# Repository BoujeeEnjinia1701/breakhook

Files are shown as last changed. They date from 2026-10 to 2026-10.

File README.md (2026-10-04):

# BreakHook

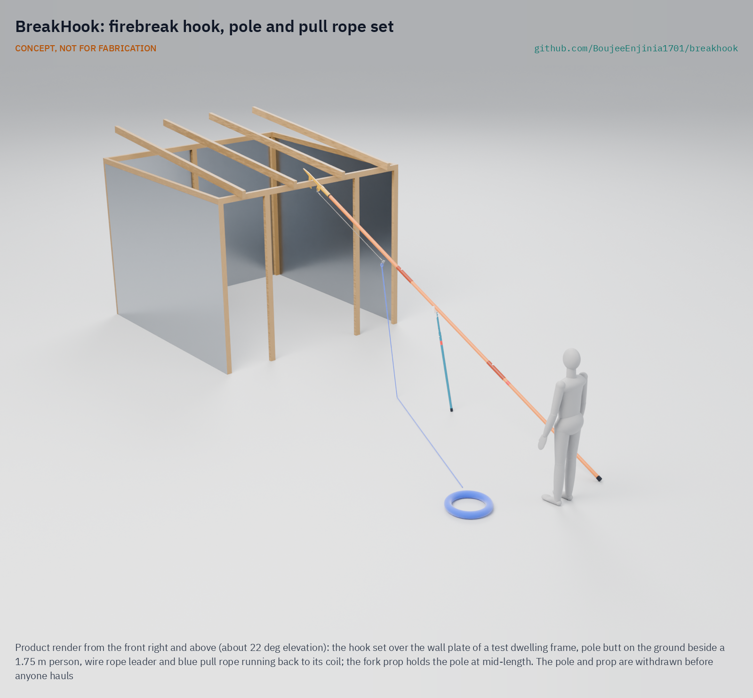
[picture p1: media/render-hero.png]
BreakHook: firebreak hook, pole and pull rope set


     

**Area:** Situational field hardware · **TRL:** 3 of 9 (proof of concept on paper; constructable design) · **Value-engineering target:** USD 2,000; estimated kit cost USD 1,170 · **Difficulty:** 2 of 5

Lets residents pull a shack down from a safe distance to open a firebreak before a fire jumps across.

## Concept rationale

Pulling buildings down to stop a fire is an old method: in 1666 the Mayor of London was ordered to use fire hooks to pull down burning buildings ([London Fire Brigade Museum](https://www.london-fire.gov.uk/museum/london-fire-brigade-history-and-stories/fires-and-incidents-that-changed-history/the-great-fire-of-london/)). Residents of informal settlements do the same today, tearing down structures to make firebreaks ([Ngau and Boit, 2020](https://journals.sagepub.com/doi/10.1177/0956247820924939)). BreakHook gives them the tool for it: a long-reach steel hook on a non-conductive pole with a pull rope. The hook is set on a roof beam or wall frame from a distance, then a group hauls on the rope from well back to bring the structure down.

The value is distance. With a hook and rope, the people pulling stand clear of the fall zone and further from the heat. The kit is simple enough to keep at a community point, needs no power or water, and can be built by a local welder. It is meant as a last-resort tool inside a community fire plan, not a replacement for fire services, detectors or better spacing.

## Burning platform

Stellenbosch University fire engineers report that fires in Cape Town's informal settlements cause up to 115 deaths and destroy up to 4,500 dwellings a year, and that fire can spread between dwellings in under a minute ([Stellenbosch University, 2023](https://www0.sun.ac.za/researchforimpact/2023/10/10/su-fire-engineers-explore-risks-for-humans-and-dwellings/)). The 2017 Imizamo Yethu fire destroyed 2,194 dwellings and displaced more than 9,700 people, despite more than 170 firefighters working for over 13.5 hours ([Imizamo Yethu fire spread analysis](https://www.sciencedirect.com/science/article/abs/pii/S2212420918307623)).

Help often arrives late. A study of Dhaka and Cape Town found average fire service response times of 68 minutes in informal settlements against 28 minutes in formal residential areas, and pathways as narrow as 60 to 90 cm in parts of Dhaka ([Royal Academy of Engineering](https://engineeringx.raeng.org.uk/media/03cd1j4l/engx-a-comparative-study-of-fire-risk-emergence-in-informal-settlements-in-dhaka-and-cape-town-short.pdf)). In Nairobi, over 60 % of surveyed residents said they took part in fire response, including tearing down structures to create firebreaks ([Ngau and Boit, 2020](https://journals.sagepub.com/doi/10.1177/0956247820924939)).

## Where it could be used

### By industry

| Industry | Use |
| --- | --- |
| Community-based disaster risk reduction | A firebreak tool in a community fire kit alongside buckets, extinguishers and alarms |
| Municipal fire services | Equipment for trained community reservists who act before engines arrive |
| Humanitarian shelter and settlement programmes | Pre-positioned kit in dense camps and settlements |
| Red Cross and Red Crescent societies | Part of community fire response training |
| Urban upgrading and re-blocking programmes | Interim measure while spacing and access are improved |

### By country or region

| Country or region | Why it matters there |
| --- | --- |
| South Africa (Western Cape) | Up to 115 deaths and 4,500 dwellings lost to informal settlement fires in Cape Town each year ([Stellenbosch University, 2023](https://www0.sun.ac.za/researchforimpact/2023/10/10/su-fire-engineers-explore-risks-for-humans-and-dwellings/)). |
| South Africa (national) | A Khayelitsha New Year fire destroyed more than 1,000 shacks and displaced over 4,000 people; the city responded with re-blocking to create 3 m gaps ([The New Humanitarian, 2013](https://www.thenewhumanitarian.org/analysis/2013/01/23/south-africa-searches-solutions-shack-fires)). |
| Kenya | In Nairobi's informal settlements, residents tear down structures to create firebreaks while fire engines struggle with narrow access ([Ngau and Boit, 2020](https://journals.sagepub.com/doi/10.1177/0956247820924939)). |
| Bangladesh | The 2017 Korail fire in Dhaka destroyed 4,000 dwellings and displaced about 20,000 people ([Royal Academy of Engineering](https://engineeringx.raeng.org.uk/media/03cd1j4l/engx-a-comparative-study-of-fire-risk-emergence-in-informal-settlements-in-dhaka-and-cape-town-short.pdf)). |

## What sparked the idea

The idea came from two findings read side by side. Stellenbosch fire engineers found that fire can cross from one informal dwelling to the next in under a minute ([Stellenbosch University, 2023](https://www0.sun.ac.za/researchforimpact/2023/10/10/su-fire-engineers-explore-risks-for-humans-and-dwellings/)), while a study in Nairobi found that residents already respond by tearing down structures to make firebreaks, with over 60 % taking part in fire response ([Ngau and Boit, 2020](https://journals.sagepub.com/doi/10.1177/0956247820924939)). People are already doing the one thing that works in those first minutes, with their bare hands, next to the fire.

## Problem

In dense informal settlements, fire can jump from one dwelling to the next in under a minute, long before fire engines arrive. Residents already pull structures down to stop it, but they do it by hand, close to the flames.

Full problem statement: [docs/01-problem.md](docs/01-problem.md)

## Concept

A long-reach steel hook on a non-conductive pole with a pull rope; residents set it on a shack's roof beam or wall frame from a safe distance and haul together to pull the shack down, opening a firebreak ahead of a spreading fire.

Full design precis: [docs/02-concept.md](docs/02-concept.md) · Requirements: [docs/03-requirements.md](docs/03-requirements.md) · Calculations: [docs/04-calcs/01-sizing.md](docs/04-calcs/01-sizing.md) · Prototype build plan: [docs/05-build-plan.md](docs/05-build-plan.md) · Design decisions: [docs/06-design-decisions.md](docs/06-design-decisions.md) · General arrangement: [cad/drawings/BHK-DWG-001.pdf](cad/drawings/BHK-DWG-001.pdf) · 3D model: [media/viewer.html](media/viewer.html)

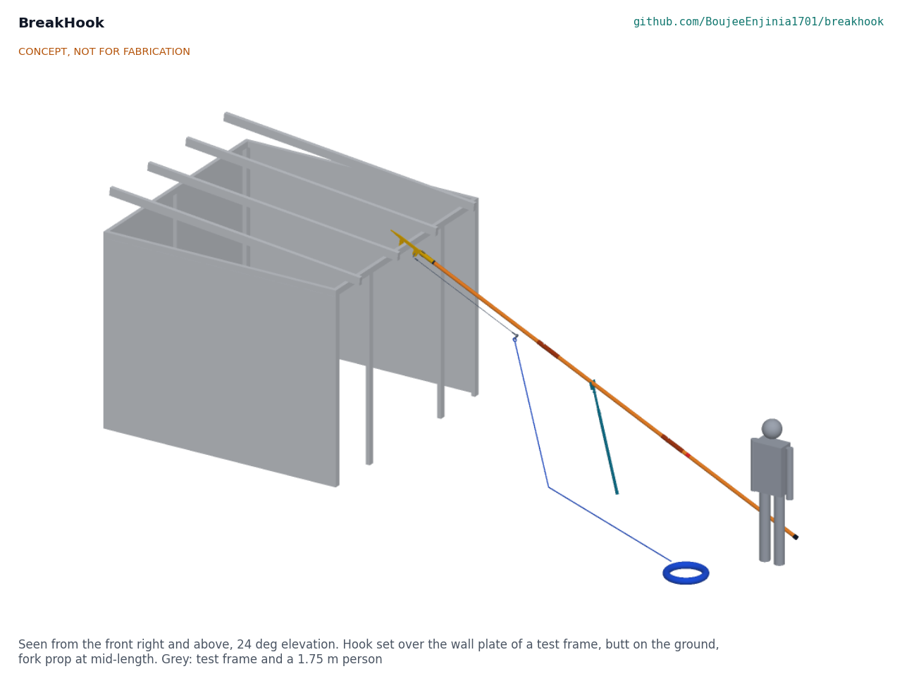
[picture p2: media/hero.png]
Concept: the hook set over the wall plate of a test frame, 1.75 m person for scale


Key figures at TRL 3 (BHK-CAL-001): working pull 3 kN with every hook head proof-loaded to 6 kN; about ten haulers, the nearest 10.8 m from the wall; pole and hook head 7.82 kg; 3.67 m of insulated pole below the hook head; deployment in about 3 minutes from a store within 100 m. The fibreglass pole rests on a light fork prop at mid-length while the hook is set, which cuts the droop at the hook from about 0.66 m to 0.27 m; placement is the main thing a TRL 4 trial must confirm.

## Key components

- Hook head: profile-cut 10 mm steel plate welded into a slotted steel socket
- Non-conductive pole: three 1.8 m sections of foam-filled, certified fibreglass tube with bonded sleeves and nylon pins
- Wire rope leader and rated shackles
- Pull rope: 25 m of 12 mm polyester with ten hauling toggles on prusik cords
- Fall zone tape and stakes
- Locked, sealed wall rack
- Check card and rigger gloves

## Building the prototype

The first prototype is one set and its rack, built by a local welder and a small workshop: the hook plate is cut from 10 mm steel and welded into a slotted socket, the fibreglass pole sections are cut, drilled and joined with glued sleeves and nylon pins, and the rope system is bought from a rigging shop. Every component has a making sketch and every assembly step a picture. Each hook head is proof-loaded to 6 kN before it is issued. The plan is a plan, not yet built; building and testing to it is TRL 4 work.

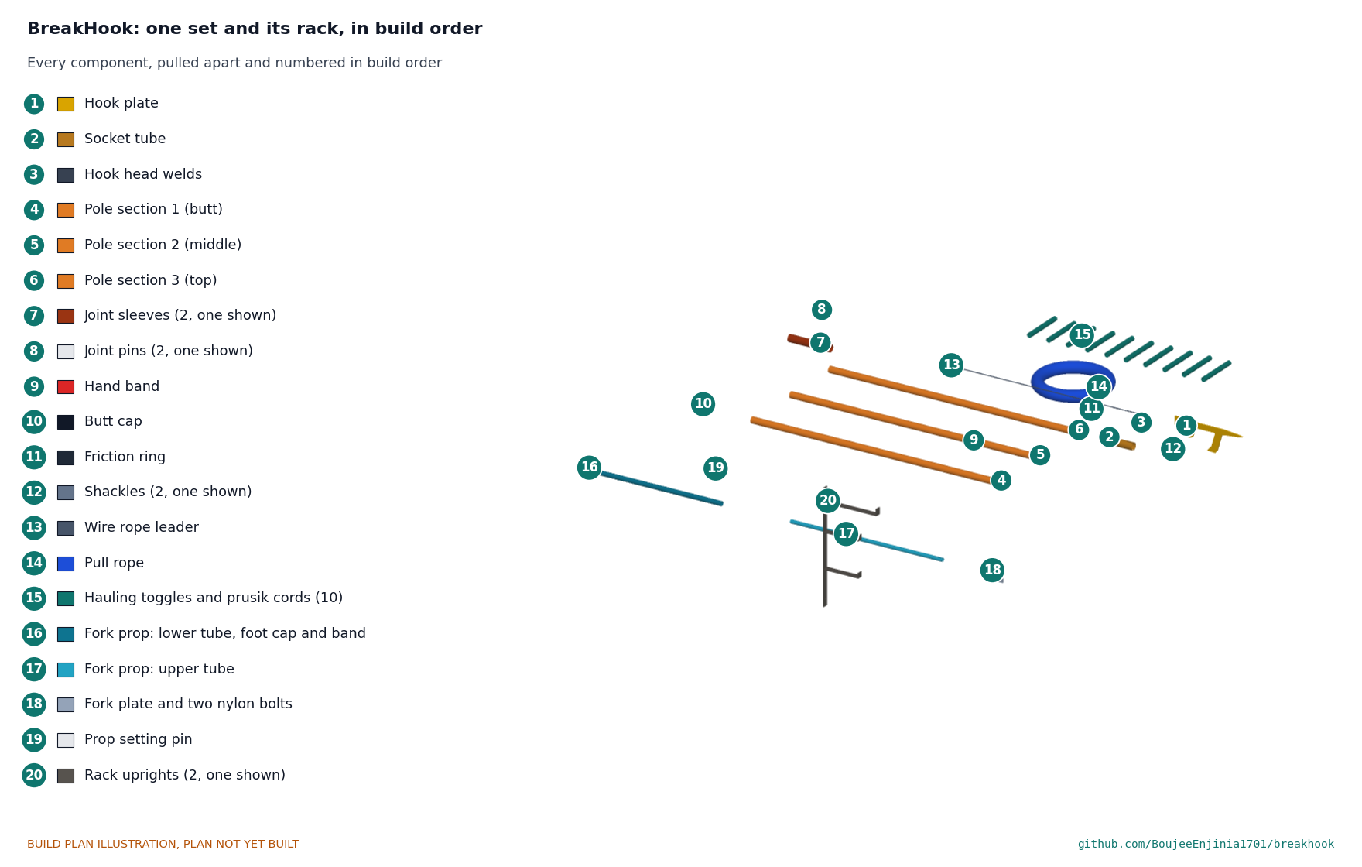
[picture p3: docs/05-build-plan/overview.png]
Every component, pulled apart and numbered in build order


## Safety

> Published as an open engineering reference, not certified equipment. Use only within a community fire plan agreed with the local fire service.
>
> Never pull a structure until two people have confirmed it is empty of people and animals.
>
> Never raise the pole within 3 m of any overhead or informal electrical line. The pole's insulated length is a second line of defence only; the hook, leader and shackles are metal and a wet rope conducts.
>
> Withdraw the pole and leave the fall zone before anyone hauls. Haulers stand at least 10 m from the wall and at least 1.5 times the structure's height away, on the side away from the fire, in gloves.
>
> Proof-load every hook head, leader and shackle set to 6 kN before issue and after any seal break; take a bent, kinked or frayed part out of service.
>
> Use only on free-standing, single-storey dwellings or end units, never on shared-wall rows, multi-storey or masonry buildings.
>
> Pulling a home down destroys it. The decision belongs to the community and its fire plan, not to the tool.
>
> This design is published as an open engineering reference. It is a TRL 3 concept, not for fabrication, and it is not certified equipment.

## Repository layout

| Folder | Contents |
| --- | --- |
| `docs/` | Problem, concept, requirements, calculations and design decisions |
| `cad/src/` | build123d Python source, the source of truth for all geometry |
| `cad/step/`, `cad/stl/` | Exported models for FreeCAD, other CAD tools and printing |
| `cad/drawings/` | 2D sketches and dimensioned drawings |
| `bom/` | Bill of materials |
| `electronics/` | KiCad schematics and PCB layouts |
| `firmware/` | Microcontroller code |
| `media/` | Renders, perspectives and photos |
| `build-log/` | Dated prototyping notes |

## Documentation

Controlled documents follow the portfolio [documentation standard](.kit/STANDARDS.md). Each carries a document ID (BHK-PRC-001 for the precis), a version and a revision history. Branded PDFs are built with `python .kit/render.py` and attached to GitHub Releases when a document is tagged, for example `BHK-PRC-001/v1.0`.

## Credits

Designed by Amish Chadha at Design Molecule Labs. See [CONTRIBUTORS.md](CONTRIBUTORS.md) for roles. To cite this design, use [CITATION.cff](CITATION.cff) (GitHub shows it as "Cite this repository").

AI assistance (Claude) was used to accelerate prototype documentation and first-pass research. Design direction and all decisions are Amish Chadha's, recorded in this repository's decision records (`docs/decisions/`).

## Licenses

- **Hardware** (CAD, drawings, BOM, electronics): [CERN-OHL-S v2](LICENSE)
- **Software** (firmware, scripts, notebooks): [MIT](LICENSE-SOFTWARE)

A project of the [Design Molecule](https://designmolecule.com) lab.

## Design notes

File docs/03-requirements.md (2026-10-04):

---
doc_id: BHK-REQ-001
title: BreakHook requirements
project: BreakHook
doc_type: Requirements
version: "0.5"
status: Draft
date: '2026-10-03'
author: Amish Chadha
license: CERN-OHL-S-2.0
revisions:
- version: "0.1"
  date: '2026-09-30'
  author: Amish Chadha
  change: Initial scaffold
- version: "0.2"
  date: '2026-10-03'
  author: Amish Chadha
  change: TRL 2 and TRL 3; targets confirmed under Amish's 2026-10-03 pre-approval (BHK-DDR-001); R11 to R14 added; status from BHK-CAL-001
- version: "0.3"
  date: '2026-10-03'
  author: Amish Chadha
  change: 'Fork prop at mid-length added under Amish''s decision 6A (BHK-DDR-003); status of R1, R5, R8, R10 and R14 updated from BHK-CAL-001 v0.2; targets unchanged'
- version: "0.5"
  date: '2026-10-03'
  author: Amish Chadha
  change: "R1 stand-off wording restated after Amish's round-2 decision 5A (BHK-DDR-004): prop holder at 2.9 m during placement only; confirmed in the TRL 4 reach trial"
---

# BreakHook requirements

Fourteen requirements, each with a measurable target. At TRL 3 they are checked by calculation (BHK-CAL-001); verification by test is TRL 4 work. Ten are met on paper; R1's hook placement is met with the fork prop, and the prop holder's 2.9 m placement-only stand-off is accepted by Amish (the TRL 4 reach trial confirms it); R6 and R13 are met with no margin, and R7 and R9 can only be shown by trial.

On 2026-10-03 Amish chose option A on every requirement decision put to him ("1A 2A 3A 4A 5A 6A 7A 8A 9A 10A 11A"). For BreakHook, decision 6A adds a light fork prop that supports the pole at mid-length, carried separately so the pole and hook head stay under 8 kg (BHK-DDR-003). No target changes.

> **Safety:** BreakHook pulls a structure down with a rope. Every requirement assumes the safety rules of BHK-PRC-001: the dwelling is checked empty, the fall zone is clear and taped, nobody is within 3 m of an overhead line, and the pole is withdrawn before the haul. A requirement is never met by relaxing those rules.

Table 1. Requirements

| ID | Requirement | Target | Verification (TRL 4 or later) | Status at TRL 3 |
| --- | --- | --- | --- | --- |
| R1 | Reach of the hook | Places the hook at a height of 3 m (10 ft) with the pole hands (front hand) 4 m (13 ft) from the wall; the prop holder may stand 2.9 m from the wall during placement only (about 25 s) and withdraws with the pole before the haul | Reach trial on the test frame, with the prop holder's distance from the wall and the time at 2.9 m measured | Hook placement met on paper with the fork prop at mid-length: droop about 0.27 m (0.66 m by hand), rear hand 5.06 m from the wall (CAL [F13] to [F20]); the prop holder stands about 2.9 m from the wall for the placement only (about 25 s), accepted by Amish (5A, round 2), and withdraws with the pole; the TRL 4 reach trial confirms it |
| R2 | Hook and rope working pull | 3 kN (675 lbf) working, every hook head proof-loaded to 6 kN (1,350 lbf) before issue | Proof load with CalRig or at a rigging shop | Met: least factor 2.3 on yield at proof (CAL [C3]) |
| R3 | Hauling distance | Nearest hauler at least 1.5 times the structure height from the wall, and never closer than 10 m | Field layout check | Met: 10.8 m (CAL [B1]) |
| R4 | Pole electrical insulation | The handled length is foam-filled fibreglass carrying the maker's dielectric test certificate to ASTM F711 for live-line tool tube | Certificate check on receipt; no field electrical test | Met by specification; confirm the certificate when bought |
| R5 | Pole and hook mass | 8 kg (18 lb) or less | Weigh | Met: 7.82 kg (CAL [F10]); the 1.08 kg fork prop is carried separately (CAL [F22]) |
| R6 | Deployment time | From store to hook set in 3 min or less with four people, store within 100 m | Timed drill | Met on estimate with no margin: 3.0 min (CAL [I1]) |
| R7 | Time to bring down a test dwelling frame | Under 2 min from hook set, single-storey timber and sheet frame | Timed trial on a purpose-built test frame, never an occupied area | Estimate only: about 1.2 min (CAL [I2]) |
| R8 | Section length for narrow paths | No piece longer than 2 m (6.5 ft) | Measure | Met: 1.95 m (CAL [F12]); fork prop 1.24 m closed |
| R9 | Storage life | No loss of function after 12 months in the rack | Inspection and repeat proof load after exposure | Not verifiable at TRL 3; material choices only |
| R10 | Cost | Community kit (two sets, rack, cards, tape, gloves) against the USD 2,000 value-engineering target | Costed bill of materials | USD 1,170 with two fork props, USD 830 under the target |
| R11 | Beam size the hook takes | Timber up to 100 mm deep and 120 mm wide | Fit check on timber offcuts | Met: 117 mm deep, 128 to 150 mm wide (CAL [C8] to [C10]) |
| R12 | Pole release | The pole comes free of the hook head with a pull of about 50 N, so it is withdrawn before the haul | Push-off check with a spring balance | Met by design; set by trial (CAL [G1]) |
| R13 | Effort per hauler | 300 N or less per person at the working pull | Count of toggles and crew | Met at the limit: ten haulers at 300 N (CAL [A5]) |
| R14 | Insulated length | At least 3.0 m with no metal between the hook head and the hand band | Measure | Met: 3.67 m (CAL [H1]); 3.27 m from the socket mouth to the prop holder's hand band (CAL [H3]) |

## Requirements at risk

- **R1:** the fibreglass tube is flexible. The fork prop at mid-length cuts the droop from about 0.66 m to 0.27 m and takes the lift off the pole team, but its holder stands about 2.9 m from the wall while the hook is set, for about 25 s. Amish accepted that for placement only (round 2, 5A: "i agree with all the 46 recommendations you provided. please proceed.") and R1 is restated accordingly: the 4 m applies to the pole hands, and the holder withdraws with the pole before the haul. The reach trial at TRL 4 confirms the distance and the time; the measured droop is an item to confirm.
- **R6 and R13:** both sit exactly on their targets, so a slower carry or a weaker crew misses them. The community fire plan sets the store within 100 m and calls for ten haulers.
- **R5:** 0.18 kg of margin; heavier paint or a thicker tube wall would use it up.

## Assumptions

- Typical dwellings are single storey with timber or light steel frames that a crew can pull down with a hook (BHK-CAL-001, assumption 1).
- Communities already accept firebreaks as a response and can agree rules on use; the kit's governance (sealed rack, named keyholders, use log) supports those rules but does not replace them.
- The fire service supports community action in the first minutes.
- Test frames are built to represent real dwellings; occupied homes are never used for tests.

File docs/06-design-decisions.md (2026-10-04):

---
doc_id: BHK-DEC-001
title: BreakHook design decisions register
project: BreakHook
doc_type: Design decisions register
version: "0.3"
status: Draft
date: '2026-10-03'
author: Amish Chadha
license: CERN-OHL-S-2.0
revisions:
- version: "0.1"
  date: '2026-10-03'
  author: Amish Chadha
  change: Register opened at TRL 3; all decisions made under Amish's 2026-10-03 pre-approval
- version: "0.2"
  date: '2026-10-03'
  author: Amish Chadha
  change: Fork prop at mid-length decided by Amish (6A, BHK-DDR-003); new open decision on the prop holder's distance from the wall; value engineering re-costed
- version: "0.3"
  date: '2026-10-03'
  author: Amish Chadha
  change: "Open decision 1 (prop holder distance) decided, round 2, 5A (BHK-DDR-004); no open decisions"
---

# BreakHook design decisions register

Every design decision still to be made, and every decision made, in one place. Each decision is argued in full in its decision record under `docs/decisions/`; this register is the index Amish works from.

> **Safety:** Decisions that touch safety (the pole withdrawn before the haul, the 3 m overhead line rule, hauling distance, proof loading, scope limited to free-standing single-storey dwellings) took the conservative option. Each record states what evidence would relax it.

## Open decisions

None. Open decision 1 (where the prop holder stands while the hook is set) was decided by Amish on 2026-10-03: 2.9 m for placement only; see Decisions made and BHK-DDR-004.

## To confirm when parts are bought

| # | What to confirm | Why it matters | Source |
| --- | --- | --- | --- |
| 1 | The pole tube carries the maker's dielectric test certificate to ASTM F711 for live-line tool tube, and its stated test voltage | R4 is met only by this certificate | BHK-DDR-001, decision 1 |
| 2 | Actual outside diameter of the 44.5 mm tube and bore of the 50.8 x 3.2 sleeve tube; how much sanding gives a 0.2 mm slip fit | Nominal sizes give no clearance | BHK-DDR-002 |
| 3 | Stiffness of the tube from the maker's data (E along the tube); measured hook droop at 25° on the fork prop | The 0.27 m droop estimate with the prop (0.66 m by hand) uses E = 20 GPa | BHK-CAL-001 [F8], [F16] |
| 9 | Outside diameter of the 25.4 x 3.2 prop tube and bore of the 32 x 3 tube; the upper tube slides freely | 0.3 mm radial clearance on nominal sizes | BHK-DDR-003 |
| 4 | Bore of the 50.8 x 2.0 steel socket tube (46.8 mm nominal) | Sets the 1.15 mm clearance and the friction ring wrap | BHK-DDR-002 |
| 5 | Turns of rubber tape that give a 50 N release | R12 | BHK-CAL-001 [G1] |
| 6 | Shackle jaw width at least 12 mm and pin no larger than 12 mm | Fits the 10 mm plate and the 13 mm hole | bom/bom.csv line 11 |
| 7 | Breaking strengths on the rope, leader and cord labels | Factors in BHK-CAL-001 section E | bom/bom.csv lines 12, 13, 15 |
| 8 | Weighed mass of the pole and hook head | R5 has 0.18 kg of margin | BHK-CAL-001 [F10] |

## Value engineering

Value-engineering target: USD 2,000 (a hypothetical control target, not a limit). Estimated cost of the constructable design: USD 1,170 (USD 830 under the target), including two fork props at USD 36 each. Main cost drivers and savings worth trying:

- Certified, foam-filled pole tube: USD 270 for six sections (25 % of the kit). A bulk order across several communities, or a local pultruder, is the main saving; uncertified tube is not an option (R4).
- Pull ropes: USD 140. Polyester double braid could give way to a cheaper three-strand polyester of the same breaking strength, with a check on hand grip and prusik hold.
- Hook head fabrication: USD 80 of welder time. Plasma-cut plates in a batch of ten would roughly halve it.
- Gloves, proof loading and the rack are each about USD 50 to 60 and are kept for safety and governance.

## Decisions made

| Date | Decision | Decided by | Record |
| --- | --- | --- | --- |
| 2026-10-03 | Pole: foam-filled, electrical-grade fibreglass tube 44.5 x 3.2 with an ASTM F711 certificate, three 1.8 m sections | Amish Chadha, pre-approval: "I pre-approve the batch runs along with any recommendations you come up with." | [BHK-DDR-001](decisions/0001-trl2-review-decisions.md), decision 1 |
| 2026-10-03 | The pole is withdrawn before the haul; the rope alone pulls | As above | BHK-DDR-001, decision 2 |
| 2026-10-03 | Hook head cut from 10 mm plate, welded in a slotted socket; WLL 3 kN, proof 6 kN before issue | As above | BHK-DDR-001, decision 3 |
| 2026-10-03 | Wire rope leader, rated shackles, 25 m polyester pull rope | As above | BHK-DDR-001, decision 4 |
| 2026-10-03 | Crew of four to deploy and about ten haulers on toggles; no pulley in the base kit | As above | BHK-DDR-001, decision 5 |
| 2026-10-03 | Nearest hauler at 1.5 x the dwelling height and never closer than 10 m | As above | BHK-DDR-001, decision 6 |
| 2026-10-03 | Never raise the pole within 3 m of an overhead or informal line | As above | BHK-DDR-001, decision 7 |
| 2026-10-03 | Hand band and 3.0 m minimum insulated length | As above | BHK-DDR-001, decision 8 |
| 2026-10-03 | Kit governance: locked, sealed rack, two keyholders, use log, pulls only during a fire under the fire plan | As above | BHK-DDR-001, decision 9 |
| 2026-10-03 | Firebreak at least two dwellings ahead of the fire | As above | BHK-DDR-001, decision 10 |
| 2026-10-03 | Free-standing dwellings and end units only | As above | BHK-DDR-001, decision 11 |
| 2026-10-03 | Monthly check card; fresh proof load after a seal break | As above | BHK-DDR-001, decision 12 |
| 2026-10-03 | First co-design candidate to approach: City of Cape Town Fire and Rescue Service reservists (Western Cape), then Kenya Red Cross Society (not agreed) | As above | BHK-DDR-001, decision 13 |
| 2026-10-03 | Requirements updated, R11 to R14 added | As above | BHK-DDR-001, decision 14 |
| 2026-10-03 | `budget_usd` stays at USD 2,000 as the value-engineering target | Amish Chadha: "I also accept any cost overruns or variations from the assumed scope cost." | BHK-DDR-001, decision 15 |
| 2026-10-03 | Design for construction: plate hook in slotted socket, slip-fit pole with friction ring, bonded sleeves and nylon pins, rope tab with shackle and leader, S355 plate with 36 mm shank and 48 mm arm, prusik toggles, welded wall rack | Amish Chadha, pre-approval as above | [BHK-DDR-002](decisions/0002-design-for-construction.md) |
| 2026-10-03 | R1: add a light fork prop that supports the pole at mid-length, carried separately so the pole and hook head stay under 8 kg (decision 6A) | Amish Chadha: "1A 2A 3A 4A 5A 6A 7A 8A 9A 10A 11A" | [BHK-DDR-003](decisions/0003-fork-prop.md) |
| 2026-10-03 | 5A (round 2): prop holder accepted at 2.9 m from the wall during placement only (about 25 s); the holder withdraws with the pole; R1's stand-off wording restated (4 m for the pole hands); confirmed in the TRL 4 reach trial. No design change | Amish: "i agree with all the 46 recommendations you provided. please proceed." | BHK-DDR-004 |

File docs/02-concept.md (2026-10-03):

---
doc_id: BHK-PRC-001
title: BreakHook design precis
project: BreakHook
doc_type: Precis
version: "0.3"
status: Draft
date: '2026-10-03'
author: Amish Chadha
license: CERN-OHL-S-2.0
revisions:
- version: "0.1"
  date: '2026-09-30'
  author: Amish Chadha
  change: Initial scaffold
- version: "0.2"
  date: '2026-10-03'
  author: Amish Chadha
  change: TRL 2 and TRL 3 on the constructable design; decisions under Amish's 2026-10-03 pre-approval (BHK-DDR-001, BHK-DDR-002); numbers from BHK-CAL-001
- version: "0.3"
  date: '2026-10-03'
  author: Amish Chadha
  change: Fork prop at mid-length added under Amish's decision 6A (BHK-DDR-003); droop and cost updated from BHK-CAL-001 v0.2
---

# BreakHook design precis

Lets residents pull a shack down from a safe distance to open a firebreak before a fire jumps across.

## Summary

BreakHook is a steel hook on a 5.9 m fibreglass pole, with a wire rope leader and a 25 m pull rope. A team of two sets the hook over a wall plate or rafter, the pole resting on a light fork prop at mid-length, then withdraws the pole and prop and steps clear; a crew of about ten on hauling toggles, at least 10 m back, pulls the dwelling down away from the fire's path. A community kit holds two sets in a locked, sealed wall rack with check cards, fall zone tape and gloves. The kit's estimated cost is USD 1,170 against a USD 2,000 value-engineering target, and the pole and hook head weigh 7.82 kg.

Figure 1. BreakHook set over the wall plate of a test frame, with a 1.75 m person for scale

*Figure 1. Concept render: the hook over the wall plate of a test dwelling frame, pole butt on the ground. Grey parts are context.*

## How it works

1. **Check.** The caller works through the check card: the dwelling is empty of people and animals (two people confirm), there is no overhead or informal wiring within 3 m of where the pole will go, the dwelling is free-standing or the end of a row, and it is at least two dwellings ahead of the fire.
2. **Mark.** Two people tape off a fall zone in front of the dwelling, at least as deep as the dwelling is tall, plus the hauling lane.
3. **Set.** The pole team joins the three sections (two nylon pins), pushes the hook head onto the tip, and lifts the hook over the wall plate or a rafter end. The front person lifts, the rear person holds the butt down, both hands below the red band.
4. **Withdraw.** A firm 50 N pull frees the pole from the hook head. The pole team carries the pole back out of the fall zone.
5. **Haul.** The pull rope runs from the hook head, through a short steel wire leader, back to the crew. Ten haulers on toggles, the nearest 10.8 m from the wall, take up the slack and pull on the caller's word. The frame racks or tips toward them and falls inside the taped zone.
6. **Recover.** The hook is pulled out of the debris by the rope when it is safe to approach.

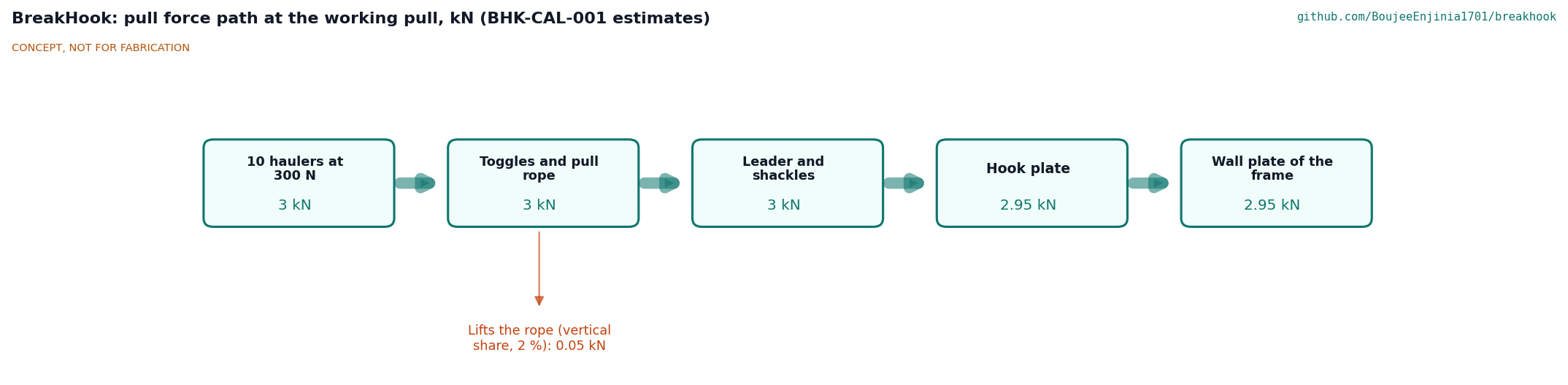
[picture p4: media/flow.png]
Figure 2. Pull force path at the working pull


*Figure 2. Force path at the 3 kN working pull (estimates from BHK-CAL-001).*

## Main components

Table 1. Components of one set (numbers match bom/bom.csv)

| BOM | Component | What it is |
| --- | --- | --- |
| 1 | Hook plate | 10 mm S355 plate, profile cut: spike, 36 mm shank, arm raked back 17° that hangs 117 mm below the shank, rope tab with a 13 mm shackle hole |
| 2 | Socket tube | 50.8 x 2.0 steel tube, 180 long, slotted across one end for the plate |
| 3 | Welding and finishing | Four 6 mm fillet welds; zinc-rich primer and yellow paint; WLL 3 kN and serial stamped |
| 4 | Pole sections (3) | Foam-filled, electrical-grade fibreglass tube 44.5 x 3.2, 1.8 m each, with the maker's ASTM F711 certificate |
| 5, 6, 7 | Joints (2) | Fibreglass sleeve 50.8 x 3.2 x 300 bonded to the lower section; nylon 10 mm pin through the upper section |
| 8, 9, 10 | Friction ring, hand band, butt cap | Rubber tape ring for a 50 N release; red band 1.55 m from the butt; rubber cap |
| 11, 12 | Shackles and leader | Two rated 3/8 in bow shackles; 1.5 m of 6 mm galvanised wire rope with thimble eyes |
| 13 | Pull rope | 25 m of 12 mm polyester double braid, 25 kN or more, spliced eye |
| 14, 15 | Hauling toggles | Ten 300 mm fibreglass toggles on 6 mm prusik cords, 1 m apart from 11 m |

The community kit adds a wall rack (BOM 16, 17), paint (18), lock cable and numbered seals (19, 20), fall zone tape and stakes (21, 22), check cards (23), rigger gloves (24) and a proof load for each hook head (25).

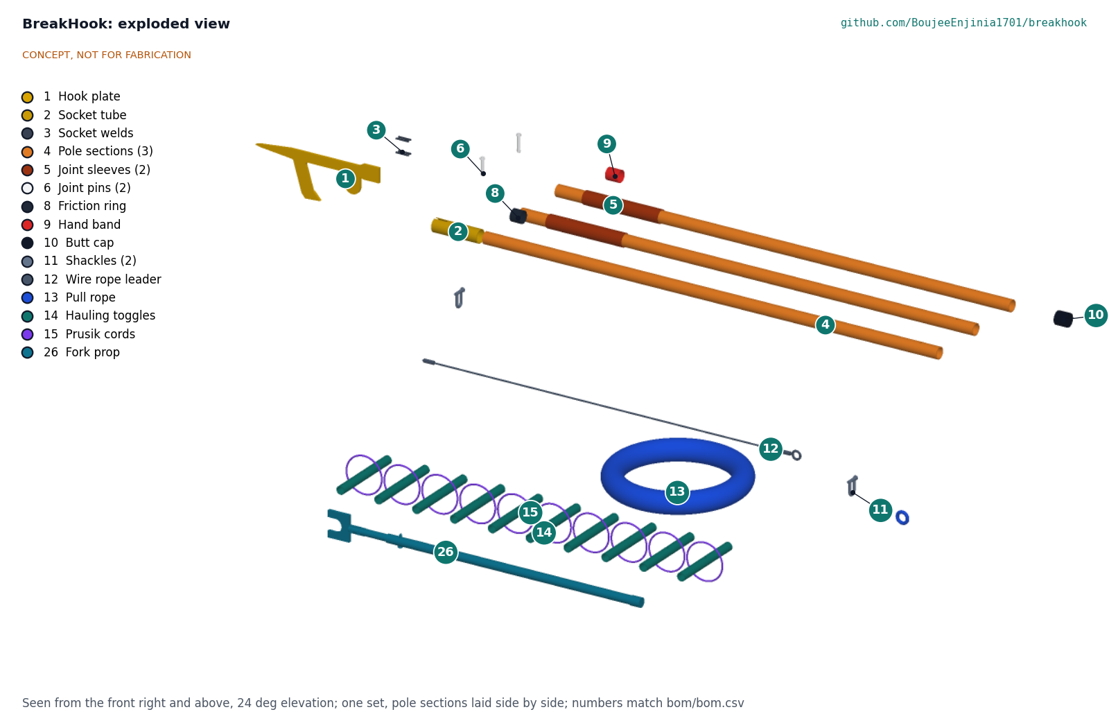
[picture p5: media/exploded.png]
Figure 3. Exploded view of one set


*Figure 3. One set pulled apart; numbers match bom/bom.csv.*

## Key design choices

All made on 2026-10-03 under Amish's pre-approval; argued in BHK-DDR-001 (TRL 2 review) and BHK-DDR-002 (design for construction).

- **The pole places, the rope pulls.** The pole slides off the hook head and is withdrawn before the haul, so nobody holds anything inside the fall zone and the pole is never loaded by the pull.
- **Hook profile cut from one plate.** No forging; any welder with a plasma cutter, or a drill and grinder, can make it. The rope tab puts the pull in line with the arm, so the shank carries almost pure tension.
- **Foam-filled, certified fibreglass tube.** Electrical-grade tube is only insulating if its bore stays dry, hence foam fill, sealed ends, external sleeves and nylon pins. The pole is still never used within 3 m of overhead lines.
- **Wire rope leader.** The first 1.5 m from the hook is steel so heat and sheet edges at the dwelling do not cut the polyester rope.
- **No pulley in the base kit.** Ten toggles on prusik cords instead; a pulley needs an anchor that settlements rarely have.
- **Governance built into storage.** Locked rack, numbered seal, two keyholders and a use log answer the misuse concern in BHK-PRB-001.

## Numbers from the TRL 3 calculations

Table 2. Key figures (BHK-CAL-001)

| Quantity | Value |
| --- | --- |
| Pull to tip or rack the target dwelling | 2.15 to 3.0 kN (estimate) |
| Working pull, proof load | 3 kN, 6 kN |
| Haulers at 300 N | 10 |
| Nearest hauler from the wall | 10.8 m |
| Least factor on yield in the hook plate at proof | 2.3 (100 mm deep beam) |
| Rope, leader and shackle factors at the working pull | 7.5, 6.0, 3.3 |
| Pole and hook head mass | 7.82 kg |
| Lift and hold-down forces for the pole team | 252 N and 168 N |
| Hook droop at 25° | about 0.27 m on the fork prop (0.66 m held by hand) |
| Insulated length | 3.67 m |
| Deployment within 100 m of the store | 3.0 min (estimate) |
| Value-engineering target | USD 2,000. Estimated cost of the constructable design: USD 1,170 (USD 830 under the target) |

## Patent design-arounds

From the preliminary patent, trademark and prior-art screen (not legal advice), all kept in the constructable design:

- Cite the historical fire-hook lineage; no live patent found close to the concept.
- Non-conductive tail on the pole: 3.67 m of foam-filled fibreglass with no metal below the hook head.
- Empty-shack check protocol before any pull: the first item on the check card.
- Name changed from GapHook to BreakHook to avoid GapHook Oy, a Finnish software company.
- Watch items from the preliminary screen, both answered in the design: overhead lines (3 m rule, insulated length) and the structure falling toward users (pole withdrawn, haulers beyond the fall zone).

## Shared blocks

- CalRig proof-load for the hook head, leader and shackles (6 kN for 1 minute before issue).

## Relationship to other lab projects

BreakHook is a Design Molecule Labs situational field hardware design. Its proof load uses the lab's CalRig rig where one is available; otherwise a rigging shop does it.

## Safety

> **Safety:** The hazards are a falling structure, a dwelling that is not empty, electrical wiring, a rope system failing under load, heat and smoke, and crowds. The safety stops are fixed by design and by the check card:
>
> - Never pull until two people have confirmed the dwelling is empty of people and animals.
> - Never raise the pole within 3 m of any overhead or informal line. The pole's insulated length is a second line of defence only; the hook, leader and shackles are metal and a wet rope conducts.
> - The pole is withdrawn and the pole team is out of the fall zone before anyone hauls.
> - Haulers stand at least 10 m from the wall and at least 1.5 times the dwelling's height away, on the side away from the fire, in gloves; nobody stands beside the rope line within the fall zone.
> - Every hook head, leader and shackle set is proof-loaded to 6 kN before issue and after any seal break; a bent hook, kinked leader or frayed rope is taken out of service.
> - Only free-standing dwellings or end units; never multi-storey or masonry buildings.
> - Pulling a home down destroys it. The decision belongs to the community and its fire plan, not to the tool.
>
> This design is published as an open engineering reference. It is not certified equipment.

## Open questions

None open. Every TRL 1 question was decided under Amish's 2026-10-03 pre-approval; facts that can only be settled with real parts are listed in the design decisions register (BHK-DEC-001).

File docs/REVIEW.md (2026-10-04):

# Review note: BreakHook

## Session 2026-09-30: scaffolded

### What was done

- Repository created from kit 1.6.0 at TRL 1, target TRL 2.
- `docs/01-problem.md` (BHK-PRB-001 v0.1): problem with cited evidence, users, environment, constraints, prior work, open questions.
- `docs/02-concept.md` (BHK-PRC-001 v0.1): how it works, components, patent design-arounds, shared blocks, safety.
- `docs/03-requirements.md` (BHK-REQ-001 v0.1): 10 proposed requirements.
- `README.md` with concept rationale, burning platform, where it could be used, and what sparked the idea.

### Next

- Run `/populate` to bring the repo to a strong TRL 2 with concept media.

## Session 2026-10-03: TRL 2 (/populate), run as part of /to-trl3 on kit 1.7.0

Amish Chadha, 2026-10-03: "start with the first 14 repos from the list of 29 projects. I pre-approve the batch runs along with any recommendations you come up with. I also accept any cost overruns or variations from the assumed scope cost." On that basis every recommendation in this note is recorded as decided, not proposed.

### What was done

- Kit 1.7.0 installed (`.kit/`, `.claude/commands/`, root `CLAUDE.md` replaced by `.kit/CLAUDE.md`; `.kit/PHASE.yaml` as installed).
- Problem statement BHK-PRB-001 v0.2: co-design candidate named, the five TRL 1 questions answered, safety section.
- Requirements BHK-REQ-001 v0.2: R1 to R10 made measurable, R11 to R14 added (beam size, pole release, effort per hauler, insulated length).
- Precis BHK-PRC-001 v0.2: how it works in six steps, components, choices, numbers, safety.
- Massing model and concept media. The TRL 2 massing model was replaced in the same session by the constructable model, so every file in `media/` comes from `cad/src/model.py` (see the TRL 3 section).
- BOM with 25 priced lines (`bom/bom.csv`).

### Results at TRL 2

- The pull needed to bring down the target dwelling is 2.15 to 3.0 kN, so the working pull of 3 kN in R2 stands, but it needs about ten haulers, not four. R6's four people deploy the kit; the hauling crew comes from residents present.

### Decisions made under the pre-approval (BHK-DDR-001)

Fifteen decisions, all in `docs/decisions/0001-trl2-review-decisions.md` and the register `docs/06-design-decisions.md`: foam-filled, certified fibreglass pole; pole withdrawn before the haul; plate hook in a welded socket, WLL 3 kN, proof 6 kN; wire rope leader, rated shackles and polyester pull rope; ten haulers on toggles and no pulley; haulers at 1.5 x height and never closer than 10 m; never within 3 m of overhead lines; hand band and 3.0 m insulated length; locked, sealed rack with two keyholders and a use log; firebreak two dwellings ahead; free-standing and end units only; monthly checks; first co-design candidate (City of Cape Town Fire and Rescue Service reservists, then Kenya Red Cross Society, neither agreed); requirement updates; `budget_usd` unchanged.

### Safety concerns

- Structure collapse, occupied dwellings, electrical wiring, rope system failure, heat and crowds. Each safety-related decision took the conservative option and states what evidence would relax it.

## Session 2026-10-03: TRL 3 (/advance-trl3 and /build-plan)

### What was done

- Calculation note BHK-CAL-001 v0.1 (`docs/04-calcs/01-sizing.md`), script `docs/04-calcs/sizing.py`, results `docs/04-calcs/results.csv`.
- Parametric build123d model `cad/src/model.py` with `--check` (overlaps, fits, masses); STEP in `cad/step/` (assembly, hook head, hook plate, socket, pole section, sleeve, toggle, rack upright) and STL in `cad/stl/` (hook head, toggle).
- General arrangement BHK-DWG-001 Rev P1 (`cad/src/sheets.py`): set at 1:50 with section lengths, detail A (hook head) and detail B (pole joint) at 1:5.
- Concept media regenerated from the model (`cad/src/concept_media.py`): hero (hook over a test frame, 1.75 m figure), exploded, flow (force path), concept blueprint BHK-DWG-010, model.glb and viewer.html (meshed at 1 mm and 0.35 rad, colours kept).
- Design made constructable (decision record BHK-DDR-002); `design_state: constructable`.
- Build plan BHK-BLD-001 (`docs/05-build-plan.md`) with pictures from `cad/src/build_plan_media.py`: overview, six making sketches (BHK-DWG-101 to 106), eight joint close-ups and fourteen step pictures.
- Design decisions register BHK-DEC-001 (`docs/06-design-decisions.md`).
- Appearance model `cad/src/product_model.py` (hero, exploded and detail views; mannequin for scale) and render scenes exported to `/home/claude/renders/breakhook` for photoreal rendering on Amish's Mac.
- `project.yaml` at trl 3, trl_target 3, with trl_evidence; README leads with `media/render-hero.png` (made on the Mac), adds the links line, key figures and "Building the prototype".

### Key results (BHK-CAL-001)

- Working pull 3 kN; proof 6 kN. Least factor on yield in the hook plate at proof 2.3 (100 mm beam); rope 7.5, leader 6.0, shackle 3.3 at the working pull.
- Ten haulers at 300 N; nearest 10.8 m from the wall (R3 needs 4.5 m).
- Pole and hook head 7.82 kg (R5: 8 kg). Pole team of two: 252 N lift, 168 N hold-down.
- Insulated length 3.67 m (R14: 3.0 m).
- Deployment 3.0 min within 100 m of the store (R6: 3 min); pull 1.2 min (R7, estimate).
- Value-engineering target: USD 2,000. Estimated cost of the constructable design: USD 1,098 (USD 902 under the target).

### Requirements not met or at risk

- **R1 at risk:** the hook droops about 0.66 m when the pole is held out at 25° (E = 20 GPa assumed). Placement is possible by aiming high, but this is the first thing to measure at TRL 4. A stiffer 50.8 mm tube would break R5.
- **R6 and R13 met with no margin:** 3.0 min and 300 N per hauler exactly.
- **R4 met by specification only:** depends on the bought tube's ASTM F711 certificate.
- **R7 and R9:** cannot be shown on paper; estimate and material choices only.
- **R5:** 0.18 kg margin.

### Decisions made under the pre-approval

- BHK-DDR-001 (fifteen TRL 2 review decisions, above) and BHK-DDR-002 (design for construction). Both recorded as decided by Amish on 2026-10-03 with his quote. Open decisions: none.

### Design changes made for construction (BHK-DDR-002), 2026-10-03

- Hook head cut from one 10 mm S355 plate (no forging), welded into two 10.5 x 50 slots in a 50.8 x 2.0 steel socket.
- Pole in socket: 1.15 mm radial clearance, 130 mm deep, rubber tape friction ring for a 50 N release.
- Pole joints: external fibreglass sleeve bonded 150 mm to the lower section, nylon 10 mm pin 75 mm above the joint.
- Rope attachment: 13 mm hole in a rope tab in line with the arm, rated bow shackle, 1.5 m wire rope leader, second shackle to the rope's spliced eye.
- Plate re-proportioned: 36 mm shank and 48 mm arm, S355 instead of S275 (the arm was at 1.24 on yield at proof).
- Toggles on prusik cord loops; rubber butt cap; sealed ends; red hand band.
- Rack: two welded 40 x 6 flat-bar uprights with lipped arms (poles 56 apart, sleeves at alternate ends) and a 380 mm rope peg so the coil clears the arms.

### Build plan findings

- No overlaps over 1 mm³ between any parts of a set, or of the kit on its rack, after the changes.
- Nominal tube sizes give zero clearance for the sleeve; the bore must be sanded. Listed under "To confirm when parts are bought" with seven other items.
- The pole cannot carry the pull and should not: the slip fit makes that physically impossible, which also keeps the pole team out of the load path.

### Appearance model and render scenes

- `cad/src/product_model.py`: TITLE "BreakHook: firebreak hook, pole and pull rope set"; views hero (set over the test frame with the mannequin), exploded (one set, sections side by side, coil and toggles) and detail (hook head on the wall plate, cut to a window). Every dimension comes from `model.py`. Differences from `model.py`: none in dimensions; the scene is turned 180° about Z for the camera, the detail view clips the parts to a window, and the pull rope's run on the ground is drawn as two straight lengths.
- Photoreal renders and the cards are made on Amish's Mac; `media/render-hero.png`, `media/card.png` and `media/social-preview.png` do not exist yet, so `render.py --check` warns about them and the image check.

### Safety concerns

- Falling structure, occupied dwelling, overhead and informal wiring, rope system failure under load, heat and smoke, crowds, and misuse in disputes. Each is answered by a conservative decision (BHK-DDR-001) and by the safety stops S1 to S5 in the build plan. The insulated pole is a second line of defence only.
- The proof load (6 kN) is the first time the rope system is loaded; safety stop S2 keeps everyone out of line with it.

### Recommended next step

- Photoreal renders and cards on Amish's Mac from `/home/claude/renders/breakhook`.
- TRL 4 (recommendation only, not started): build one set and the rack, proof-load it, then a reach trial (R1 droop) and a timed drill on a purpose-built test frame with the first co-design candidate.

## 2026-10-03: photoreal renders

Rendered with Blender Cycles on Amish's Mac from `cad/src/product_model.py`; captioned with `.kit/photo_caption.py`; `media/card.png` and `media/social-preview.png` made with `.kit/cards.py`. Views: hero, exploded, detail. image_qc passes and `render.py --check` has no FAIL.

## 2026-10-03: Amish's requirement decisions carried out

Amish chose option A on every requirement decision put to him: "1A 2A 3A 4A 5A 6A 7A 8A 9A 10A 11A". For BreakHook this is decision 6A (R1): add a light fork prop that supports the pole at mid-length, carried separately so the pole and hook head stay under 8 kg; recompute droop and reach. Not committed or pushed (batch run).

### Changes

- Fork prop added to `cad/src/model.py` (BHK-DDR-003): fibreglass lower tube 32 x 3 x 1,000 with foot cap and red hand band; fibreglass upper tube 25.4 x 3.2 x 1,100 sliding inside it, sixteen setting holes 50 apart; 12 mm HDPE fork plate with a 50 mm notch, held in a slot by two nylon M8 bolts; nylon setting pin. Fork notch 1.19 to 1.94 m above the ground; 1.24 m closed; 1.08 kg; no metal. New model checks: the prop's own parts at its longest and shortest settings, the fits (0.30 mm tube clearance, 0.25 mm each side of the fork tongue), the prop in use under the pole (fork 0.33 mm below the pole, foot on the ground, no overlaps with the set) and both props stowed on the rack's upper arms (no overlaps). STEP (`fork-prop.step`, `fork-prop-plate.step`) and STL (`fork-prop-plate.stl`) added; all STEP and STL regenerated.
- `docs/04-calcs/sizing.py` and `01-sizing.md` v0.2: the pole as a beam on the rear hand and the prop [F13 to F22], an alternative prop position [F23, F24] and the insulated path to the prop holder [H3]; `results.csv` re-run.
- `bom/bom.csv` lines 26 to 31 (two props, USD 72, each line with its price basis).
- `docs/03-requirements.md` v0.3 (targets unchanged, Amish quoted, status of R1, R5, R8, R10, R14 updated); `docs/02-concept.md` v0.3; README key figures.
- `docs/05-build-plan.md` v0.2: new row in Table 1, section 3.8 (fork prop) with Figures 14 to 16, Step 13 (assemble the prop), rack and stowing steps now 14 and 15, reach and prop first checks, S5 includes the prop.
- Pictures: general arrangement BHK-DWG-001 Rev P2 (detail C, fork prop, and a note line); new making sketch BHK-DWG-107; overview, joints 9 and 10, steps 13 to 15 regenerated; concept media (hero with the prop in place, exploded with the prop, blueprint key figures, `model.glb`).
- Register `docs/06-design-decisions.md` v0.2 and decision record `docs/decisions/0003-fork-prop.md` (BHK-DDR-003).
- Appearance model `cad/src/product_model.py`: the prop under the pole in the hero view and closed beside the toggles in the exploded view; scenes re-exported to `/home/claude/renders/breakhook`.

### New results

- R1: hook set at 3.0 m with the pole on the prop: droop 274 mm (was 658 mm by hand); the prop carries 100 N and the rear hand pushes down 24 N (was 252 N lifted, 168 N pushed). Rear hand 5.06 m from the wall; the prop holder stands about 2.9 m from it, 1.1 m nearer than the 4 m front-hand distance. Placement met on paper; the prop holder's distance is a new open decision.
- R5: 7.82 kg, unchanged (0.18 kg margin); the 1.08 kg prop is carried separately.
- R8: met; the prop closes to 1.24 m.
- R14: met; 3.67 m on the pole and 3.27 m of non-metal from the socket mouth to the prop holder's hand band.
- R10: Value-engineering target: USD 2,000. Estimated cost of the constructable design: USD 1,170 (USD 830 under the target). `budget_usd` unchanged.
- R6 estimate unchanged at 3.0 min (the prop is stored at the hole marked for the usual wall height and replaces the front-hand lift); still no margin.
- Prop buckling: 822 N on the upper tube alone, 8 times the prop load.

### For Amish

- New open decision 1 in the register: the prop holder stands about 2.9 m from the wall for the 25 s of placement. Options: (a) accept it for placement only, with R1's 4 m applying to the pole hands and the prop holder withdrawing with the pole; (b) move the prop back to keep 4 m (droop 0.72 m, worse than by hand); (c) let the prop stand alone in the fork while its holder steps back (untested). Recommendation: (a), checked in the TRL 4 reach trial and drill.
- The photoreal renders (`media/render-*.png`), card and social preview do not show the prop yet; re-render on the Mac from the re-exported scenes.

### Safety

- The prop is all fibreglass, HDPE and nylon. The 3 m overhead line rule, withdrawing the pole (and now the prop) before the haul, and leaving the fall zone are unchanged.

## 2026-10-03: photoreal renders redone after Amish's requirement decisions

Rendered with Blender Cycles on Amish's Mac from `cad/src/product_model.py`; captioned with `.kit/photo_caption.py`; `media/card.png` and `media/social-preview.png` made with `.kit/cards.py`. Views: hero, exploded, detail. image_qc passes and `render.py --check` has no FAIL.

## 2026-10-03: Amish's round-2 requirement decisions carried out

Amish, 2026-10-03: "i agree with all the 46 recommendations you provided. please proceed." For BreakHook this is decision 5A on the prop holder's distance, recorded in `docs/decisions/0004-prop-holder-distance.md` (BHK-DDR-004) and in the register `docs/06-design-decisions.md` (BHK-DEC-001 v0.3). A records and wording change only: no geometry, bill of materials, drawing or picture changed.

| Change | Files | New result |
| --- | --- | --- |
| Prop holder accepted at 2.9 m for placement only (about 25 s); holder withdraws with the pole | BHK-DDR-004, register v0.3 | Droop about 0.27 m, rear hand 5.06 m, holder 2.9 m, as before |
| R1 stand-off wording restated: 4 m applies to the pole hands | `docs/03-requirements.md` v0.4 | **R1 met on paper as restated**; the reach trial at TRL 4 confirms the distance, the time at 2.9 m and the withdrawal |
| Reach and drill checks worded for the stand-off | `docs/05-build-plan.md` (checks table) | Distances measured for each person |
| Open decision 1 closed | register v0.3 | Open decisions: none |
| Cost | unchanged | Value-engineering target: USD 2,000. Estimated cost of the constructable design: USD 1,170 (USD 830 under the target). `budget_usd` unchanged |

Mass unchanged (pole and hook 7.82 kg; prop 1.08 kg carried separately). Pictures changed: none; the appearance model is unchanged and no views were re-exported.

### Decisions proposed, awaiting Amish

None.

### Cross-repo actions

None.

### Safety

The prop holder is the person nearest the wall, at 2.9 m, and only while the hook is set on a dwelling that is not yet burning. The holder withdraws with the pole before the haul. The haulers' 10 m and 1.5 times height rule and the 3 m overhead line rule are unchanged.

### Recommended next step

TRL 4 (the reach trial on the test frame with the distances and the 25 s timed, then the drill) needs a new instruction from Amish.

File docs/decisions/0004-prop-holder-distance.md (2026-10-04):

---
doc_id: BHK-DDR-004
title: BreakHook prop holder stand-off accepted
project: BreakHook
doc_type: Design decision record
version: "0.1"
status: Draft
date: '2026-10-03'
author: Amish Chadha
license: CERN-OHL-S-2.0
revisions:
- version: "0.1"
  date: '2026-10-03'
  author: Amish Chadha
  change: Amish's round-2 decision 5A on the prop holder's distance recorded
---

# 0004: Prop holder at 2.9 m for placement only

- **Date:** 2026-10-03
- **Status:** decided by Amish, 2026-10-03 (round 2): "i agree with all the 46 recommendations you provided. please proceed." For BreakHook this is decision 5A, the open decision in BHK-DEC-001 v0.2.

## Context

The fork prop (BHK-DDR-003) works only near the pole's mid-length. There its holder stands about 2.9 m from the wall for the 25 s of placement, 1.1 m nearer than R1's 4 m front-hand distance. The rear handler is 5.06 m away. The firebreak is opened two dwellings ahead of the fire (BHK-DDR-001, decision 10), so the dwelling being hooked is not yet burning.

## Options considered

| Option | What it means |
| --- | --- |
| A (chosen) | Accept 2.9 m for the prop holder during placement only; restate R1's distance as applying to the pole hands; the holder withdraws with the pole before the haul |
| B | Keep 4 m for everyone and move the prop back (droop 0.72 m, no better than by hand) |
| C | Keep 4 m and set the prop, then let it stand alone in the fork while its holder steps back (untested) |

## Decision

Option A. No change to parts. R1 is restated: "Places the hook at a height of 3 m (10 ft) with the pole hands (front hand) 4 m (13 ft) from the wall; the prop holder may stand 2.9 m from the wall during placement only (about 25 s) and withdraws with the pole before the haul". The reach trial at TRL 4 confirms the distance, the time at 2.9 m and the withdrawal.

*Table 1. Effects.*

| Item | Result |
| --- | --- |
| R1 | Met on paper as restated: droop about 0.27 m, rear hand 5.06 m, prop holder 2.9 m for about 25 s (BHK-CAL-001 [F19], [F24]); confirmed at TRL 4 |
| Other requirements | None changed; pole and hook 7.82 kg |
| Wording changed | Requirements v0.4 (R1), build plan (reach and drill checks), register v0.3 |
| Cost | Unchanged. Value-engineering target: USD 2,000. Estimated cost of the constructable design: USD 1,170 (USD 830 under the target). `budget_usd` unchanged |

## Safety

> **Safety:** BreakHook pulls down a structure with a rope: haulers stand at least 10 m from the wall and at least 1.5 times the structure's height away. The prop holder is the nearest person to the wall, at 2.9 m, only while the hook is set and the structure is not burning; the holder withdraws with the pole before anyone hauls, and nobody is inside the fall zone at the haul. Overhead lines stay at least 3 m clear. It is an open engineering reference, not certified equipment.

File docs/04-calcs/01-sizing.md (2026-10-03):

---
doc_id: BHK-CAL-001
title: BreakHook sizing calculations
project: BreakHook
doc_type: Calculation
version: "0.2"
status: Draft
date: '2026-10-03'
author: Amish Chadha
license: CERN-OHL-S-2.0
revisions:
- version: "0.1"
  date: '2026-10-03'
  author: Amish Chadha
  change: First issue for TRL 3 on the constructable design (pull needed, hauling geometry, hook plate, welds, rope system, pole placement, joints, insulation, deployment time, mass and cost)
- version: "0.2"
  date: '2026-10-03'
  author: Amish Chadha
  change: Fork prop at mid-length added under Amish's decision 6A (BHK-DDR-003); droop, reach, prop load, buckling, prop mass, insulated path to the prop holder [F13 to F24, H3]; kit cost re-run
---

# BreakHook sizing calculations

The constructable design meets its strength, mass, insulation and reach targets on paper: the hook plate keeps a factor of 2.3 or more on yield at the 6 kN proof load, the pole and hook head weigh 7.82 kg against 8 kg, and haulers stand 10.8 m from the wall. With the fork prop at mid-length (BHK-DDR-003) the hook droops about 0.27 m instead of 0.66 m, and nobody lifts the pole: the prop carries 100 N into the ground. Two results still need care: the prop holder stands about 2.9 m from the wall while the hook is set, nearer than the 4 m of R1, and deployment comes out at exactly the 3 minute target. Times and pulls are estimates that a TRL 4 trial on a purpose-built test frame must confirm.

> **Safety:** This note sizes a tool that pulls down a structure with a rope. The numbers assume the dwelling has been checked empty, nobody is inside the fall zone, the pole has been withdrawn before the haul and there are no overhead lines within 3 m. Nothing in this note has been built or tested. Proof loads are applied to each hook head before issue, never to a person or an occupied structure.

## Scope and method

First-order hand calculations, run by `docs/04-calcs/sizing.py`, which takes every dimension and mass from the model (`cad/src/model.py`) and writes `docs/04-calcs/results.csv`. Each result has a reference in brackets, for example [A1]. Loads are static; no dynamic or impact factor is applied beyond the 2 x proof load, which is stated where it matters.

## Assumptions

Table 1. Assumptions

| # | Assumption | Value | Basis |
| --- | --- | --- | --- |
| 1 | Target dwelling | Single storey, 3.0 x 3.0 m, walls 2.4 m, light timber frame clad in corrugated steel sheet, 350 kg | Typical informal dwelling (BHK-PRB-001); to be confirmed with the co-design partner |
| 2 | Racking resistance of a nailed, clad, unbraced frame | 0.5 kN per metre of side wall | Engineering judgement for light cladding; to be measured on the TRL 4 test frame |
| 3 | Sustained pull per hauler on a rope with toggles | 300 N | Conservative for adults on dry ground; peak pulls are higher |
| 4 | Pull rope breaking strength | 25 kN or more, spliced eye 90 % | Bought to this specification (BOM 13) |
| 5 | Leader breaking strength | 20 kN or more, pressed ferrules 90 % | 6 mm 6x19 galvanised wire rope (BOM 12) |
| 6 | Hook plate | S355, yield 355 MPa, 10 mm | BOM 1 |
| 7 | Fibreglass pole tube | E = 20 GPa along the tube; flexural strength 200 MPa; density 1,900 kg/m³; foam 60 kg/m³ | Low end of published values for pultruded round tube; to be confirmed from the maker's data sheet |
| 8 | Placement geometry | Hook at 3.0 m, front hand 1.1 m high and 4.0 m from the wall | R1 |
| 9 | Store distance | Kit stored within 100 m of the dwellings it covers; walking 1 m/s with the kit | Community fire plan rule |
| 10 | Nylon 66 shear strength | 40 MPa | Conservative for a moulded pin |
| 11 | Epoxy allowable lap shear | 5 MPa | One third of a typical 15 MPa structural epoxy |
| 12 | Fork prop | Holds the pole at mid-length, leaning about 13° with its top toward the wall and its foot on the ground; the rear hand holds the butt 100 mm from its end; both are simple supports | BHK-DDR-003 |

## A. How hard to pull (R2, R7, R13)

Pulled at the top of the near wall, a rigid 350 kg dwelling tips over its near edge at 2.15 kN [A1]. A clad frame more often racks: at 0.5 kN per metre of the two 3 m side walls it needs about 3.0 kN [A2]. The working pull is set at 3 kN [A3] and every pulling part is sized for a 6 kN proof load [A4]. At 300 N each, ten haulers give the working pull [A5]; eight are enough for the overturning case [A6].

## B. Hauling geometry (R3)

The first toggle is 11 m along the line from the hook head. With the hook at 3.0 m and hands at 1.0 m, the nearest hauler stands 10.8 m from the wall [B1], against 4.5 m required by R3 [B2]. The rope rises at 10.5° [B3], so 98.3 % of the pull acts along the ground [B4]. The ten toggles run to 20 m along the 26.5 m line [B5], leaving a 6.5 m tail [B6].

## C. Hook plate at the 6 kN proof load (R2, R11)

Table 2. Hook plate stresses at the proof load

| Ref | Check | Result | Factor on yield (355 MPa) |
| --- | --- | --- | --- |
| C2 | Arm root bending, 75 mm deep beam (lever 58 mm) | 97.9 MPa | 3.6 at proof, 7.3 at working |
| C3 | Arm root bending, 100 mm deep beam (lever 90 mm) | 153 MPa | 2.3 at proof, 4.6 at working |
| C4 | Shank tension and bending (rope line 0.5 mm off the arm load line) | 18.1 MPa | 19.7 |
| C5 | Shackle hole tear-out, two 23.5 mm planes | 12.8 MPa | large |
| C6 | Shackle pin bearing on the plate | 54.5 MPa | 6.5 |
| C7 | Rope tab root bending | 37 MPa | 9.6 |

The arm is raked back 16.7° [C1] so a pull draws the beam deeper into the hook. The shackle hole is placed so the rope line passes through the middle of a 75 mm beam; the shank then carries almost pure tension [C4]. The throat takes beams up to 150 mm wide at the shank and 128 mm wide 100 mm down [C8, C9], and up to 117 mm deep [C10].

## D. Socket welds

The rope pulls the plate, never the socket [D2]. The welds carry only placement loads: a 200 N side push at the spike tip gives 4.6 MPa in the four 6 mm fillet welds [D1].

## E. Rope, leader and shackles (R2)

Factors at the 3 kN working pull: pull rope 7.5 [E1], wire rope leader 6.0 [E2], shackle working load limit 3.3 times the pull [E3]. Each prusik cord carries about 300 N [E4] against a breaking strength near 7 kN. The proof load of 6 kN is within the shackle's working load limit.

## F. Pole placement (R1, R5, R8)

Setting the hook at 3.0 m from 4.0 m away puts the pole at 25.4° [F1]. The front hand is 1.27 m from the butt [F2], below the hand band at 1.55 m [F3]. The pole, hook head, leader and the rope hanging from it weigh 84 N [F4]. Held with the hands 1.17 m apart, the rear hand pushes down with 168 N [F5] and the front hand lifts 252 N [F6], so the pole is handled by a team of two: one lifts, one holds the butt down. The tube stress at the front hand is 50.6 MPa, a factor of 4.0 on its flexural strength [F7].

The tube is flexible: with E = 20 GPa the hook droops about 658 mm below the straight line [F8] (second moment of area 8.91 cm⁴ [F9]). Held out by hand, the team would have to aim about 0.7 m high; a stiffer tube would add mass against R5. The fork prop below takes most of this droop out.

### With the fork prop (BHK-DDR-003)

Amish's decision 6A adds a light fork prop that holds the pole at its mid-length, 2,944 mm from the butt [F13]. In the R1 placement the pole's underside is 1.79 m above the ground there [F14]; the prop is set at its third hole (fork notch 1.84 m above the foot) and leans 12.8° with its top toward the wall [F15]. The pole then rests on two supports, the prop and the rear hand at the butt, with the hook end overhanging the prop.

- **Droop:** the hook droops 274 mm below the line through the two supports [F16], against 658 mm when the pole is held out by hand [F8]. The team aims about 0.3 m high and lowers the hook onto the beam.
- **Effort:** the prop carries 100 N into the ground through its foot [F17]; the rear hand pushes down with only 24 N [F18], against 252 N lifted and 168 N pushed down by hand [F5, F6]. The prop holder only steadies the prop.
- **Reach:** the hook is set at 3.0 m. The rear hand is 5.06 m from the wall [F20]. The prop foot is 2.89 m from the wall [F19], and the prop holder stands at or just behind it, so the nearest person is about 2.9 m from the wall while the hook is set, against 4.0 m for the front hand in R1.
- **Strength:** the prop's upper tube alone buckles at 822 N over the whole prop length, 8 times the prop load [F21].
- **Mass:** the prop weighs 1.08 kg [F22] and is carried separately, so the pole and hook head stay at 7.82 kg (R5). Closed, the prop is 1.24 m long (R8).

Moving the prop toward the butt until its foot is 4.0 m from the wall puts it 1,577 mm from the butt [F23]; the hook then droops 720 mm [F24], more than by hand, because nearly all the pole overhangs the prop. The prop only helps near mid-length.

Mass: the pole and hook head weigh 7.82 kg [F10], 0.18 kg under the 8 kg limit [F11]. The longest piece to carry is a section with its sleeve, 1.95 m [F12].

## G. Pole joints and release (R12)

The friction ring is wrapped until a 50 N pull frees the pole from the hook head [G1]. That is about four times the hook head's own weight along the pole at 25° [G2] and needs only 0.018 MPa of contact pressure [G3]. A nylon pin in double shear holds 6.3 kN [G4], about 126 times the release force [G5]; the pins never carry the rope pull. The bonded sleeve holds about 105 kN [G6].

## H. Insulation (R4, R14)

There is no metal between the mouth of the socket and the top of the hand band: 3.67 m of foam-filled fibreglass with nylon pins [H1], against 3.0 m required [H2]. The prop holder's hand is 3.27 m of fibreglass, HDPE and nylon from the socket mouth: along the pole to the fork, then down the prop to the top of its red hand band [H3]. Whether that length insulates depends on the bought tube's certificate (R4). The hook, leader and shackles are metal and a wet rope conducts.

> **Safety:** The insulated length is a second line of defence only. The rule on the check card stands: never raise the pole within 3 m of any overhead line, whatever the pole is made of.

## I. Deployment and pull time (R6, R7)

Table 3. Deployment estimate (pole team of two)

| Step | Seconds |
| --- | --- |
| Cut seal, unlock, lift out one set | 20 |
| Carry to the fire edge, 100 m at 1 m/s | 100 |
| Join three sections, two pins | 20 |
| Hook head onto the pole | 5 |
| Set the hook on the beam | 25 |
| Withdraw the pole, step out of the fall zone | 10 |
| **Total** | **180 (3.0 min) [I1]** |

The other two of the four lay out the rope and run the check card at the same time. The pole team is the rear handler and the prop holder: the prop is stored at the hole marked for the community's usual wall height and goes under the pole in place of the front-hand lift, so the estimate is unchanged; a timed drill at TRL 4 must confirm it. From hook set to frame down: crew on the toggles and the caller's zone check 30 s, slack taken up 10 s, pull 30 s, about 1.2 minutes [I2].

## L. Results against every requirement

Table 4. Requirements against the calculations (requirement text in BHK-REQ-001)

| ID | Target | Result | Status |
| --- | --- | --- | --- |
| R1 | Hook at 3 m from 4 m away | 25.4° pole on the fork prop: droop 0.27 m (0.66 m by hand), rear hand 24 N; rear hand 5.06 m and prop holder 2.9 m from the wall [F13 to F20] | Hook placement met on paper with much less droop; the prop holder stands 1.1 m nearer than the 4 m front-hand distance |
| R2 | 3 kN working, 6 kN proof | Plate factor 2.3 on yield at proof; rope 7.5, leader 6.0, shackle 3.3 [C, E] | Met |
| R3 | Haulers at 1.5 x height or more | 10.8 m against 4.5 m [B1] | Met |
| R4 | Non-conductive handled length, test voltage set | Foam-filled tube with a maker's ASTM F711 certificate [H1] | Met by specification; confirm the certificate when bought |
| R5 | 8 kg or less | 7.82 kg [F10]; the 1.08 kg prop is carried separately [F22] | Met, 0.18 kg margin |
| R6 | 3 min or less with four people | 3.0 min [I1] | Met on estimate, no margin; timed drill at TRL 4 |
| R7 | Under 2 min to bring down a test frame | About 1.2 min [I2] | Estimate only; timed trial at TRL 4 |
| R8 | No piece over 2 m | 1.95 m [F12]; prop 1.24 m closed | Met |
| R9 | 12 months outdoor storage | Material choices only | Not verifiable at TRL 3 |
| R10 | Kit cost against the USD 2,000 target | USD 1,170 with two fork props (bom/bom.csv) | USD 830 under the value-engineering target |
| R11 | Beams up to 100 x 120 mm | 117 mm deep, 128 to 150 mm wide [C8 to C10] | Met |
| R12 | Pole frees from the head before the haul | 50 N release [G1] | Met by design; set by trial |
| R13 | 300 N or less per hauler | 300 N with ten haulers [A5] | Met at the limit |
| R14 | 3.0 m or more insulated length | 3.67 m [H1]; 3.27 m to the prop holder's hand [H3] | Met |

## Checks against the TRL 1 figures

The TRL 1 precis gave a 4 to 6 m pole; the design is 5.9 m overall. The 8 kg mass target holds with 0.18 kg to spare only because the hook plate was trimmed to a 36 mm shank (BHK-DDR-002). The 3 kN working pull stands; the calculation shows it needs about ten people, not four, so the four-person team of R6 deploys the kit and the hauling crew comes from residents on the scene.

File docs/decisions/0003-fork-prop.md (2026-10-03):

---
doc_id: BHK-DDR-003
title: BreakHook fork prop at mid-length (R1)
project: BreakHook
doc_type: Design decision record
version: "0.1"
status: Draft
date: '2026-10-03'
author: Amish Chadha
license: CERN-OHL-S-2.0
revisions:
- version: "0.1"
  date: '2026-10-03'
  author: Amish Chadha
  change: Amish's requirement decision 6A carried out
---

# 0003: Fork prop at mid-length (R1)

- **Date:** 2026-10-03
- **Status:** accepted
- **Decided by:** Amish Chadha, 2026-10-03, choosing option A on every requirement decision put to him: "1A 2A 3A 4A 5A 6A 7A 8A 9A 10A 11A". For BreakHook, 6A: add a light fork prop that supports the pole at mid-length, carried separately so the pole and hook head stay under 8 kg; recompute droop and reach.

> **Safety:** The prop is fibreglass, HDPE and nylon, with no metal, and carries a red hand band like the pole. Its holder's hand is 3.27 m of non-metal from the hook head (BHK-CAL-001 [H3]). The rule on the check card stands: never raise the pole within 3 m of any overhead line. The prop is withdrawn with the pole before anyone hauls, and its holder leaves the fall zone with the pole team.

## Context

At TRL 3 the hand-held pole drooped about 0.66 m at the hook when held out at 25° (BHK-CAL-001 [F8]), and the front hand had to lift 252 N. R1 was recorded as at risk. A stiffer 50.8 mm tube would have broken R5 (8 kg).

## Options considered

- **A (chosen):** a light fork prop under the pole at mid-length, carried separately.
- B: a stiffer, heavier pole tube (breaks R5).
- C: a shorter reach (weakens R1).

## Decision

A fork prop, one per set (BOM lines 26 to 31, making sketch BHK-DWG-107):

- Lower tube: fibreglass 32 x 3, 1,000 mm (the toggle stock), rubber foot cap, red hand band 850 to 900 mm up from the foot, one 10.5 mm hole 50 mm below its top.
- Upper tube: fibreglass 25.4 x 3.2, 1,100 mm, sliding inside the lower tube with 0.3 mm radial clearance; sixteen 10.5 mm setting holes 50 mm apart; a 12.5 x 60 mm slot across its top.
- Fork plate: 12 mm HDPE, 100 mm wide, with a 50 mm round-bottomed notch for the 44.5 mm pole and a 25.4 mm tongue in the slot, held by two nylon M8 bolts.
- A nylon 10 mm setting pin sets the fork notch from 1.19 m to 1.94 m above the ground in 50 mm steps. Closed, the prop is 1.24 m long; it weighs 1.08 kg.
- In use the prop holds the pole 2,944 mm from the butt, at mid-length, leaning about 13° with its top toward the wall. The pole lies loose in the notch; the fork never clamps it. On the rack the two props lie closed on the upper arms between the top sections.

## Consequences

- R1: the hook droops 274 mm instead of 658 mm (BHK-CAL-001 [F16]). The prop carries 100 N into the ground; the rear hand pushes down with 24 N instead of 252 N lifted and 168 N pushed by hand.
- Reach: the hook is set at 3.0 m; the rear hand is 5.06 m from the wall, and the prop holder stands about 2.9 m from it [F19, F20], 1.1 m nearer than R1's 4 m front-hand distance. Moving the prop back to keep its holder at 4 m gives 720 mm of droop [F24], so the benefit only exists near mid-length. Whether 2.9 m is acceptable is posed to Amish in the design decisions register.
- R5 unchanged at 7.82 kg; the prop is carried separately. R8 met (prop 1.24 m closed). R14 met; 3.27 m to the prop holder's hand.
- Cost: USD 72 for two props. Value-engineering target: USD 2,000. Estimated cost of the constructable design: USD 1,170 (USD 830 under the target).
- R6 estimate unchanged at 3.0 min: the prop is stored at the hole marked for the community's usual wall height and takes the place of the front-hand lift. The timed drill at TRL 4 must confirm it.
- Constructability: no overlaps over 1 mm³ between the prop's own parts at its longest and shortest settings, between the prop and the set in use, or between the props and the kit on the rack (`python cad/src/model.py --check`).

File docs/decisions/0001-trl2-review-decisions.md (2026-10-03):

---
doc_id: BHK-DDR-001
title: BreakHook TRL 2 review decisions
project: BreakHook
doc_type: Design decision record
version: "0.1"
status: Draft
date: '2026-10-03'
author: Amish Chadha
license: CERN-OHL-S-2.0
revisions:
- version: "0.1"
  date: '2026-10-03'
  author: Amish Chadha
  change: TRL 2 review decisions, made under Amish's 2026-10-03 pre-approval
---

# 0001: TRL 2 review decisions

- **Date:** 2026-10-03
- **Status:** accepted
- **Decided by:** Amish Chadha, by pre-approval: "start with the first 14 repos from the list of 29 projects. I pre-approve the batch runs along with any recommendations you come up with. I also accept any cost overruns or variations from the assumed scope cost." Each recommendation below was made in the TRL 2 review of this repo and is recorded as decided under that pre-approval.

> **Safety:** BreakHook pulls a structure down with a rope near a fire. Every decision that touches safety below takes the conservative option and states what evidence would relax it.

## Context

The TRL 1 scaffold (BHK-PRC-001 v0.1) left the pole material, the hook construction, the rope system, the hauling crew and five open questions in BHK-PRB-001 undecided. TRL 3 needs each settled so the design can be calculated, modelled and planned.

## Decisions

| # | Decision | Options considered | Why | Safety note and what would relax it |
| --- | --- | --- | --- | --- |
| 1 | Pole: foam-filled, electrical-grade pultruded fibreglass round tube 44.5 x 3.2, three 1.8 m sections, with the maker's ASTM F711 dielectric certificate | Hollow fibreglass tube; bamboo; aluminium | Light, stiff enough, and the only option whose insulation can be certified | Conservative: foam fill and certificate even though the pole is never meant to touch a line. Relax only with a field study showing no wiring hazard, which is unlikely |
| 2 | Pole is withdrawn before the haul; the rope alone pulls | Pole stays on and is pulled with the rope; pole used as a lever | Keeps the pole team out of the fall zone and keeps the pole out of the load path | Conservative. No evidence would relax it |
| 3 | Hook head: plate cut from 10 mm steel, welded into a slotted steel socket; WLL 3 kN; proof 6 kN before issue | Forged hook; bought pike-pole head | Makeable by any local welder; the pike-pole heads on sale are not rated for a rope pull | Proof load before issue and after any seal break; relax to sample proof loading only after a batch of 20 heads all pass |
| 4 | Rope system: 1.5 m galvanised wire rope leader, rated bow shackles, 25 m of 12 mm polyester double braid | Rope tied straight to the hook; chain leader | Leader keeps heat and sheet edges off the rope; chain is too heavy at the pole tip | Factors 6 or more on the rope and leader; relax to a lighter rope only with test data |
| 5 | Crew: four to deploy (pole team of two, caller, fall zone marker) and about ten haulers on toggles; requirement R13 added (300 N each) | Four haulers; a pulley or capstan | The pull needs about 3 kN (BHK-CAL-001); a pulley needs a strong anchor that settlements rarely have | Pulley left out; it could be added as an option where a tested anchor (a stake system) exists |
| 6 | Hauling distance: nearest hauler at 1.5 x the dwelling height and never closer than 10 m (R3 tightened) | 1.5 x height only | Keeps haulers well outside the fall zone and further from heat | Conservative; relax only with fall-zone measurements from TRL 4 trials |
| 7 | Overhead lines: never raise the pole within 3 m of any overhead or informal line, whatever the pole's insulation | Rely on the insulated pole | Informal wiring is unpredictable; the hook and wet rope conduct | Conservative; no evidence would relax it |
| 8 | Hand band 1.55 m from the butt; hands stay below it; insulated length 3.0 m or more (R14 added) | No marking | Gives the insulated length a meaning in use | None |
| 9 | Misuse safeguard: settlement committee holds the kit in a locked, sealed rack with two named keyholders and a use log; pulls only during a fire under the community fire plan | Open storage; fire service storage only | Answers the dispute and eviction concern while keeping the kit near the homes | Conservative |
| 10 | Firebreak rule for training: at least two dwellings ahead of the burning one, and only if the pull can finish first; otherwise evacuate | One dwelling ahead | Spread can take under a minute | Relax only with evidence from fire-spread studies in the partner's settlements |
| 11 | Scope: free-standing dwellings and end units only; no shared-wall rows, multi-storey or masonry | Allow shared walls | A shared wall can bring down the neighbour or fall unpredictably | Conservative; relax only after trials on a shared-wall test frame |
| 12 | Kit storage and checks: monthly check card; a broken seal means a full check and a fresh proof load | Annual check | Outdoor storage and community use | None |
| 13 | Co-design partner, first candidate to approach (not agreed): City of Cape Town Fire and Rescue Service volunteer reservists with a Western Cape settlement committee; second: Kenya Red Cross Society, Nairobi | Others in BHK-PRB-001 | Strongest evidence base (Stellenbosch and Imizamo Yethu studies) and an existing reservist system | Not a safety decision |
| 14 | Requirements: targets of R1 to R10 kept, R6 measured to hook set with the pole withdrawn and the store within 100 m; R11 to R14 added | Leave as TRL 1 | Makes each target measurable | None |
| 15 | Budget: `budget_usd` stays at USD 2,000 as a value-engineering target | Change it | Amish's pre-approval accepts variations; the estimate is under the target anyway | Not a safety decision |

## Consequences

- BHK-REQ-001 v0.2, BHK-PRC-001 v0.2 and BHK-PRB-001 v0.2 carry these decisions.
- The design for construction (BHK-DDR-002) builds on decisions 1 to 4.
- The check card, training material and fall zone kit are part of the community kit (BOM 19 to 24).

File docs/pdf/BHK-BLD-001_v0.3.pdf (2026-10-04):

B R E A K H O O K · B U I L D P L A N

# BreakHook prototype build plan

Design Molecule Lab · designmolecule.com

D O C U M E N T CO N T RO L

Document ID | BHK-BLD-001 | Version | 0.3
Status | Draft | Date | 2026-10-03
Author | Amish Chadha | License | CERN-OHL-S-2.0
Project TRL | TRL 3 | Proof of concept
Repository | github.com/BoujeeEnjinia1701/breakhook
Source | docs/05-build-plan.md @ uncommitted

R EV I S I O N H I STO RY

Version | Date | Author | Change
0.3 | 2026-10-03 | Amish Chadha

Reach and drill checks worded for the prop holder's placement-only stand-off at 2.9 m (BHK-DDR-004, Amish's round-2 decision 5A)

0.2 | 2026-10-03 | Amish Chadha | Fork prop added (BHK-DDR-003); new section 3.8, Figures 14 to 16, Step 13; rack and stowing steps renumbered 14 and 15
0.1 | 2026-10-03 | Amish Chadha | First build plan; design made constructable (BHK-DDR-002)

D R A F T · N O T F O R F A B R I C A T I O N

## BreakHook prototype build plan

Plan, not yet built. How to build the first proof-of-concept prototype, component by component. Building and testing to it is TRL 4 work. Decisions still to be made are kept in the design decisions register (docs/06-design-decisions.md), not here.

### 1. What you are building


Figure 1. One set, its fork prop and one rack upright, pulled apart and numbered in build order.
The prototype is one BreakHook set and its wall rack: a yellow steel hook head on a 5.9 m orange fibreglass pole in three sections, a short steel wire rope leader, a 25 m blue pull rope with ten hauling toggles, a light fork prop that holds the pole at mid-length while the hook is set, and two steel rack uprights. A community kit is two sets on one rack. Seven components are made: the hook plate and the socket tube (welded together into the hook head), the pole sections, the joint sleeves, the toggles, the fork prop and the rack uprights. Everything else is bought: shackles, wire rope leader, pull rope, nylon pins, cord, tape, caps, the lock and the seals. The work is cutting and welding steel plate and tube, cutting, drilling and gluing fibreglass tube, and tying knots. The parts for a community kit cost about USD 1,170 from the bill of materials.

Safety: This is a pulling tool used near fire, around people and possibly near electrical wiring. In the workshop the hazards are hot work (cutting and welding steel), fibreglass dust, and, at first load, a rope system under 6 kN. Weld only with fire precautions and eye protection; cut and drill fibreglass outdoors or with extraction, in a dust mask and gloves. Never stand in line with a loaded rope or leader. No part of this plan involves pulling down a real dwelling; first trials use a purpose-built test frame, outside this plan.

### 2. What changed to make it buildable

The concept showed what BreakHook does; several parts could not be made or joined as first drawn. Each change below keeps what the tool does and is recorded in decision record BHK-DDR-002.
Table 1. Changes from the concept.
Component | The concept had | The buildable design has | Why
Hook head | A forged or fabricated hook with a spike | One profile cut from 10 mm steel plate (Figure 2) | No forging; any welder can cut it
Hook to pole | Hook on the end of the pole | A slotted steel socket with the plate welded into both slots (Figure 3)

A face-to-face welded joint a welder can check by eye

Pole in socket Not defined | A slip fit with a rubber tape ring that releases
| | at a firm 50 N pull (Figure 5)

The pole must come off before anyone hauls

Pole joints | Not defined | A fibreglass sleeve glued to the lower section and a nylon pin through the upper one (Figure 8)

Foam-filled tube cannot take an inside spigot; no metal in the insulated length

Rope attachment | Rope tied to the hook head | A shackle in a hole in line with the hook's arm, a 1.5 m wire rope leader, a second shackle to the rope (Figures 12 and 13)

No knot to weaken or cut; the pull runs straight through the hook

Hook plate size | 40 mm shank and arm in ordinary steel
36 mm shank and 48 mm arm in S355 steel | The arm needed more strength on deep
beams; the slimmer shank keeps the weight under 8 kg
Hauling handles | Handles or toggles | Fibreglass toggles on prusik cord loops (Figure 10)

They slide along the rope when slack and grip when pulled

Rack | A rack and a seal | Two welded flat-bar uprights with lipped arms and a rope peg (Figure 11)

Every piece rests on an arm without touching its neighbour

Holding the pole up | Two people holding the pole out by hand | A fork prop under the pole at mid-length, carried separately (Figures 14 to 16; decision record BHK-DDR-003)

The hand-held pole sagged about 0.66 m at the hook; on the prop it sags about 0.27 m and nobody has to lift it

### 3. Making the components

Make and check each component before the assembly step that needs it. Sizes are in millimetres. "Front" is the end with the hook; the hook's arm points down. Workshop tolerance is 1 mm unless a step says otherwise; drawings carry no tolerances before TRL 4.

### 3.1 Hook plate

Figure 2. Hook plate making sketch (BHK-DWG-101).
What it is and what it is made from. The working part of the tool: a forward spike, a straight shank, an arm that hangs down behind a beam, a small barb at the arm's foot, and a rope tab with the shackle hole. One piece of 10 mm S355 steel plate, from a blank 500 x 200.
How to make it.
Print the profile from the making sketch at full size, glue it to the plate and centre-punch the corners and the hole centre.
Drill the 13 mm shackle hole, centred 55 from the socket end of the plate and 55 below the centre line of the shank.
Drill a 16 mm hole at each inside corner where the arm and the tab meet the shank, so the corners end up round (about 8 mm radius), never a sharp notch.
Cut the outline by plasma, or by chain drilling and an angle grinder with a cutting disc. The end that goes into the socket is 56 wide and 62 long; the shank is 36 wide; the arm is 48 wide and hangs 117 below the shank, sloping back toward the user by about 17°; the spike tip is on the centre line, 440 from the socket end.
Grind every edge clean, break the corners by about 1 mm, and dress the spike to a point with no burr.
Stamp "WLL 3 kN" and the serial number on the shank, near the socket end.

How it fits the parts next to it. The wide end slides 50 deep into the socket's two slots and stands 2.6 proud of the tube top and bottom for the welds (Figure 3). In use the shank rests on the top of a wall plate or rafter and the arm hangs behind it (Figure 4); the rope pulls through the shackle hole, which lines up with the middle of a 75 mm beam.

1.

2.

3.

4.

5.
6.

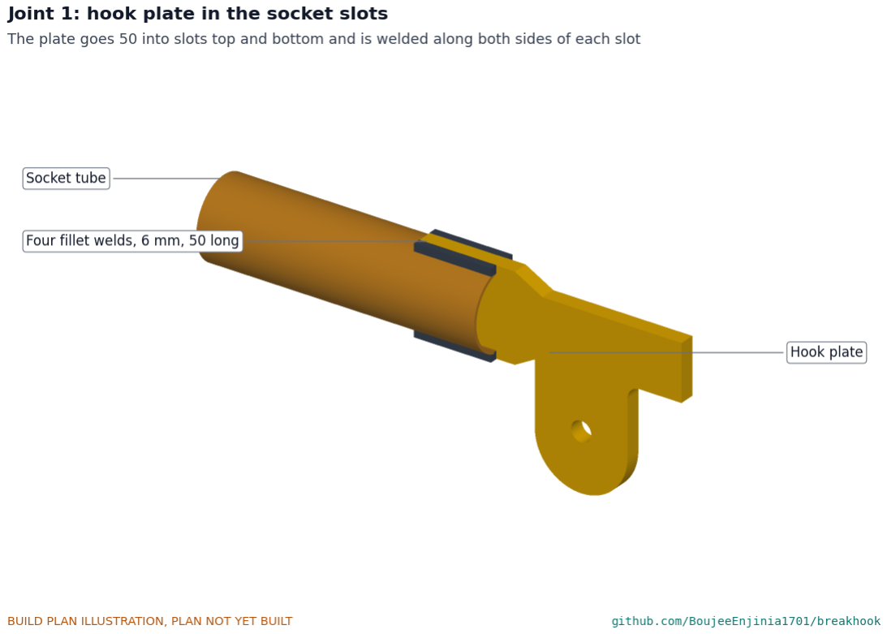
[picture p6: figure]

Figure 3. The plate sits in slots top and bottom and is welded along both sides of each slot.

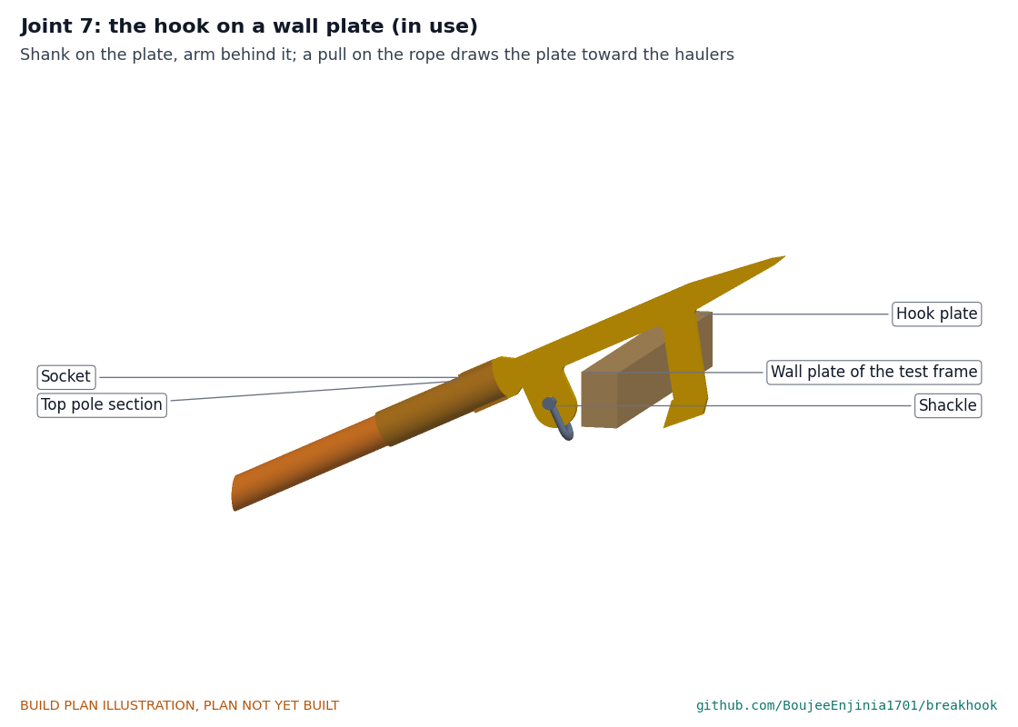
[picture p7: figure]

Figure 4. In use: shank on the plate, arm behind it.
Check before moving on. Lay the plate on the full-size print: every edge within 1 mm. A 75 x 50 timber offcut fits under the shank against the arm, and a 100 mm deep one fits too.

### 3.2 Socket tube

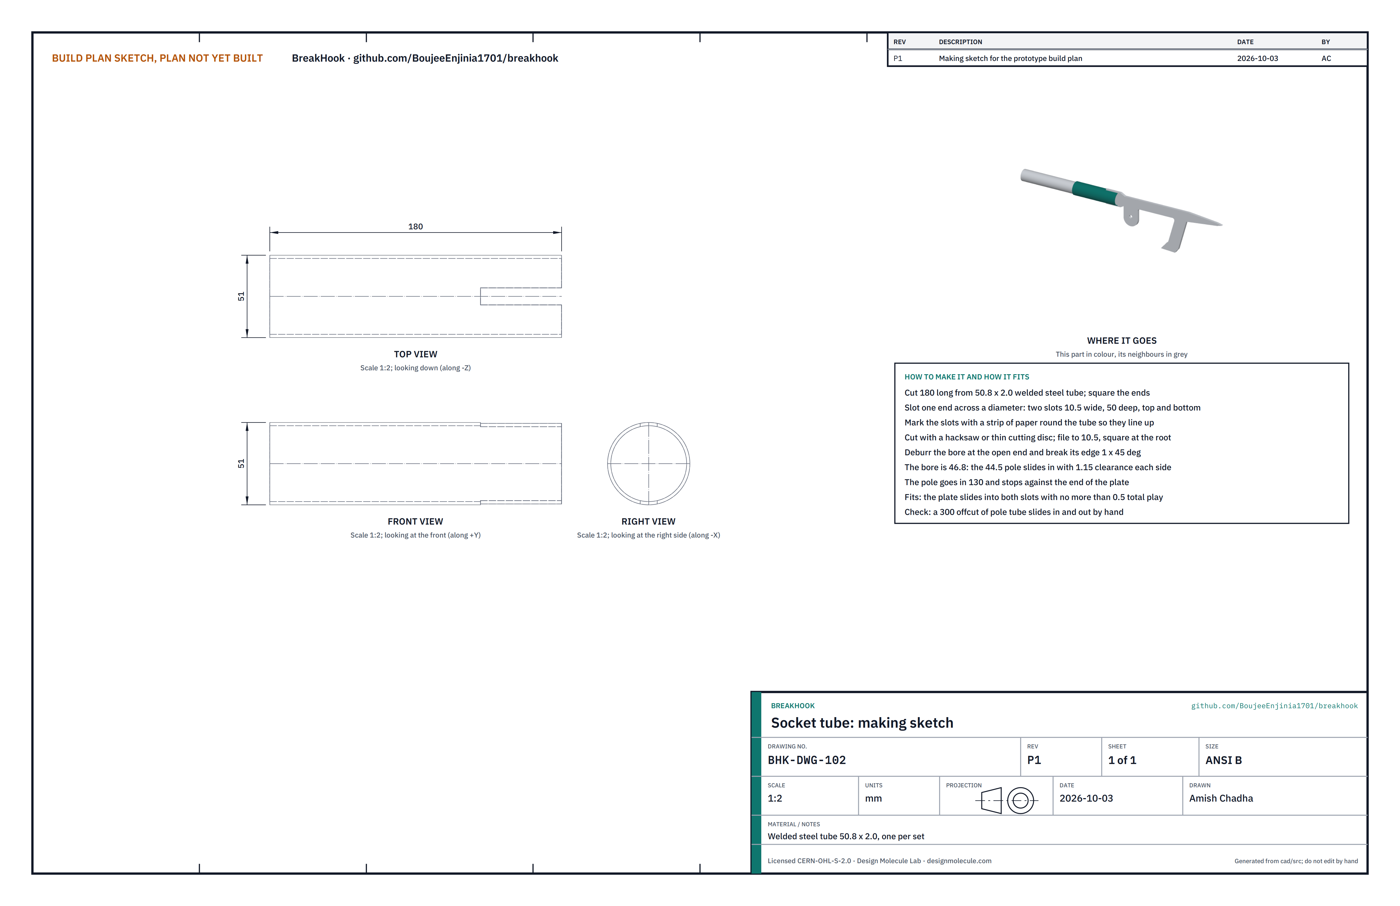
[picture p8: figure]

Figure 5a. Socket tube making sketch (BHK-DWG-102).
What it is and what it is made from. The short steel tube the pole slides into. Welded steel tube 50.8 x 2.0, cut to 180.
How to make it.
Cut 180 from the tube and square both ends.
Wrap a strip of paper round one end to mark two slots exactly opposite each other, 10.5 wide and 50 deep. Cut the slots with a hacksaw or a thin cutting disc and file them to width, square at the bottom.
Deburr the bore at the open end and break its edge.

How it fits the parts next to it. The bore is 46.8; the 44.5 pole slides in with about 1.15 clearance all round and goes in 130 until it stops on the end of the plate. A ring of rubber tape on the pole tip makes it a firm push fit (Figure 5).

1.
2.
3.
4.

Figure 5. Cut open: the pole stops on the plate; the tape ring holds it.
Check before moving on. A 300 offcut of pole tube slides in and out by hand; the plate goes into both slots with no more than 0.5 total play.
Welding the hook head (Step 2). Tack the plate in the slots, check it is square to the tube and centred, then run a 6 mm fillet weld along both sides of each slot, outside the tube. Clean, prime with zinc-rich primer and paint high-visibility yellow.

### 3.3 Pole sections (make 3)

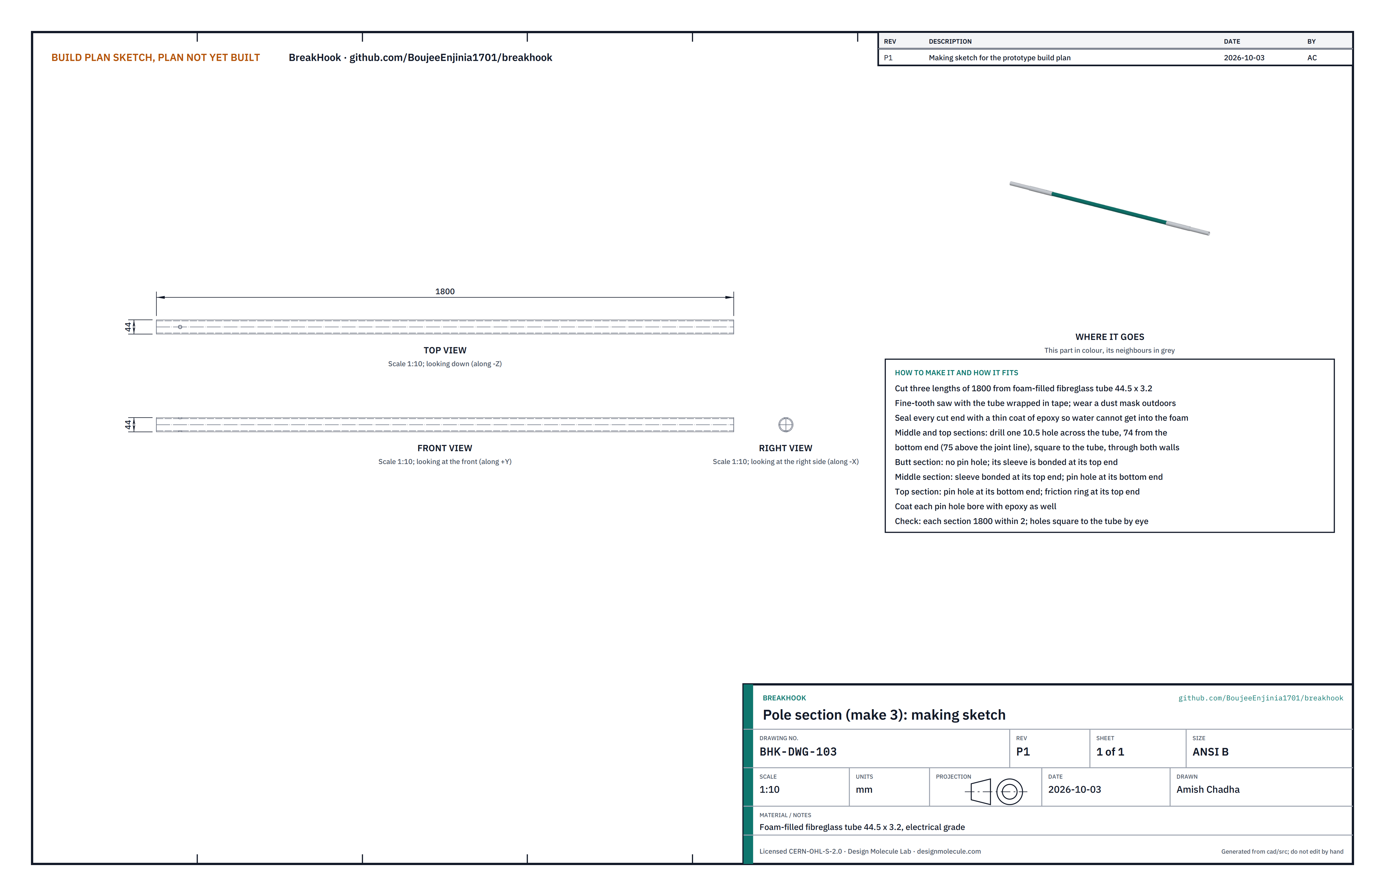
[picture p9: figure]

Figure 6. Pole section making sketch (BHK-DWG-103).
What it is and what it is made from. Three 1.8 m lengths of foam-filled, electrical-grade fibreglass tube 44.5 x 3.2 that carries the maker's dielectric test certificate. The butt section is the bottom one, the top section carries the hook head.
How to make it.
Cut three lengths of 1800 with a fine-tooth saw, the tube wrapped in tape where you cut. Work outdoors in a dust mask and gloves.
Middle and top sections: drill one 10.5 hole straight across the tube, through both walls, 74 from the bottom end.
Seal every cut end and the bore of every pin hole with a thin coat of epoxy, so water cannot get into the foam.

How it fits the parts next to it. The butt and middle sections each get a sleeve glued on their top ends (section 3.4); the section above slides into that sleeve and is pinned. The butt section also gets a rubber cap and a red hand band 1550 to 1600 from its bottom end. The top section gets the friction ring 110 to 150 below its tip.
Check before moving on. Each section is 1800 within 2; the pin holes are square to the tube by eye.

1.

2.

3.

### 3.4 Joint sleeves (make 2)

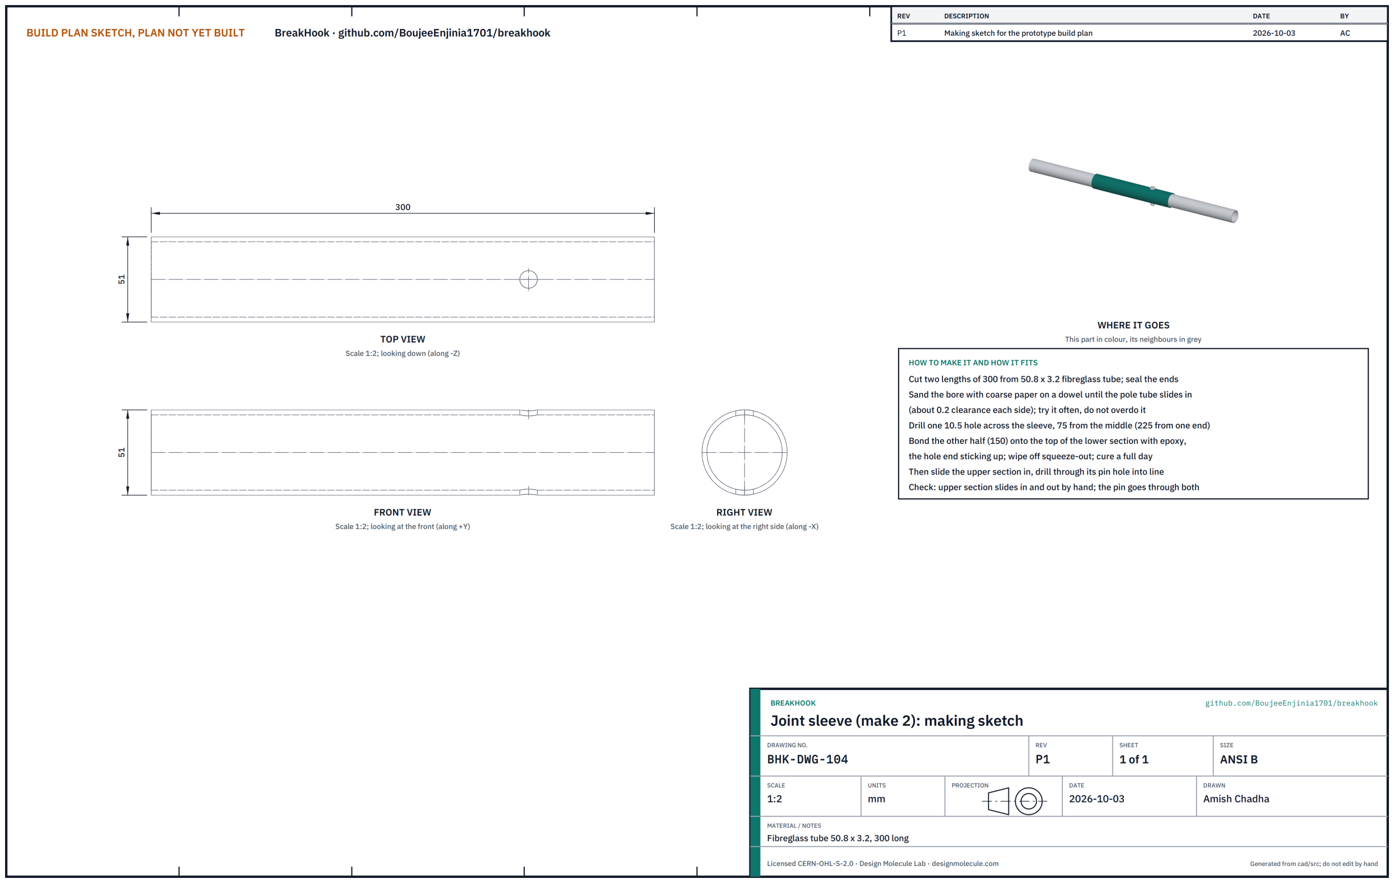
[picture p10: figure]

Figure 7. Joint sleeve making sketch (BHK-DWG-104).
What it is and what it is made from. A 300 length of fibreglass tube 50.8 x 3.2 that joins two pole sections. How to make it.
Cut two lengths of 300 and seal the ends with epoxy.
Sand the bore with coarse paper on a dowel, trying a pole offcut often, until the pole slides in with about 0.2 clearance all round.
Drill one 10.5 hole straight across, 75 from the middle of the sleeve.
Glue the half without the hole (150) onto the top of the butt section, and the other sleeve onto the top of the middle section, with structural epoxy. Wipe off the squeeze-out and let it cure a full day.

How it fits the parts next to it. The two sections meet in the middle of the sleeve with a 2 gap. The upper section slides into the free half and a nylon pin goes through the sleeve and the section (Figure 8).

1.
2.

3.
4.

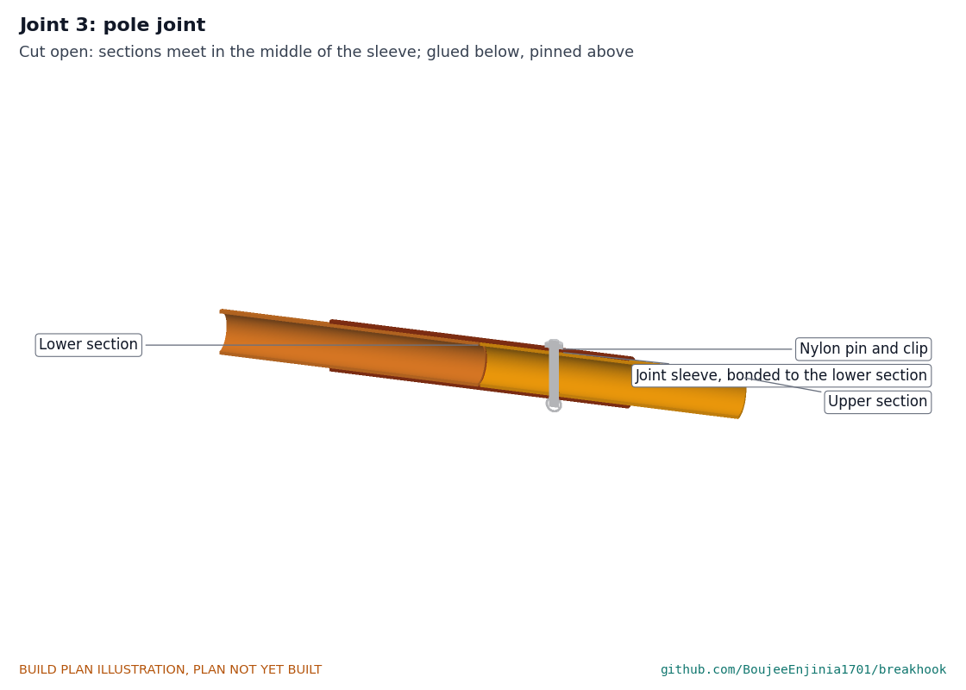
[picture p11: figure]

Figure 8. Cut open: glued below the joint line, pinned above it.
Check before moving on. The upper section slides in and out by hand and the pin goes through both holes without forcing.

### 3.5 Hauling toggles (make 10 per set)

Figure 9. Hauling toggle making sketch (BHK-DWG-105).
What it is and what it is made from. A 300 length of fibreglass tube 32 x 3 that a hauler holds, hung from the pull rope on a loop of 6 mm cord.
How to make it.
Cut ten lengths of 300; round and seal the ends.
Drill a 10 hole straight across at mid length.
Pass 1.2 m of 6 mm cord through the hole and tie it into a loop with a double fisherman's knot that sits under the toggle.

How it fits the parts next to it. The loop goes onto the pull rope with a three-turn prusik hitch, which slides when slack and grips under load (Figure 10). Toggles go 1 m apart from 11 m along the line.

1.
2.
3.

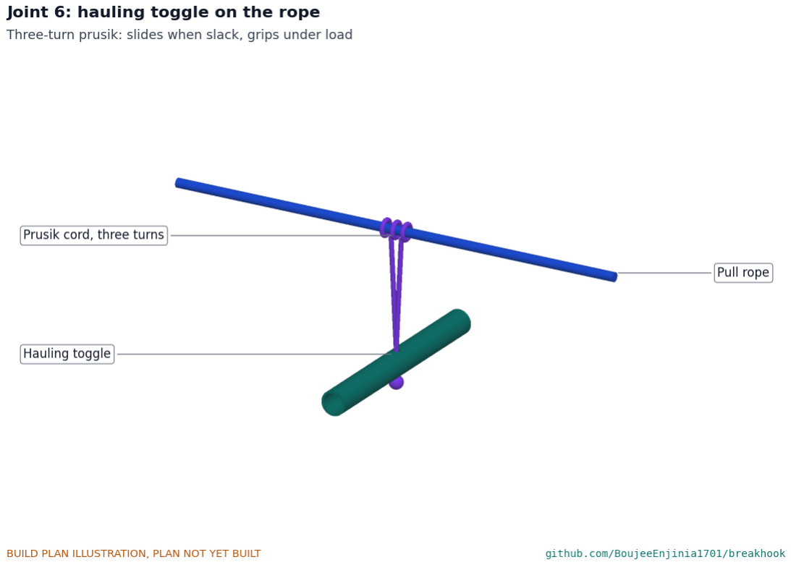
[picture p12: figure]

Figure 10. Three-turn prusik on the 12 mm rope.
Check before moving on. Hang 30 kg from one toggle on a length of the rope: the prusik does not slip.

### 3.6 Rack uprights (make 2)

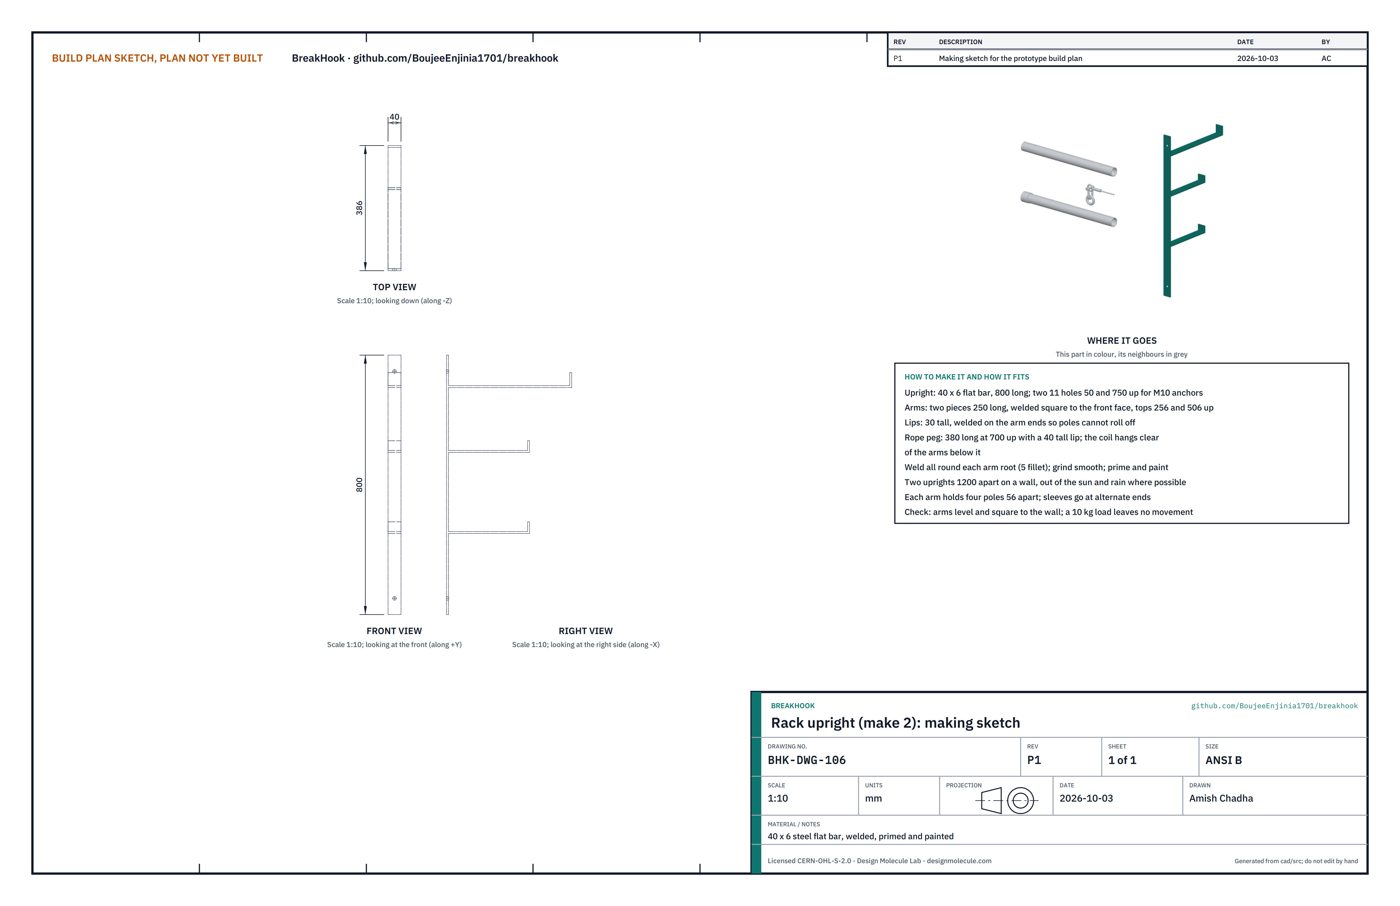
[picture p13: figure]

Figure 11a. Rack upright making sketch (BHK-DWG-106).
What it is and what it is made from. A wall bracket of 40 x 6 steel flat bar: an 800 upright, two 250 arms with 30 lips, and a 380 rope peg with a 40 lip.
How to make it.
Cut the upright, two arms, a peg and three lips from 40 x 6 flat bar.
Drill two 11 holes in the upright, 50 and 750 up, for M10 anchors.
Weld the lips on the ends of the arms and the peg, standing up.
Weld the arms square to the front face of the upright with their tops 256 and 506 up, and the peg at 700 up. Weld all round each root.
Grind smooth, prime and paint.

How it fits the parts next to it. The two uprights go 1200 apart on a wall. Each arm holds four poles 56 apart, with the sleeves at alternate ends so they do not touch. The rope coil hangs on the peg clear of the arms below (Figure 11).

1.
2.
3.
4.

5.

Figure 11. Lower arms hold the butt and middle sections, upper arms the top sections with their hook heads. Check before moving on. Arms level and square to the wall; a 10 kg load leaves no movement.

### 3.7 Bought components

Shackles (four per kit): 3/8 in (10 mm) screw-pin bow shackles, galvanised, rated 1 t and marked. Check the jaw takes the 10 mm plate and the pin passes the 13 mm hole. Mouse each pin with soft wire after fitting.
Wire rope leaders (two): 6 mm 6x19 galvanised wire rope, 1.5 m between thimble eyes with pressed ferrules, proof tested and tagged by the rigging shop (Figures 12 and 13).
Pull ropes (two): 12 mm polyester double braid, breaking strength 25 kN or more, 25 m with a spliced eye; whip the tail.
Nylon pins (four): 10 mm nylon 66 clevis pins with nylon hitch clips; tie each to its section with a cord lanyard. Friction ring tape, red tape and clear sleeve, butt caps, structural epoxy, cord, paint: as the bill of materials. Nylon M8 bolts, prop setting pins and prop foot caps: for the fork prop (section 3.8).
Lock cable and padlock, numbered seals, fall zone tape and stakes, check cards, rigger gloves: used in Step 15 and in training.

•

•

•

•
•
•
•

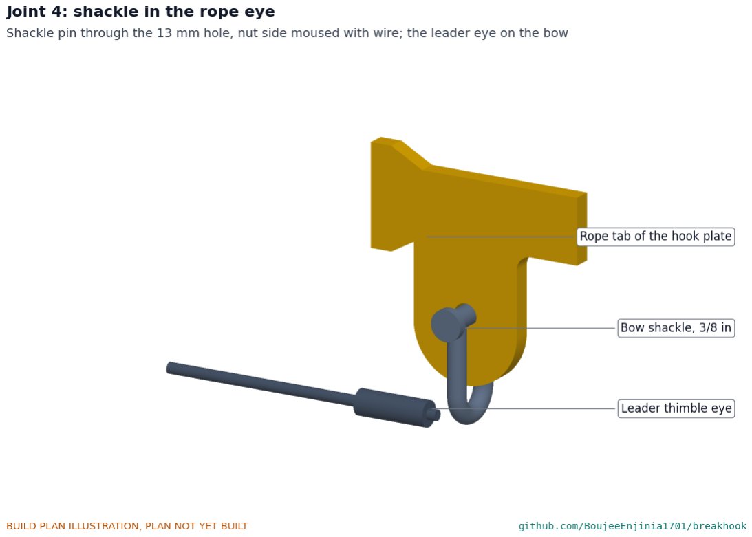
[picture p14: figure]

Figure 12. Shackle pin through the 13 mm hole; leader eye on the bow.

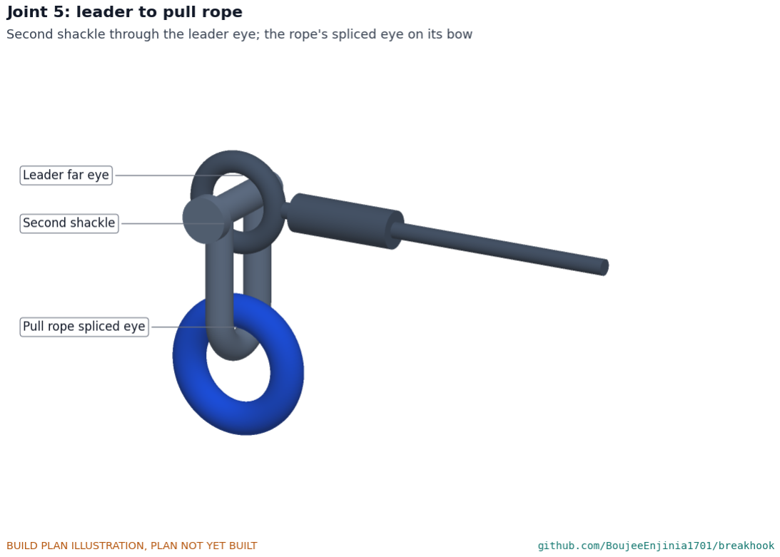
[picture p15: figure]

Figure 13. Second shackle through the far leader eye; the rope's spliced eye on its bow.

### 3.8 Fork prop (make 1 per set)

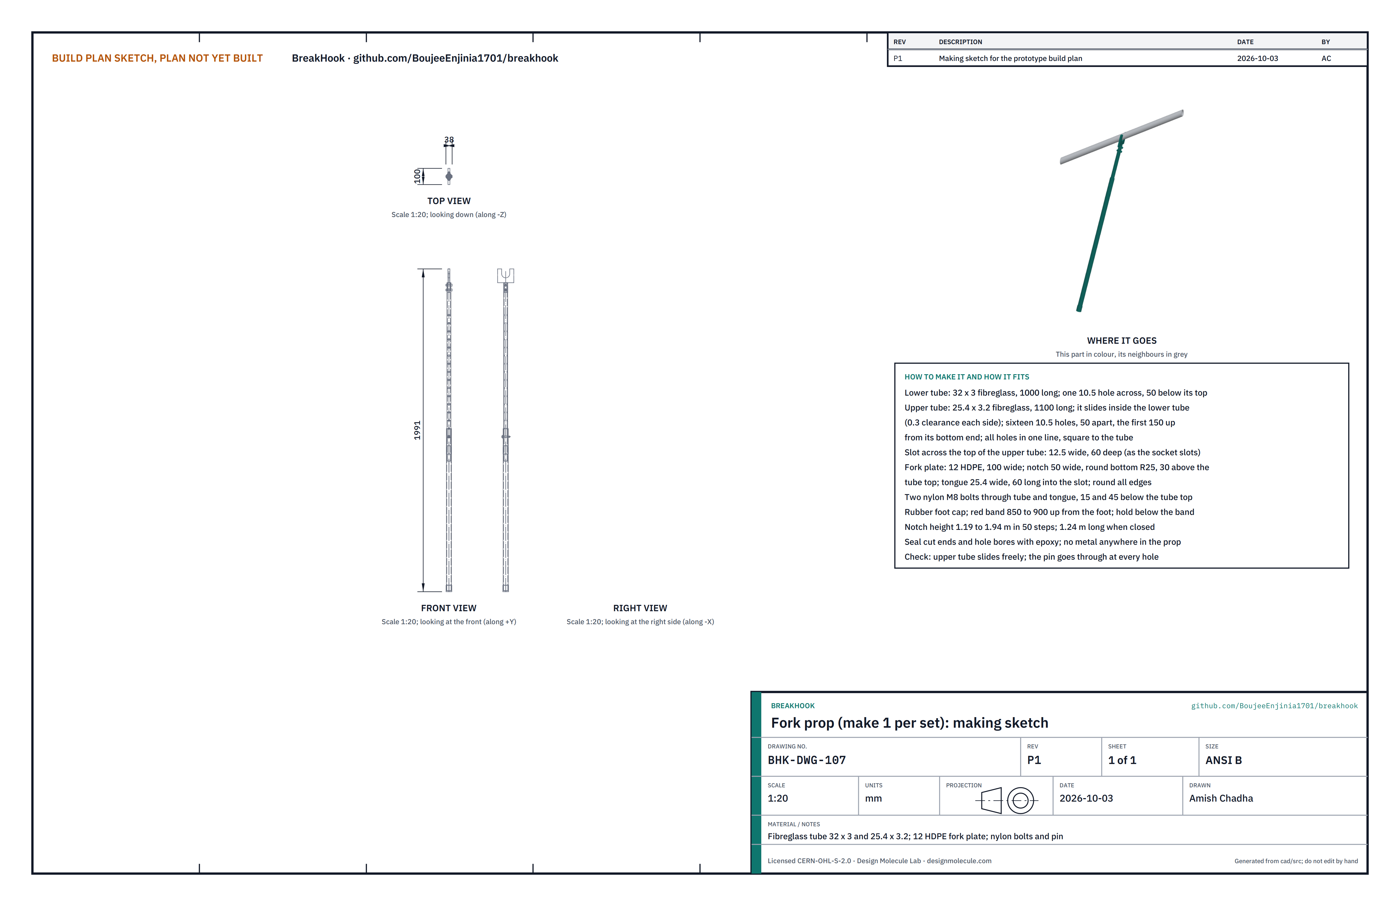
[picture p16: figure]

Figure 14. Fork prop making sketch (BHK-DWG-107).
What it is and what it is made from. A light, adjustable prop with a fork at its top. While the hook is set, the pole lies in the fork at its mid-length, so nobody has to hold the pole out at arm's length. It is carried separately from the pole. It has a lower tube of fibreglass 32 x 3 (the same stock as the toggles), an upper tube of fibreglass 25.4 x 3.2 that slides inside it, a fork plate cut from 12 mm HDPE plastic, two nylon M8 bolts, a nylon setting pin and a rubber foot cap. There is no metal in it.
How to make it.
Cut the lower tube 1000 long and the upper tube 1100 long. Seal the cut ends with epoxy.
Lower tube: drill one 10.5 hole straight across, 50 below its top.
Upper tube: mark a straight line along it and drill sixteen 10.5 holes on that line, 50 apart, the first 150 from its bottom end, all square to the tube. Seal the hole bores with epoxy.
Upper tube: cut a slot straight across its top, 12.5 wide and 60 deep, as for the socket slots (section 3.2), at right angles to the line of holes.
Fork plate: print the profile from the making sketch at full size and cut it from 12 mm HDPE with a jigsaw or coping saw. It is 100 wide; the notch at the top is 50 wide with a round bottom of 25 radius, 30 above the top of the tube; the tongue at the bottom is 25.4 wide and 60 long. Round every edge with a file or scraper.
Push the tongue into the slot until the plate sits on the tube, drill two 8.5 holes through tube and tongue, 15 and 45 below the top of the tube, and fit the nylon bolts and nuts hand tight.

1.
2.
3.

4.

5.

6.

Push the rubber cap on the bottom of the lower tube. Wrap red tape from 850 to 900 up from the foot and shrink a clear sleeve over it, as on the pole.
Slide the upper tube into the lower tube and fit the setting pin through the lower tube's hole and one of the upper tube's holes. Tie the pin to the lower tube with its lanyard.

How it fits the parts next to it. The upper tube slides in the lower tube with about 0.3 clearance all round; the pin sets the height of the fork in 50 steps, from 1.19 m to 1.94 m above the ground (Figure 15). The pole lies loose in the notch with about 2.75 clearance at each side; the fork lifts the pole and never clamps it (Figure 16). In use the prop stands under the middle pole section, about 2.95 m from the butt, leaning about 13° with its top toward the wall. Its holder holds it below the red band.

Figure 15. Cut open: the fork's tongue in the slot with two nylon bolts; the setting pin through both tubes.

7.

8.

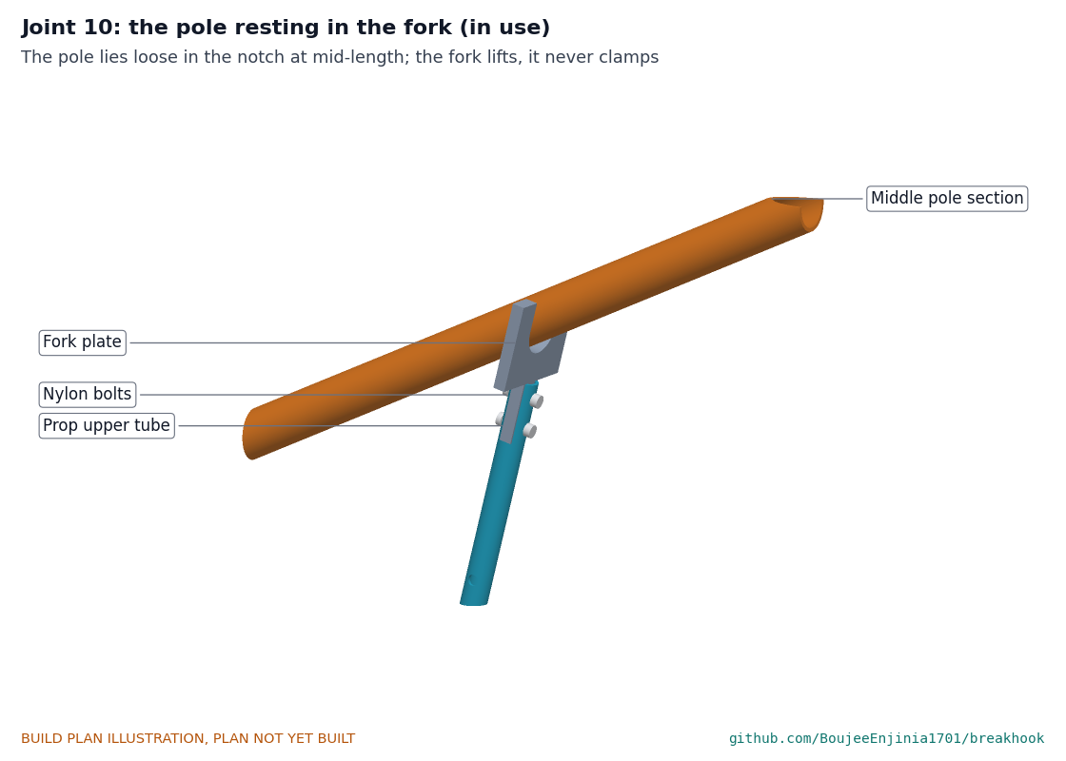
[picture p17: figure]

Figure 16. In use: the middle pole section lies in the notch.
Check before moving on. The upper tube slides in and out by hand at every hole and the pin goes through each of them. The fork plate does not rock in the slot. Closed to its shortest, the prop is about 1.24 m long. Mark the hole for the community's usual wall height with tape.

### 4. Putting it together

In each picture the parts already fitted are grey and the part being fitted is in colour, with an arrow showing the way it goes in. Long parts are drawn cut short around the joint.

Step 1: hook plate into the socket slots

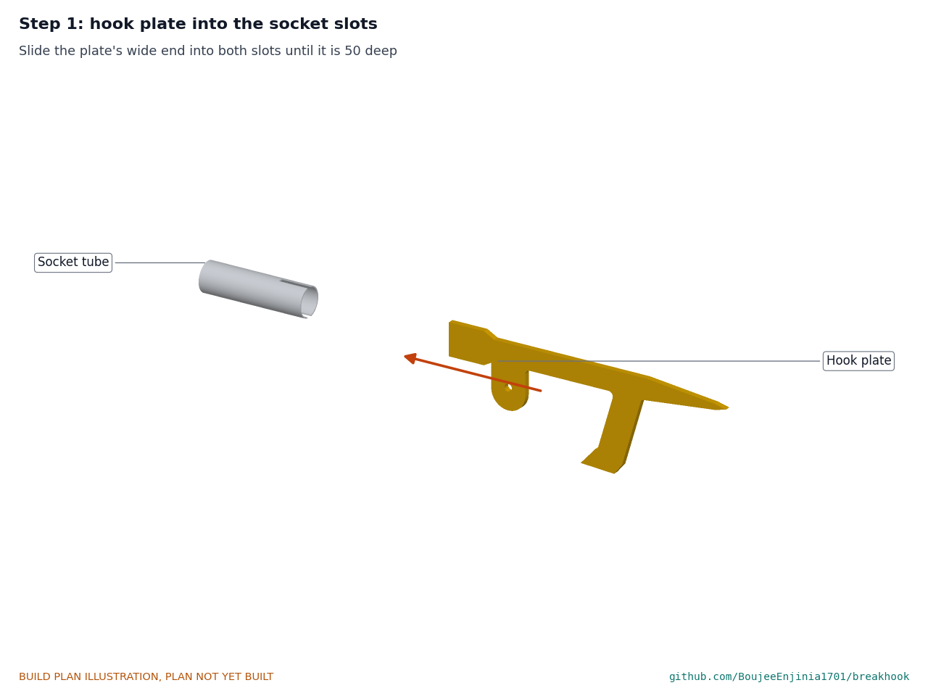
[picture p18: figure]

Slide the plate's wide end into both slots until it bottoms, 50 deep, with the arm pointing down.

Step 2: weld, clean and paint the hook head

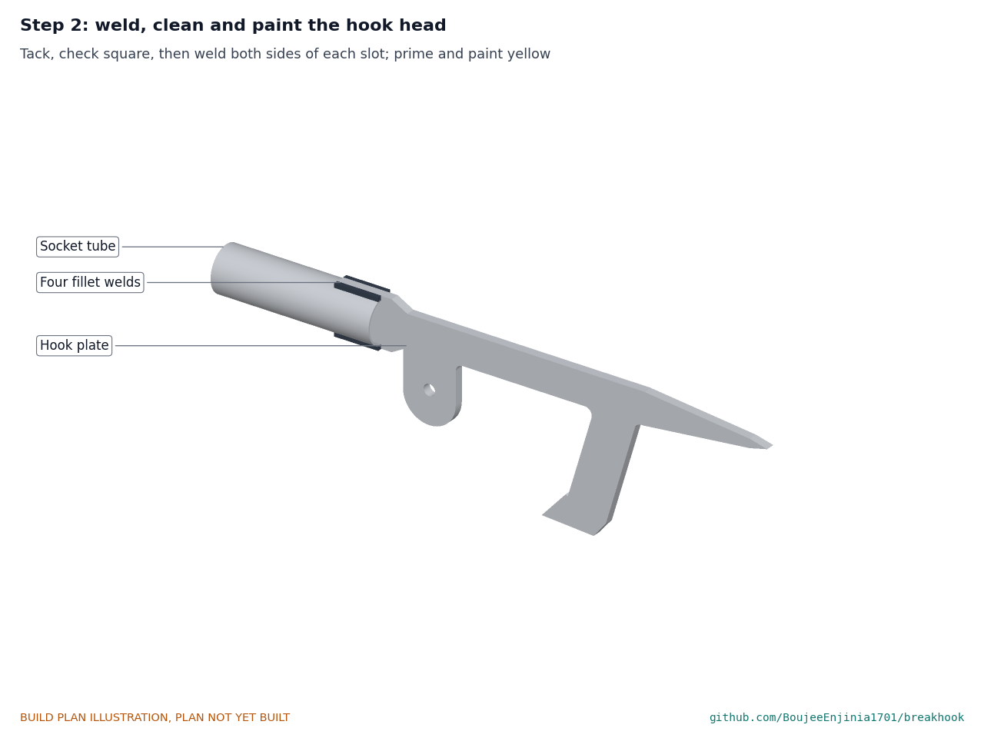
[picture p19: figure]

Tack, check square, then weld both sides of each slot (section 3.2). Hold point: safety stop S1.

Step 3: bond a sleeve onto the butt section

150 onto the top end with epoxy, the drilled half sticking up. Cure a full day.

Step 4: bond a sleeve onto the middle section

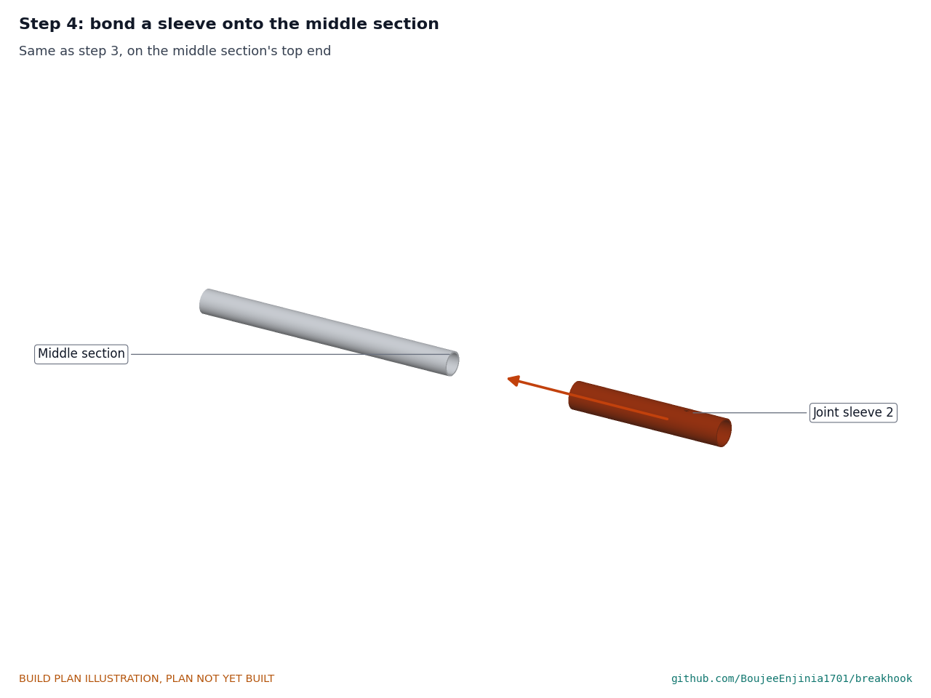
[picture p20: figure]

As Step 3, on the middle section's top end.

Step 5: butt cap and hand band

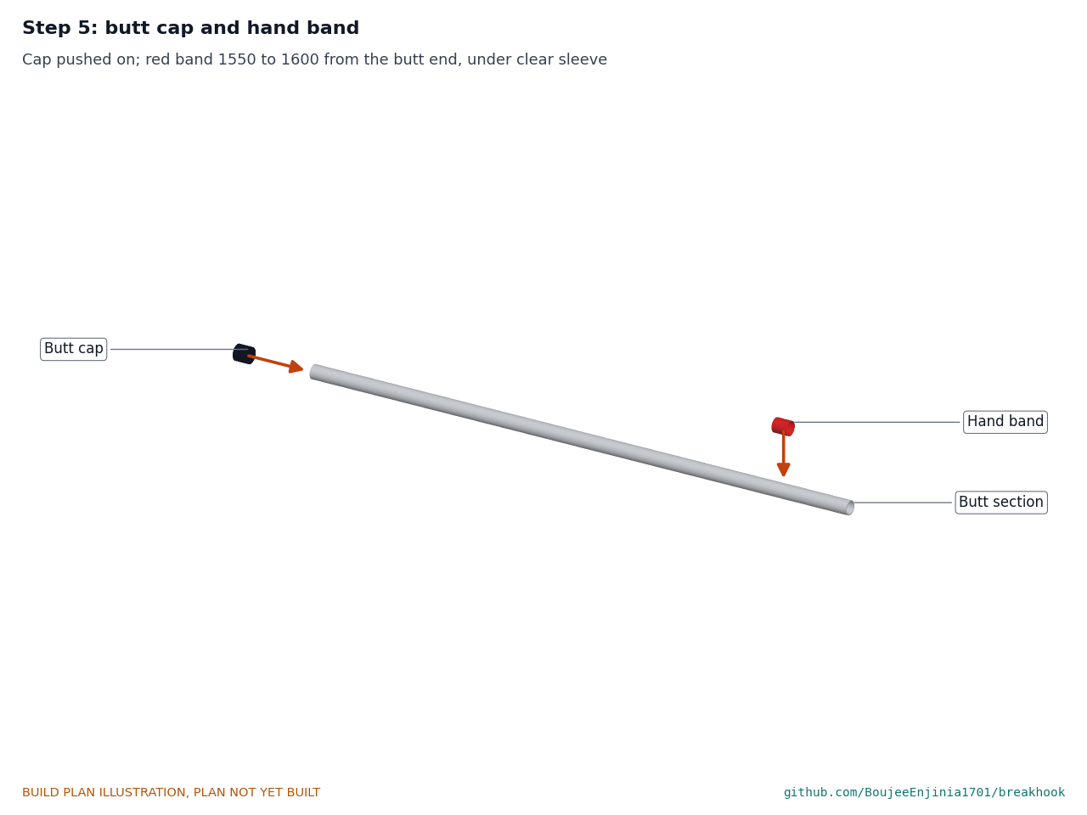
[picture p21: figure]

Push the cap onto the butt end. Wrap red tape from 1550 to 1600 up from the butt end and shrink a clear sleeve over it.

Step 6: friction ring on the top section

Two or three turns of rubber tape, 110 to 150 below the tip, stretched as you wrap.

Step 7: join the butt and middle sections

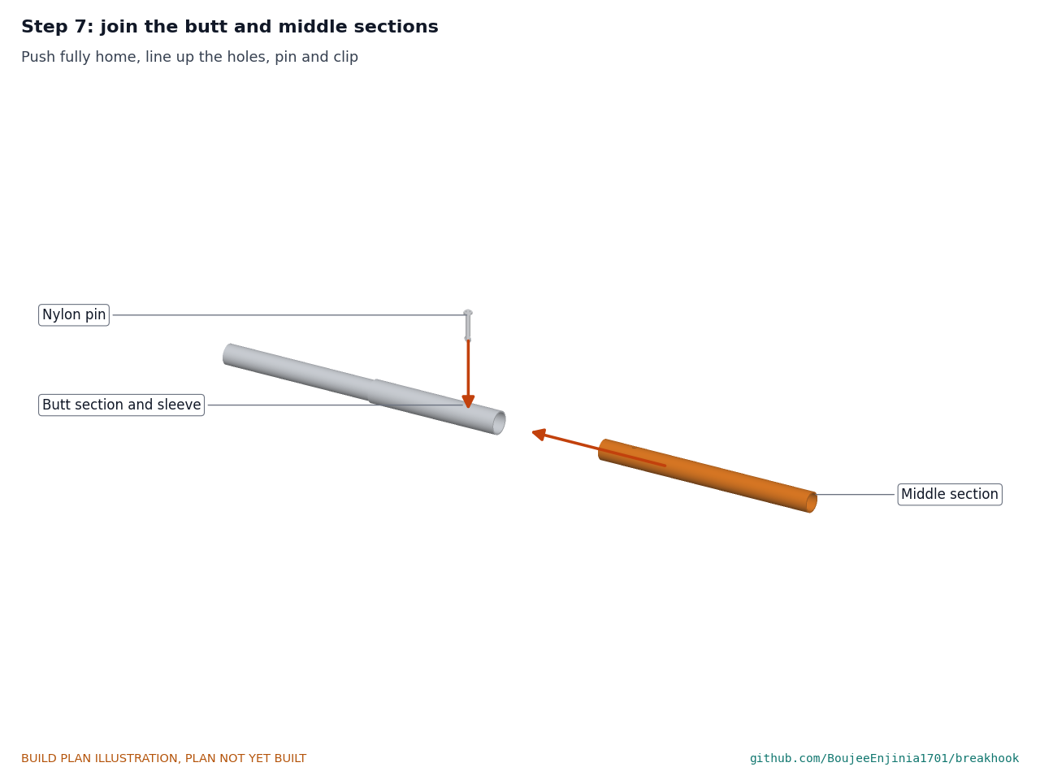
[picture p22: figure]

Push the middle section fully into the sleeve, line up the holes, fit the nylon pin from the top and clip it.

Step 8: join the middle and top sections

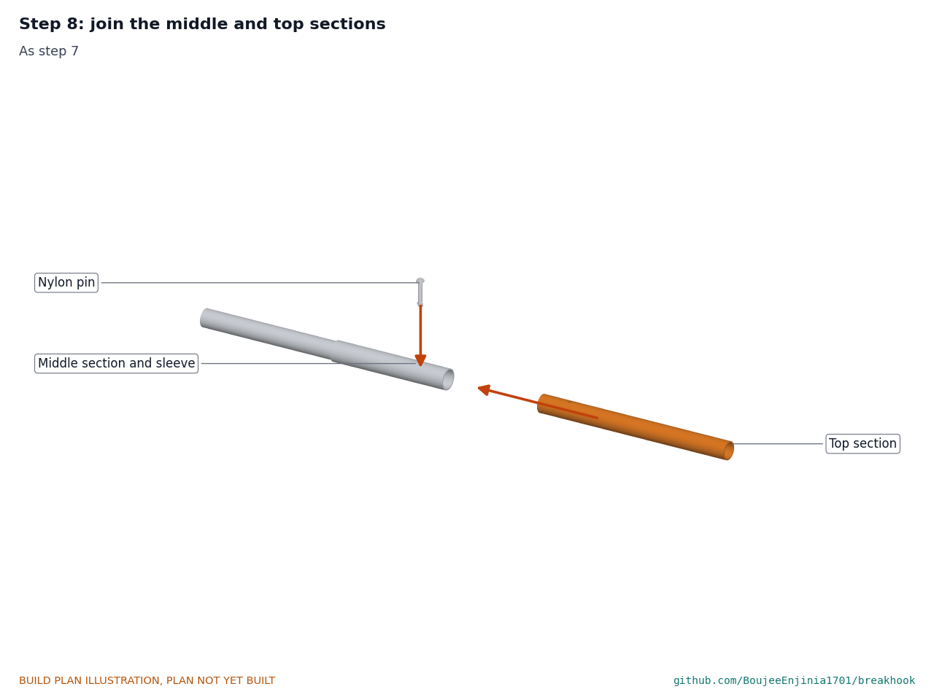
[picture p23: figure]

As Step 7.

Step 9: hook head onto the pole

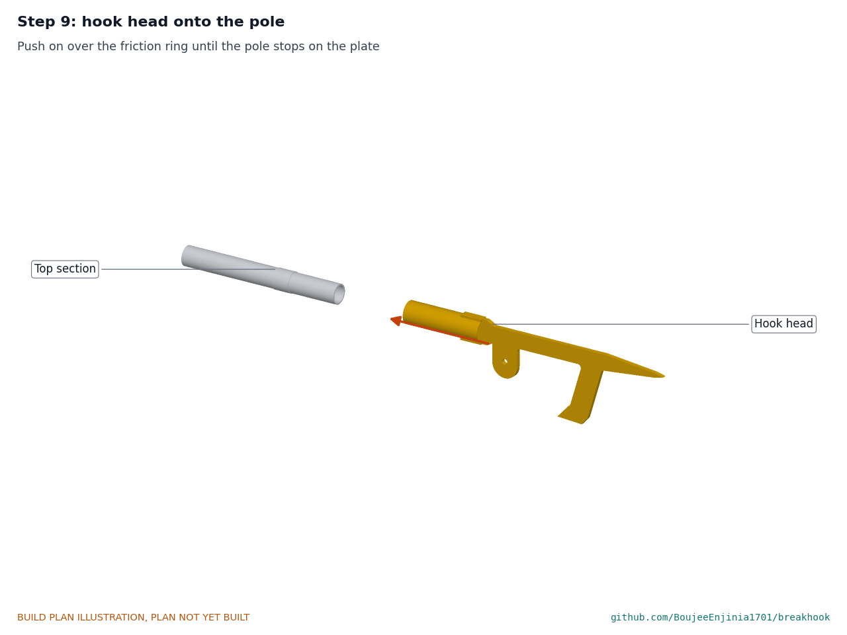
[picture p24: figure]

Push the hook head over the friction ring until the pole stops on the plate. Pull it off and on again: it should need a firm pull of about 50 N (a 5 kg spring balance). Add or remove a turn of tape until it does.

Step 10: shackle and leader onto the hook

Put the leader's eye on the shackle bow, the pin through the 13 mm hole, tighten by hand and mouse it with wire.

Step 11: pull rope onto the leader

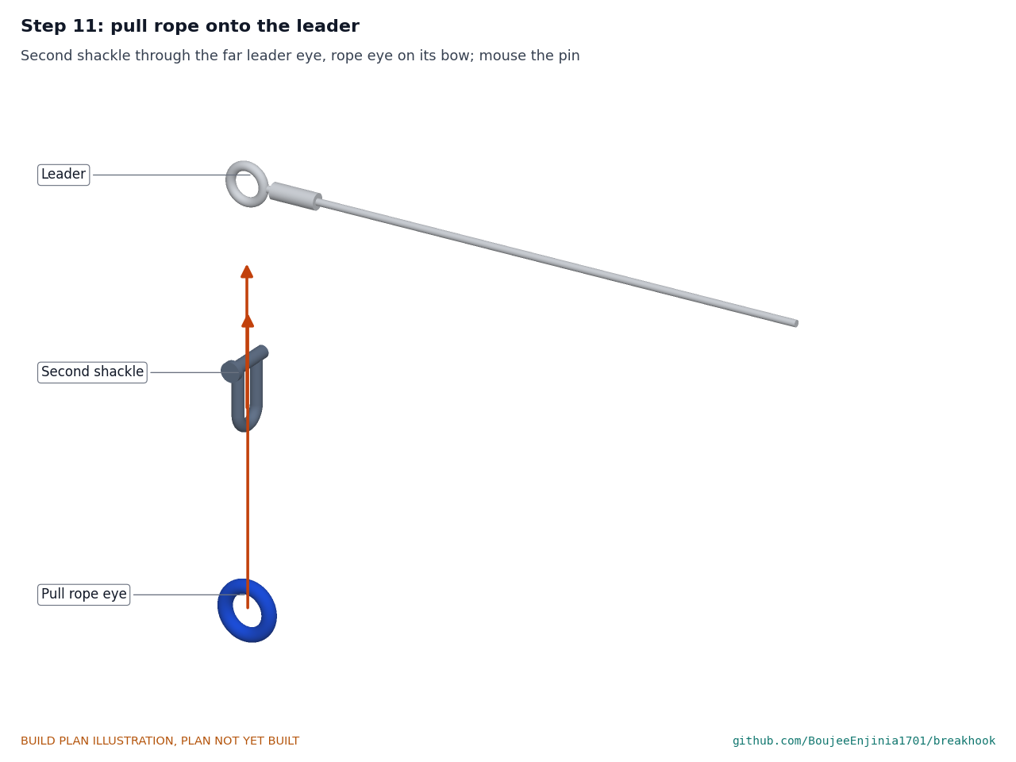
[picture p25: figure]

Second shackle through the far eye of the leader, the rope's spliced eye on its bow; mouse the pin. Hold point: safety stop S2.

Step 12: toggles onto the rope

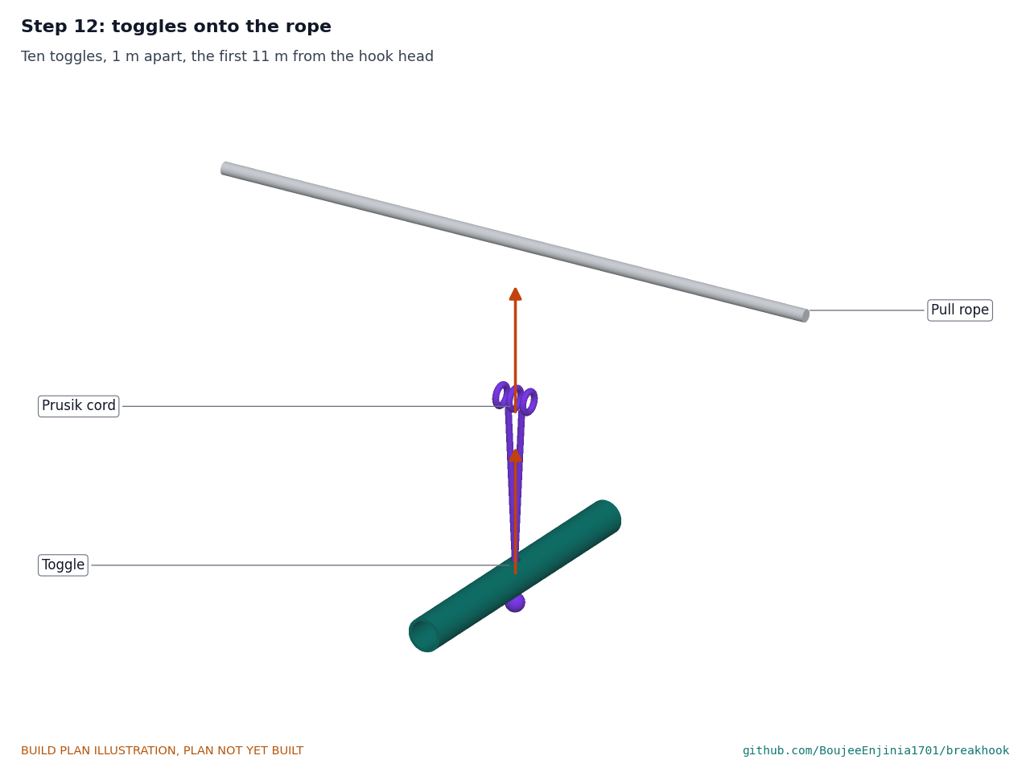
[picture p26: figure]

Ten toggles, 1 m apart, the first 11 m from the hook head.

Step 13: assemble the fork prop

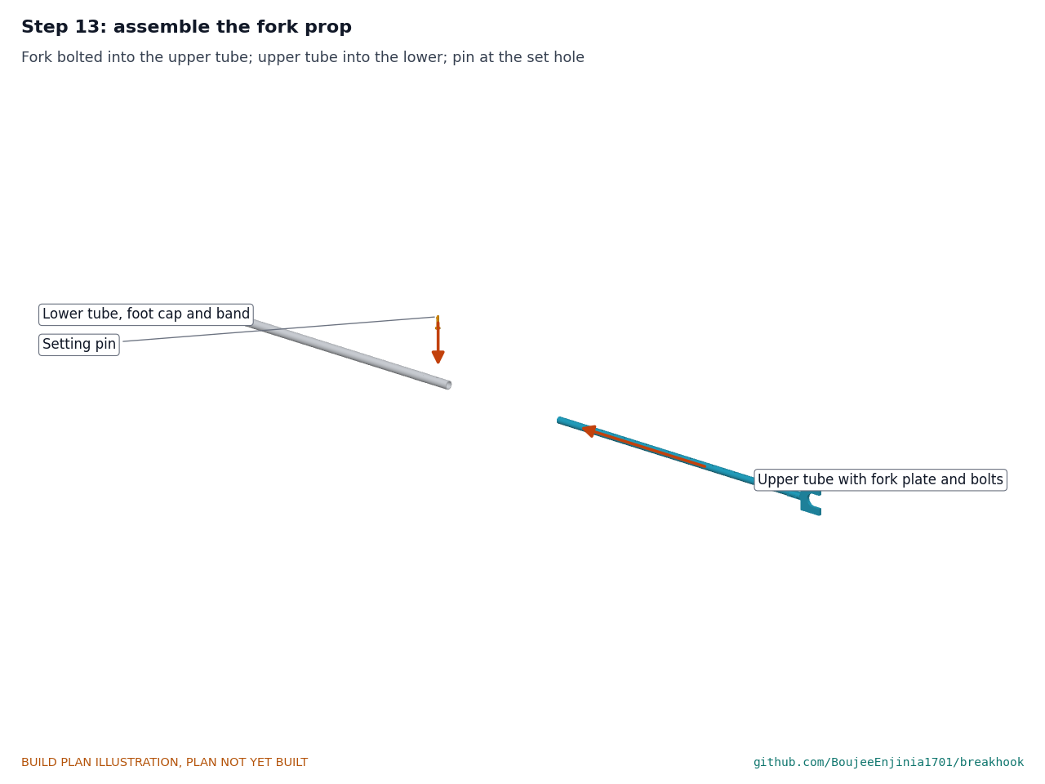
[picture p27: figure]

Fork plate bolted into the top of the upper tube; upper tube into the lower tube; setting pin through the marked hole, clip on (section 3.8).

Step 14: rack uprights onto the wall

1200 apart, plumb, with two M10 anchors each into masonry or coach screws into a timber post.

Step 15: stow the kit, lock and seal


Butt and middle sections on the lower arms, sleeves at alternate ends; top sections with their hook heads, shackles and leaders on the upper arms; the two fork props closed short on the upper arms between the top sections, forks beyond the arm; ropes coiled on the pegs with the toggles. Run the lock cable through every section, both props and both hook eyes, padlock it and fit a numbered seal. Hold point: safety stop S4.

### 5. First checks

These are the checks a TRL 4 test report would record; this plan only lists them. Requirement numbers are those of BHK-REQ-001.
Table 3. First checks.

Check | Requirement How | Pass when
Proof load | R2 | Hook head, shackles and leader
loaded to 6 kN for 1 minute through a 75 x 100 timber in the hook, on CalRig or at a rigging shop

No crack, no visible bend, no weld mark; hook throat opening changes by less than 1 mm

Mass | R5 | Weigh the pole with the hook head 8 kg or less (7.82 kg estimated)
Longest piece | R8 | Measure each section with its sleeve 2.0 m or less
Release | R12 | Spring balance on the pole while the hook head is held Releases at about 50 N
Insulated length and certificate | R4, R14 | Measure from the socket mouth to the top of the band; read the tube certificate 3.0 m or more; certificate to ASTM F711 present
Beam fit | R11 | Hang the hook on 75 x 50 and 100 x 120 timber offcuts Shank rests on top, arm behind, no forcing
Reach | R1 | Pole team sets the hook on a 3 m high timber rail, the pole on the fork prop at mid-length and the rear hand at the butt Hook set in three tries or fewer; droop measured (about 0.27 m expected); distance of each person from the rail measured: pole hands 4 m, prop holder about 2.9 m for about 25 s; confirms the stand-off accepted in BHK- DDR-004
Prop | R1, R8 | Set the prop at each marked hole under the pole; close it Pin goes through at every hole; the prop stands steady at its lean; closed length 1.3 m or less
Toggle grip | R13 | 30 kg hung on a toggle on the rope No slip
Deployment drill | R6 | Four people, kit 100 m from the rail, stopwatch Hook set and pole withdrawn in 3 min or less; the prop holder withdraws with the pole, so nobody stands nearer than the 4 m pole-hand distance at the haul

### 6. Safety stops

Stop at each point. Carry on only when everything listed is true.
S1. Before any weld is loaded. The welds have been looked at by the welder and a second person: full length, no cracks, no undercut at the slot ends. The plate is square to the tube.
S2. Before the first proof load. The rig and the load path are rated above 6 kN; the shackle pins are moused; nobody stands in line with the rope, leader or hook, or within 3 m of the load path; a heavy blanket or mat is laid over the leader to catch it if it parts.
S3. After the proof load. Any bend, crack or shifted ferrule takes that part out of service for good; nothing is straightened and reused.
S4. Before the kit is issued to a community. Proof load passed and tagged for both sets; tube certificate on file; check cards, gloves and fall zone tape in the kit; the community's fire plan, agreed with the fire service, names the keyholders and the caller; training has been given.

•

•

•

•

S5. Before any trial pull (outside this plan). Only on a purpose-built test frame, never an occupied or lived-in structure; the frame checked empty; no overhead lines within 3 m; fall zone taped; pole and fork prop withdrawn and the pole team out of the zone; haulers at least 10 m back, in gloves, on the caller's word.

### 7. Tools, skills and workspace

Tools. Angle grinder with cutting and flap discs, or access to a plasma cutter; bench drill with drills to 16 mm; centre punch and letter stamps; MIG or stick welder; hacksaw; fine-tooth saw for fibreglass; jigsaw or coping saw for the HDPE fork plate; files; coarse abrasive paper and a dowel; tape measure, steel rule, square and calipers; 5 kg spring balance; bathroom or hanging scale; paint brushes; heat gun for the clear sleeve.
Skills. A competent welder for the hook head and rack; basic workshop skills for the rest; knot tying (double fisherman's knot, prusik hitch), which a rigging shop or climbing club can teach. The proof load is done by a rigging shop or on CalRig with someone trained to use it.
Workspace. A metalworking bench with a fire-safe area for welding; an outdoor or ventilated space for cutting and drilling fibreglass; 6 m of clear floor to lay out and join the pole.
Personal protective equipment. Welding helmet, gloves and jacket for hot work; safety glasses for cutting, grinding and drilling; dust mask (FFP2 or N95) and gloves for fibreglass; hearing protection for grinding; rigger gloves for handling rope under load.

### 8. Where the numbers come from

Model and constructability checks: | cad/src/model.py | ( python cad/src/model.py --check ); STEP and STL
exports in | cad/step/ | and | cad/stl/ .
Pictures: | cad/src/build_plan_media.py , using | .kit/build_views.py ; written to | docs/05-build-plan/ | and
cad/drawings/BHK-DWG-101 | to | BHK-DWG-107 .
General arrangement: | cad/drawings/BHK-DWG-001.pdf , Rev P2.
Calculations: | docs/04-calcs/01-sizing.md | (BHK-CAL-001 v0.2) and | docs/04-calcs/sizing.py .
Bill of materials: | bom/bom.csv .
Decisions: | docs/decisions/0001-trl2-review-decisions.md | (BHK-DDR-001)
docs/decisions/0002-design-for-construction.md | (BHK-DDR-002) and | docs/decisions/0003-fork-
prop.md | (BHK-DDR-003).
Requirements: | docs/03-requirements.md | (BHK-REQ-001 v0.3).

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
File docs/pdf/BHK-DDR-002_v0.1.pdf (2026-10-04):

B R E A K H O O K · D E S I G N D E C I S I O N R E C O R D

# BreakHook design for construction

### Design Molecule Lab · designmolecule.com

D O C U M E N T CO N T RO L

Document ID | BHK-DDR-002 | Version | 0.1
Status | Draft | Date | 2026-10-03
Author | Amish Chadha | License | CERN-OHL-S-2.0
Project TRL | TRL 3 | Proof of concept
Repository | github.com/BoujeeEnjinia1701/breakhook
Source | docs/decisions/0002-design-for-construction.md @ uncommitted

R EV I S I O N H I STO RY

Version | Date | Author | Change
0.1 | 2026-10-03 | Amish Chadha | Concept made constructable (STANDARDS section 18), under Amish's 2026-10-03 pre-approval

D R A F T · N O T F O R F A B R I C A T I O N

# 0002: Design for construction

Date: 2026-10-03
Status: accepted
Decided by: Amish Chadha, by pre-approval: "start with the first 14 repos from the list of 29 projects. I preapprove the batch runs along with any recommendations you come up with. I also accept any cost overruns or variations from the assumed scope cost." Standing instruction (2026-09-30): "fix the design assumptions to match and be physically feasible".

Safety: These changes keep every safety feature of the concept: the pole is withdrawn before the haul, there is no metal in the insulated length, and every part in the rope load path is rated and proof-loaded. None of them changes what the product does or its pitch.

## Context

The TRL 2 massing model showed a hook, a pole and a rope in the right proportions but left open how each part is made and how it joins its neighbours. A constructability review of cad/src/model.py checked every pair of parts for overlap (none over 1 mm³ after the changes), every fit (clearances printed by python cad/src/model.py --check ) and the order of assembly.

•
•
•

## Changes

Component | The concept had The constructable design has | Why
Hook head | A forged or fabricated hook with a spike One profile cut from 10 mm S355 plate (spike, 36 mm shank, raked arm, rope tab) | No forging; a local welder can cut it by plasma or by drilling and grinding
Hook to pole | Hook on the end of the pole A 50.8 x 2.0 steel socket, slotted 10.5 x 50 across one end; the plate's 56 mm wide root sits in both slots and stands 2.6 mm proud for four 6 mm fillet welds | Face-to-face, welded joint that a welder can check by eye
Pole in socket | Not defined | Slip fit, 1.15 mm radial clearance, 130 mm deep, stopping on the plate; a rubber tape ring gives a 50 N release

The pole must come off before the haul (BHK-DDR-001, decision 2)

Pole joints | Not defined | External fibreglass sleeve 50.8 x 3.2 x 300, bored to a slip fit, bonded 150 mm to the lower section; nylon 10 mm pin 75 mm above the joint

Foam-filled tube cannot take an internal spigot; nylon keeps metal out of the insulated length

Rope attachment | Pull rope tied to the hook head | 13 mm hole in a rope tab in line with the arm; rated bow shackle; 1.5 m wire rope leader; second shackle to the rope's spliced eye

A knot is weaker and can be cut by sheet edges; the line through the arm keeps the shank in tension

Hook plate | 40 mm shank, 40 mm arm, S275
36 mm shank, 48 mm arm, S355 | The arm on a 100 mm beam was at
1.24 on yield at proof with S275; the narrower shank pays for the wider arm and keeps R5
Hauling handles | Handles or toggles | 300 mm fibreglass toggles on 6 mm prusik cord loops, 1 m apart from 11 m

Movable on the rope, nothing to cut into the rope, and no metal

Pole ends and markings | Not defined | Rubber butt cap; epoxy-sealed ends and pin holes; red hand band 1.55 m from the butt

Keeps water out of the foam; tells the pole team where to hold

Storage rack | Rack and seal | Two welded uprights of 40 x 6 flat bar with lipped arms and a rope peg; poles 56 mm apart with sleeves at alternate ends; coated lock cable, padlock, numbered seal

Every piece rests on an arm and nothing touches its neighbour

## Consequences

Mass rises to 7.82 kg for the pole and hook head, inside the 8 kg limit (BHK-CAL-001 [F10]).
The model, STEP and STL exports, the general arrangement BHK-DWG-001 Rev P1, the making sketches BHK-DWG-101 to 106 and the concept media were regenerated from the constructable model.
design_state: constructable | is set in | project.yaml .
Fits that depend on bought parts (sleeve bore, tube tolerance, shackle jaw) are listed under "To confirm when parts are bought" in BHK-DEC-001.

•
•

•
•

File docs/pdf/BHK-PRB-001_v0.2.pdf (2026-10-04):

B R E A K H O O K · P R O B L E M S TAT E M E N T

# BreakHook problem statement

Design Molecule Lab · designmolecule.com

D O C U M E N T CO N T RO L

Document ID | BHK-PRB-001 | Version | 0.2
Status | Draft | Date | 2026-10-03
Author | Amish Chadha | License | CERN-OHL-S-2.0
Project TRL | TRL 3 | Proof of concept
Repository | github.com/BoujeeEnjinia1701/breakhook
Source | docs/01-problem.md @ uncommitted

R EV I S I O N H I STO RY

Version | Date | Author | Change
0.2 | 2026-10-03 | Amish Chadha | TRL 2 and TRL 3; co-design candidate named; open questions settled under Amish's 2026-10-03 pre-approval (BHK-DDR-001); safety section added
0.1 | 2026-09-30 | Amish Chadha | Initial scaffold

D R A F T · N O T F O R F A B R I C A T I O N

## BreakHook problem statement

In the first minutes of a settlement fire, only residents are there. They know that clearing a gap can stop the spread, but they have no tool that lets them do it from a safe distance.

### The problem

Fire can spread between informal dwellings in under a minute (Stellenbosch University, 2023). (https://www0.sun.ac.za/researchforimpact/2023/10/10/su-fire-engineers-explore-risks-for-humans-and-dwellings/) Fire engines often cannot get in: response times average 68 minutes in informal settlements in the Dhaka and Cape Town study, and pathways can be 60 to 90 cm wide (Royal Academy of Engineering). (https://engineeringx.raeng.org.uk/media/03cd1j4l/engx-a-comparative-study-of-fire-risk-emergence-in-informal-settlements-in-dhaka-and-cape-town-short.pdf) By then a fire can take hundreds or thousands of homes, as at Imizamo Yethu (Imizamo Yethu fire spread analysis). (https://www.sciencedirect.com/science/article/abs/pii/S2212420918307623)
Current responses focus on prevention and access: fire safety education, extinguishers and re-blocking into rows with 3 m gaps, which reduces settlement capacity by at least 20 % (The New Humanitarian, 2013). (https://www.thenewhumanitarian.org/analysis/2013/01/23/south-africa-searches-solutions-shack-fires) Community responders, trained by groups such as the Kenya Red Cross, use buckets and basins and pull structures down by hand (Ngau and Boit, 2020). (https://journals.sagepub.com/doi/10.1177/0956247820924939) The historical fire hook was built for exactly this job (London Fire Brigade Museum), (https://www.london-fire.gov.uk/museum/london-fire-brigade-history-and-stories/fires-and-incidents-that-changed-history/the-great-fire-of-london/) but no open, tested version exists for these communities.

### Users and context

User | Need | Context
Community fire responders | Pull a structure down from a safe distance to open a firebreak | First minutes of a fire, crowds, smoke, narrow paths
Settlement committees and ward leaders | A tool they can store, assign and govern, with a clear rule on when it may be used | Community fire plans and training days
Municipal fire services and reservist programmes | Equipment to issue to trained community reservists | City fire and disaster management
NGOs and Red Cross societies | A low-cost kit item with training material | Community fire response training

### Operating environment

Dense settlements of closely spaced, mostly single-storey dwellings (assumed; to be confirmed with the partner).
Paths about 0.6 to 0.9 m (2 to 3 ft) wide in places (Royal Academy of Engineering). (https://engineeringx.raeng.org.uk/media/03cd1j4l/engx-a-comparative-study-of-fire-risk-emergence-in-informal-settlements-in-dhaka-and-cape-town-short.pdf)
Smoke, radiant heat, crowds and panic during use.
Overhead and informal electrical wiring may be present.
Stored outdoors or in a shared shed for long periods between uses.

### Constraints

Prototype parts budget: USD 2,000 or less for a community kit.
Pole must be non-conductive along the handled length.
Light enough to carry and for a team of two to lift into place: 8 kg (18 lb) or less for the pole and hook head.

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
Short enough in sections to move along narrow paths.
Buildable by a local welder from stock steel plus commercial fibreglass tube and rope.
Open design: hardware under CERN-OHL-S-2.0, training material under a matching open licence.

### Out of scope

Fire suppression equipment, alarms and detectors.
Demolition outside an active fire emergency.
Multi-storey or masonry buildings.
Rules on who may authorise pulling down a home; that is for each community and its local authority.

### Prior work

Prior work | What it does | Gap for these users | Source
Historical fire hooks | Long hooks used to pull down buildings in the path of a fire, as in London in 1666 | No modern, documented, non- conductive version sized for informal dwellings | link (https://www.london-fire.gov.uk/museum/london-fire-brigade-history-and-stories/fires-and-incidents-that-changed-history/the-great-fire-of-london/)

Community fire
response in Nairobi

Residents trained by the Kenya Red Cross use buckets and tear down structures to make firebreaks

Done by hand, close to the fire, with no purpose-made tool

link (https://journals.sagepub.com/doi/10.1177/0956247820924939)

Re-blocking (Cape
Town)

Rebuilding settlements in rows with 3 m gaps for access and fire separation

Slow, costly, reduces capacity; no help once a fire has started

link (https://www.thenewhumanitarian.org/analysis/2013/01/23/south-africa-searches-solutions-shack-fires)

### Co-design

A municipal fire service reservist programme or a Red Cross or Red Crescent society already training community fire responders in informal settlements, working with a settlement committee that can set rules for when the tool is used.
First candidate to approach (not agreed): the City of Cape Town Fire and Rescue Service and its volunteer reservists, with a settlement committee in the Western Cape. Second candidate: the Kenya Red Cross Society's community fire response work in Nairobi (BHK-DDR-001).
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

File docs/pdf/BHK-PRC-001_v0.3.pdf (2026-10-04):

B R E A K H O O K · P R E C I S

# BreakHook design precis

Design Molecule Lab · designmolecule.com

D O C U M E N T CO N T RO L

Document ID | BHK-PRC-001 | Version | 0.3
Status | Draft | Date | 2026-10-03
Author | Amish Chadha | License | CERN-OHL-S-2.0
Project TRL | TRL 3 | Proof of concept
Repository | github.com/BoujeeEnjinia1701/breakhook
Source | docs/02-concept.md @ uncommitted

R EV I S I O N H I STO RY

Version | Date | Author | Change
0.3 | 2026-10-03 | Amish Chadha

Fork prop at mid-length added under Amish's decision 6A (BHK-DDR-003); droop and cost updated from BHK-CAL-001 v0.2

0.2 | 2026-10-03 | Amish Chadha | TRL 2 and TRL 3 on the constructable design; decisions under Amish's 2026-10-03 pre-approval (BHK- DDR-001, BHK-DDR-002); numbers from BHK-CAL-001
0.1 | 2026-09-30 | Amish Chadha | Initial scaffold
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

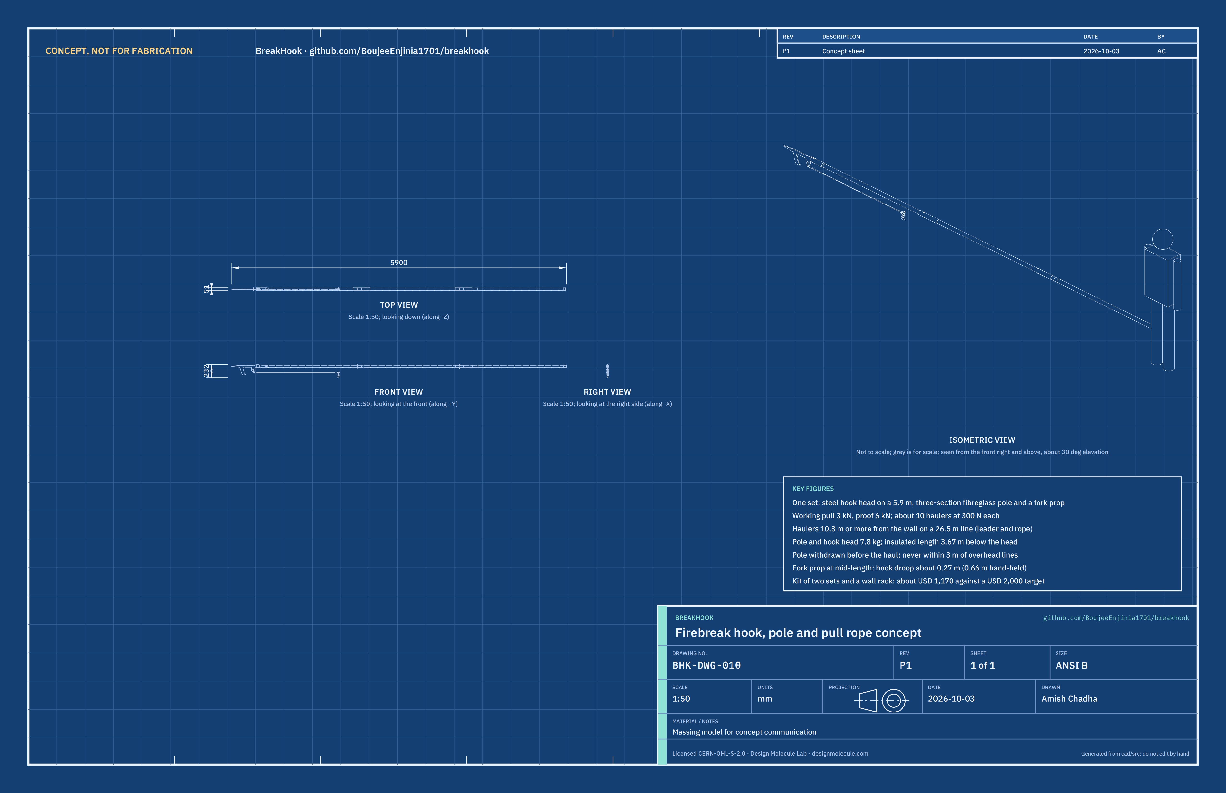
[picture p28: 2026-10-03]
media/concept-blueprint.png

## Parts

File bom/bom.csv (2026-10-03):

item | qty | spec | supplier | unit_cost_usd | make_buy | notes
1 Hook plate | 2 | 10 mm S355 steel plate, blank 500 x 200 mm, profile cut to BHK-DWG-101 (plasma, or drill and grinder), 13 mm shackle hole, edges dressed | Local steel stockist; cutting by a local welder or plasma service | 14.00 | make | Indicative price for the blank; one per set, two sets per community kit (BHK-DDR-002)
2 Socket tube | 2 | Welded steel tube 50.8 x 2.0 mm (2 in x 14 gauge), 180 mm long, two 10.5 x 50 mm slots across one end (BHK-DWG-102) | Local steel stockist | 3.00 | make | Indicative price; the pole slides into it with 1.15 mm radial clearance
3 Hook head welding and finishing | 2 | Fit plate into socket slots, four 6 mm fillet welds, zinc-rich primer and high-visibility yellow topcoat, stamp WLL 3 kN and serial number | Local welder (about 1 h per head) | 40.00 | make | Indicative local labour rate; welder works from BHK-DWG-101 and 102
4 Pole section | 6 | Pultruded fibreglass round tube 44.5 x 3.2 mm (1.75 x 0.125 in), foam filled, electrical grade with a dielectric test certificate to ASTM F711 from the maker, UV-inhibited surface, cut to 1800 mm (BHK-DWG-103) | Fibreglass tube maker or live-line tool distributor | 45.00 | make | Indicative price per 1.8 m section, three per set; electrical grade and foam fill per BHK-DDR-001
5 Joint sleeve | 4 | Pultruded fibreglass round tube 50.8 x 3.2 mm (2 x 0.125 in), 300 mm long, bore sanded to a slip fit on item 4 (BHK-DWG-104) | Fibreglass tube maker | 8.00 | make | Indicative price; two per set; bonded 150 mm onto the lower section with item 7
6 Joint pin | 4 | Nylon 66 clevis pin 10 mm diameter, 70 mm grip, with nylon hitch clip and a cord lanyard | Industrial fastener distributor | 3.00 | buy | Indicative price; no metal in the insulated length
7 Structural epoxy | 1 | Two-part structural epoxy for composites, 50 ml cartridge, lap shear strength 15 MPa or more | Hardware or composites supplier | 15.00 | buy | Indicative price; bonds item 5 to item 4
8 Friction ring tape | 1 | Self-amalgamating rubber tape 25 mm x 10 m roll | Electrical distributor | 8.00 | buy | Indicative price; two or three turns on each pole tip; set to a 50 N push-off by trial
9 Hand band | 1 | Red vinyl tape 50 mm and clear heat-shrink sleeve 50 mm diameter, 0.5 m | Electrical distributor | 6.00 | buy | Indicative price; marks the top of the hand zone 1550 mm from the butt
10 Butt cap | 2 | Rubber end cap for 44.5 mm tube, 46 mm deep | Hardware supplier | 3.00 | buy | Indicative price
11 Shackle | 4 | 3/8 in (10 mm) screw-pin bow shackle, galvanised, rated WLL 1 t, marked with grade and WLL | Rigging supplier | 7.00 | buy | Indicative price; two per set (hook eye and leader to rope)
12 Wire rope leader | 2 | 6 mm 6x19 galvanised wire rope, breaking strength 20 kN or more, 1.5 m between eyes, thimble eye and pressed ferrule each end, proof tested and tagged by the rigging shop | Rigging shop | 25.00 | buy | Indicative price; keeps heat and sheet edges off the pull rope
13 Pull rope | 2 | 12 mm polyester double braid, breaking strength 25 kN or more, 25 m, spliced eye at one end, whipped tail | Rope or marine supplier | 70.00 | buy | Indicative price
14 Hauling toggle | 20 | Fibreglass tube 32 x 3 mm, 300 mm long, 10 mm cross hole at mid length, ends rounded (BHK-DWG-105) | Fibreglass tube maker | 3.00 | make | Indicative price; ten per set, cut from a 6 m length
15 Prusik cord | 20 | 6 mm polyester accessory cord, breaking strength 7 kN or more, 1.2 m, tied into a loop through item 14 | Rope or outdoor supplier | 2.00 | buy | Indicative price; ten per set
16 Rack upright | 2 | 40 x 6 mm steel flat bar: upright 800 mm, two arms 250 mm with 30 mm lips, rope peg 150 mm with 40 mm lip, welded, primed and painted (BHK-DWG-106) | Local welder | 25.00 | make | Indicative price including welding; one rack holds a community kit of two sets
17 Wall anchor | 4 | M10 sleeve anchor for masonry, or M10 coach screw for timber, with washer | Hardware supplier | 2.00 | buy | Indicative price; two per upright
18 Paint | 1 | Zinc-rich primer and high-visibility yellow enamel, 0.5 l each | Hardware supplier | 25.00 | buy | Indicative price; hook heads and rack
19 Lock cable and padlock | 1 | 5 mm plastic-coated steel cable 2.5 m with looped ends and a padlock, keys held by two named keyholders | Hardware supplier | 25.00 | buy | Indicative price; through every section and both hook eyes on the rack
20 Numbered seals | 1 | Pull-tight numbered plastic security seals, pack of 100 | Security or logistics supplier | 15.00 | buy | Indicative price; a broken seal shows the kit has been used or opened
21 Fall zone tape | 2 | Red and white barrier tape 75 mm x 100 m | Hardware or safety supplier | 12.00 | buy | Indicative price
22 Fall zone stake | 8 | Fibreglass marker stake 1.2 m with a pointed foot | Hardware or safety supplier | 4.00 | buy | Indicative price; four marks the corners of a fall zone
23 Check card | 6 | Printed A5 card, both sides, laminated, on a lanyard: empty-dwelling check, wire check, fall zone, signal words, stop rule | Local printer | 3.00 | buy | Indicative price; artwork released with the training material
24 Rigger gloves | 12 | Leather rigger gloves, pair | Safety supplier | 5.00 | buy | Indicative price; ten haulers and two on the pole
25 Proof load and tag | 2 | Each hook head with its leader and shackles loaded to 6 kN for 1 min and tagged, at a rigging shop or with the CalRig proof-load rig | Rigging shop or CalRig | 30.00 | buy | Indicative service price; done before the kit is issued
26 Fork prop lower tube | 2 | Fibreglass round tube 32 x 3 mm, 1000 mm long, one 10.5 mm cross hole 50 mm below the top, ends sealed (BHK-DWG-107) | Fibreglass tube maker | 10.00 | make | Price basis: the toggle stock of line 14 (USD 3.00 per 300 mm, about USD 10 per metre); one per set (BHK-DDR-003)
27 Fork prop upper tube | 2 | Fibreglass round tube 25.4 x 3.2 mm (1 x 0.125 in), 1100 mm long, sixteen 10.5 mm setting holes 50 mm apart from 150 mm above the foot, 12.5 x 60 mm slot across the top (BHK-DWG-107) | Fibreglass tube maker | 12.00 | make | Price basis: indicative USD 10 to 11 per metre for 1 in pultruded tube, plus cutting; slides in line 26 with 0.3 mm radial clearance
28 Fork plate | 2 | 12 mm HDPE plate, profile cut 100 x 145 mm with a 50 mm wide round-bottomed notch and a 25.4 x 60 mm tongue (BHK-DWG-107) | Plastics stockist; cut by hand or router | 6.00 | make | Price basis: indicative offcut price for 12 mm HDPE sheet; no metal at the pole
29 Fork bolt | 4 | Nylon 66 hex bolt M8 x 40 with nylon nut and washer | Industrial fastener distributor | 1.50 | buy | Price basis: indicative distributor price for nylon M8 bolt sets; two per prop
30 Prop setting pin | 2 | Nylon 66 clevis pin 10 mm diameter, 40 mm grip, with nylon hitch clip and a cord lanyard | Industrial fastener distributor | 3.00 | buy | Price basis: same pin family as line 6
31 Prop foot cap | 2 | Rubber end cap for 32 mm tube, 40 mm deep | Hardware supplier | 2.00 | buy | Price basis: as line 10, smaller size; the red hand band on the prop comes from the line 9 roll

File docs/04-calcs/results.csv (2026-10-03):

ref | quantity | value | unit | note
A1 | Pull to overturn the dwelling as a rigid box | 2.146 | kN | 350 kg, 3.0 m base, pulled at 2.4 m
A2 | Pull to rack an unbraced clad frame | 3 | kN | assumed 0.5 kN per metre of side wall for nailed light cladding
A3 | Design working pull (R2) | 3 | kN | covers A1 and A2
A4 | Proof load (R2) | 6 | kN | 2 x working pull
A5 | Haulers needed at the working pull | 10 | people | assumed 300 N sustained per person on a rope with toggles
A6 | Haulers needed for the overturning case | 8 | people
B1 | Nearest hauler, horizontal distance from the wall | 10.82 | m | first toggle 11 m along the line, hook at 3.0 m, hands at 1.0 m
B2 | Required by R3 (1.5 x structure height) | 4.5 | m
B3 | Rope angle below horizontal at the first hauler | 10.48 | deg
B4 | Horizontal share of the pull | 98.33 | %
B5 | Last toggle along the line | 20 | m | toggles 1 m apart; line 26.5 m long
B6 | Tail left for anchoring or a turn round a post | 6.5 | m
C1 | Arm rake back from square to the shank | 16.65 | deg
C2 | Arm root bending stress, 75 mm deep beam | 97.88 | MPa | lever 58 mm; factor on yield 3.63 at proof, 7.25 at working
C3 | Arm root bending stress, 100 mm deep beam | 153.2 | MPa | lever 90 mm; factor on yield 2.32 at proof, 4.63 at working
C4 | Shank tension plus bending from the 0.5 mm line offset | 18.06 | MPa | factor on yield 19.7
C5 | Eye tear-out shear stress | 12.77 | MPa | two planes 23.5 mm long
C6 | Pin bearing stress on the plate | 54.55 | MPa
C7 | Tab root bending stress | 37 | MPa
C8 | Throat width at the shank (between tab and arm) | 150 | mm | after the 8 mm corner radius
C9 | Throat width 100 mm below the shank | 128.1 | mm
C10 | Arm reach below the shank (beam depth it can hold) | 117 | mm
D1 | Weld stress from a 200 N side load at the spike tip | 4.593 | MPa | 4 fillet welds, 6 mm leg, 50 mm long
D2 | Rope load through the socket welds | 0 | kN | the rope pulls the plate, not the socket
E1 | Pull rope factor of safety at the working pull | 7.5 |  | 12 mm polyester double braid, breaking strength 25 kN or more, spliced eye 90 %
E2 | Leader factor of safety at the working pull | 6 |  | 6 mm 6x19 galvanised wire rope, 20 kN, pressed ferrules 90 %
E3 | Shackle working load limit against the working pull | 3.267 |  | 3/8 in (10 mm) bow shackle, 1 t
E4 | Load per prusik cord at the working pull | 300 | N | 6 mm cord, about 7 kN breaking
F1 | Pole elevation when the hook is set at 3.0 m from 4.0 m away | 25.41 | deg
F2 | Front hand from the butt | 1269 | mm | must be below the hand band
F3 | Hand band from the butt | 1550 | mm
F4 | Pole set weight (pole, head, leader, hanging rope) | 84.14 | N
F5 | Rear hand pushes down with | 168 | N | hands 1.17 m apart
F6 | Front hand lifts | 252.2 | N | two-person pole team: one lifts, one holds the butt down
F7 | Pole bending stress at the front hand | 50.59 | MPa | factor 4.0 on 200 MPa
F8 | Droop of the hook at the reach point | 657.9 | mm | aim this much high, then lower onto the beam
F9 | Pole tube second moment of area | 8.906 | cm^4
F10 | Pole and hook head mass (R5) | 7.821 | kg | target 8 kg or less
F11 | Margin on R5 | 0.1792 | kg
F12 | Longest piece to carry (R8) | 1.95 | m | a section with its bonded sleeve
F13 | Prop position along the pole, from the butt | 2944 | mm | mid-length of the 5.9 m set
F14 | Height of the pole underside at the prop | 1.794 | m
F15 | Prop setting hole and lean | 12.83 | deg | hole 3 of 16, fork notch 1.836 m above the foot
F16 | Droop of the hook at the reach point, pole on the prop | 274 | mm | against 658 mm hand-held [F8]
F17 | Load on the prop | 100.3 | N | into the ground through the foot; the prop holder only steadies it
F18 | Rear hand at the butt | -24.28 | N | negative: pushes down
F19 | Prop foot from the wall (prop holder stands here or behind) | 2.894 | m | R1 front hand: 4.0 m
F20 | Butt (rear hand) from the wall | 5.056 | m
F21 | Prop buckling load (upper tube over the whole length, pinned ends) | 821.8 | N | factor 8 on the prop load
F22 | Fork prop mass, carried separately | 1.08 | kg | not part of R5
F23 | Alternative: prop placed so its foot is 4.0 m from the wall, position from the butt | 1578 | mm
F24 | Alternative: droop with that prop position | 720.2 | mm | prop load 193 N; prop 1.24 m long at 13 deg
G1 | Set force to pull the pole out of the hook head | 50 | N | friction ring wrapped until this is reached (set by trial); 4 x the hook head weight along the pole
G2 | Hook head weight along the pole at 25 deg | 10.93 | N | the ring must hold more than this
G3 | Ring contact pressure that gives G1 | 0.01788 | MPa | friction 0.5 (assumed)
G4 | Joint pin double-shear capacity | 6283 | N | nylon 66, 40 MPa in shear
G5 | Pin capacity against the pull-out force | 125.7 |  | pins never carry the rope pull
G6 | Bonded sleeve capacity | 104.9 | kN | 150 mm overlap, 5 MPa allowable epoxy shear
H1 | Insulated length, socket mouth to hand band | 3674 | mm | no metal in this length; pins are nylon
H2 | Required by R14 | 3000 | mm
H3 | Insulated path to the prop holder's hand: pole from the socket mouth to the fork, then the prop down to its hand band | 3266 | mm | fibreglass, HDPE and nylon only
I1 | Store to hook set, pole team of two (R6) | 3 | min | the other two lay out the rope and run the check card in parallel
I2 | Hook set to frame down (R7) | 1.167 | min | estimate; set by a timed trial at TRL 4

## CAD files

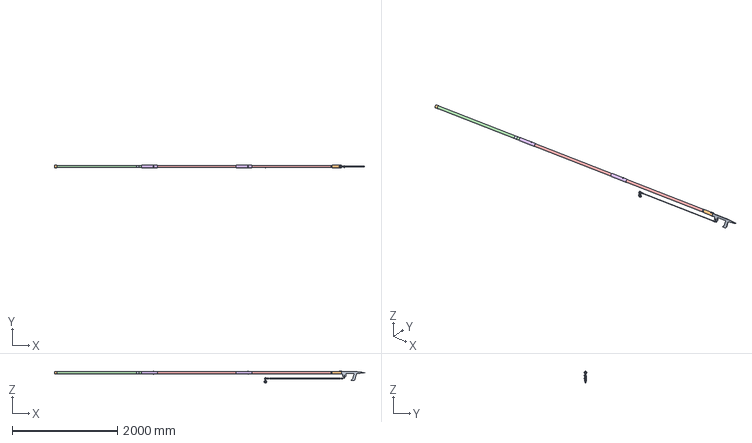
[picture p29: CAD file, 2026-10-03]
cad/step/breakhook-assembly.step
5900.0 x 50.8 x 232.2 mm

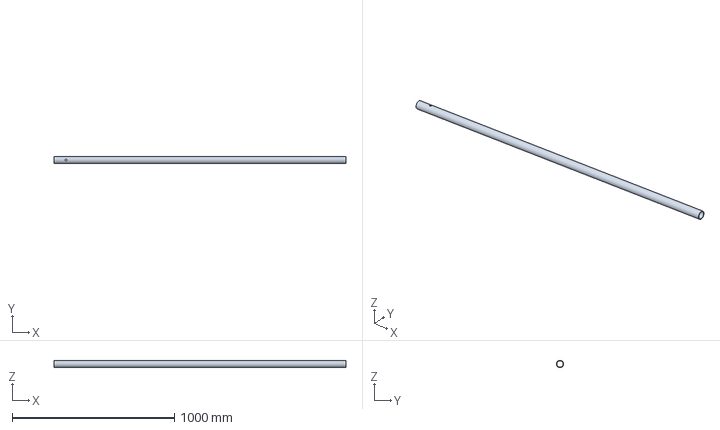
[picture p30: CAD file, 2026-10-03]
cad/step/pole-section-middle.step
1800.0 x 44.5 x 44.5 mm

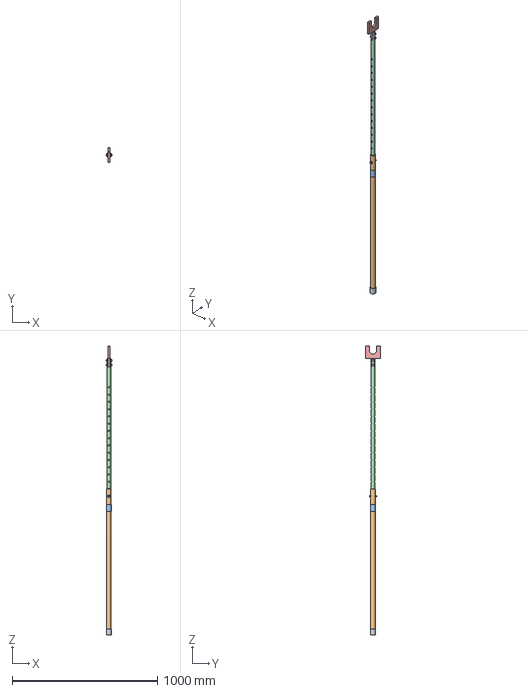
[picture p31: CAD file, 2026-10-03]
cad/step/fork-prop.step
38.4 x 100.0 x 1991.0 mm

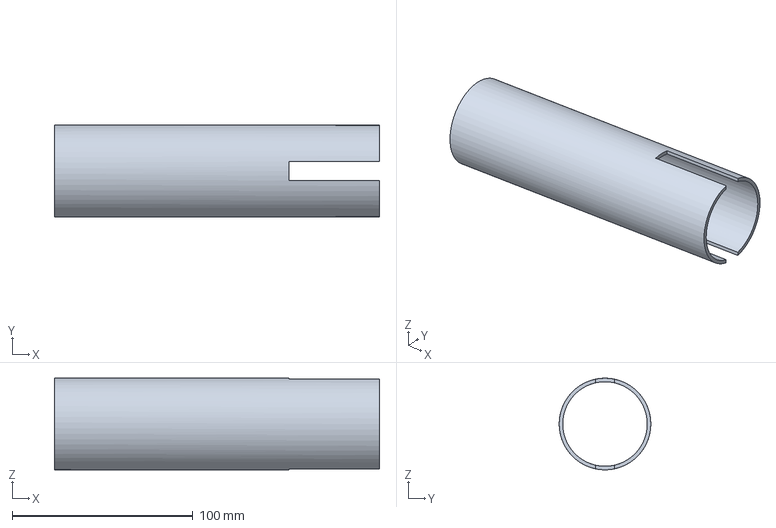
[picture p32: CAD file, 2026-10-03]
cad/step/socket.step
180.0 x 50.8 x 50.8 mm

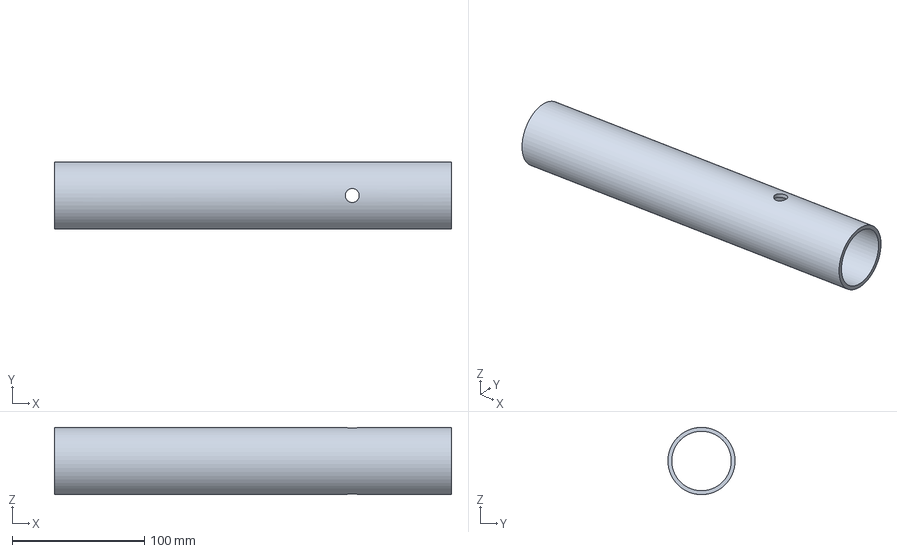
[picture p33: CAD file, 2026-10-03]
cad/step/joint-sleeve.step
300.0 x 50.8 x 50.8 mm

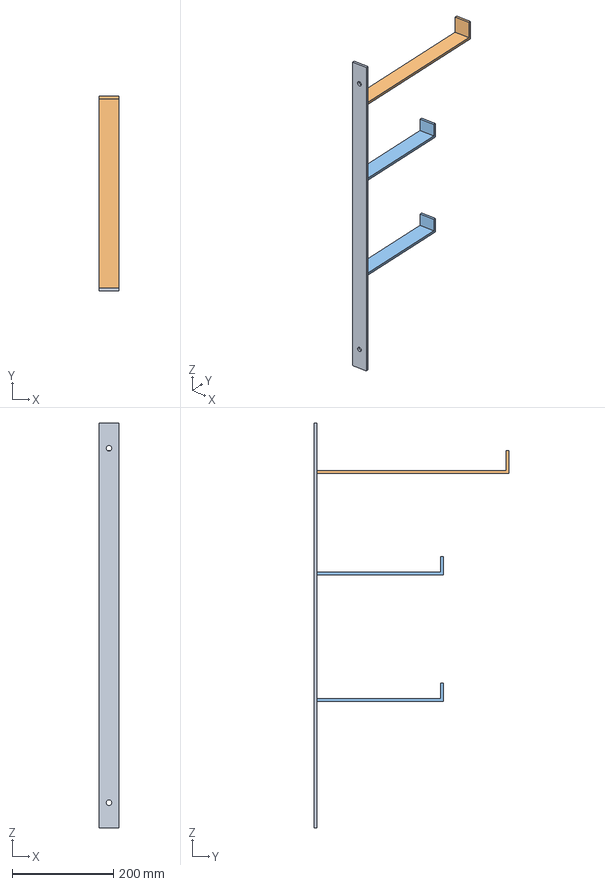
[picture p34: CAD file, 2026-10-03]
cad/step/rack-upright.step
40.0 x 386.0 x 800.0 mm

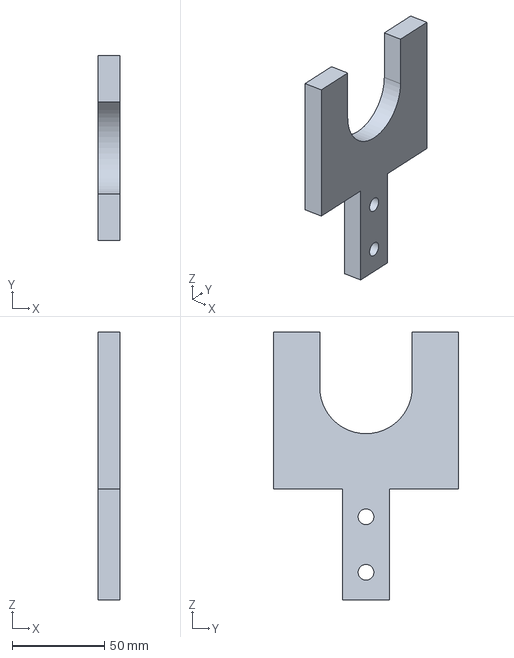
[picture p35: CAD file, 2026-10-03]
cad/step/fork-prop-plate.step
12.0 x 100.0 x 145.0 mm

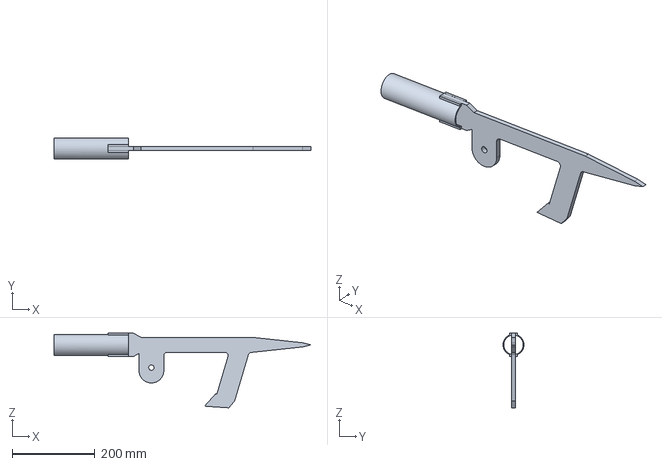
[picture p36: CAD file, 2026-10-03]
cad/step/hook-head.step
620.0 x 50.8 x 180.2 mm

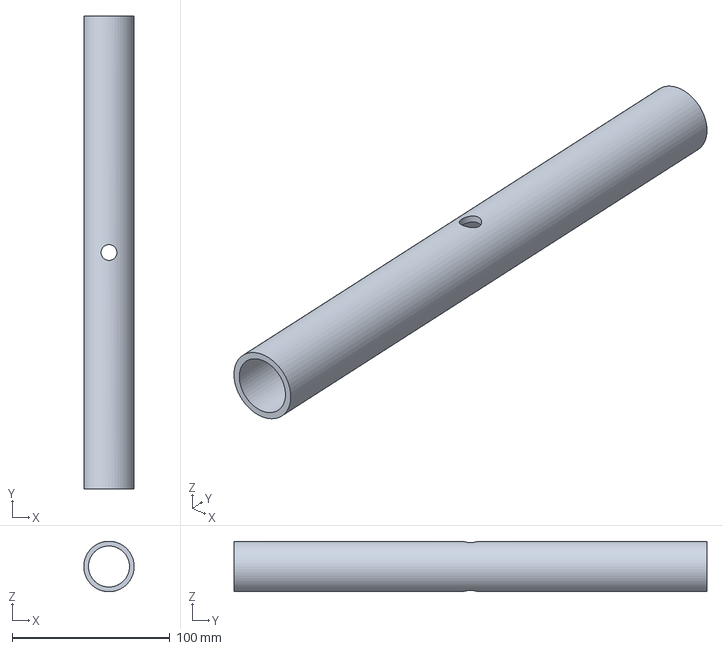
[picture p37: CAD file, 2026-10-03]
cad/step/hauling-toggle.step
32.0 x 300.0 x 32.0 mm

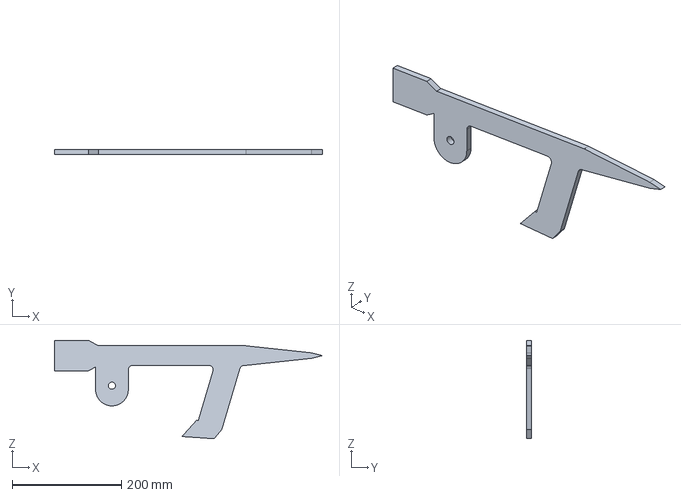
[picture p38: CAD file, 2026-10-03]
cad/step/hook-plate.step
490.0 x 10.0 x 180.0 mm

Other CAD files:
cad/stl/fork-prop-plate.stl
cad/stl/hauling-toggle.stl
cad/stl/hook-head.stl

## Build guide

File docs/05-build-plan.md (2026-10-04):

---
doc_id: BHK-BLD-001
title: BreakHook prototype build plan
project: BreakHook
doc_type: Build plan
version: "0.3"
status: Draft
date: '2026-10-03'
author: Amish Chadha
license: CERN-OHL-S-2.0
revisions:
- version: "0.1"
  date: '2026-10-03'
  author: Amish Chadha
  change: First build plan; design made constructable (BHK-DDR-002)
- version: "0.2"
  date: '2026-10-03'
  author: Amish Chadha
  change: Fork prop added (BHK-DDR-003); new section 3.8, Figures 14 to 16, Step 13; rack and stowing steps renumbered 14 and 15
- version: "0.3"
  date: '2026-10-03'
  author: Amish Chadha
  change: "Reach and drill checks worded for the prop holder's placement-only stand-off at 2.9 m (BHK-DDR-004, Amish's round-2 decision 5A)"
---

# BreakHook prototype build plan

**Plan, not yet built.** How to build the first proof-of-concept prototype, component by component. Building and testing to it is TRL 4 work. Decisions still to be made are kept in the design decisions register ([docs/06-design-decisions.md](06-design-decisions.md)), not here.

## 1. What you are building

Figure 1. Every component, pulled apart and numbered in build order

*Figure 1. One set, its fork prop and one rack upright, pulled apart and numbered in build order.*

The prototype is one BreakHook set and its wall rack: a yellow steel hook head on a 5.9 m orange fibreglass pole in three sections, a short steel wire rope leader, a 25 m blue pull rope with ten hauling toggles, a light fork prop that holds the pole at mid-length while the hook is set, and two steel rack uprights. A community kit is two sets on one rack. Seven components are made: the hook plate and the socket tube (welded together into the hook head), the pole sections, the joint sleeves, the toggles, the fork prop and the rack uprights. Everything else is bought: shackles, wire rope leader, pull rope, nylon pins, cord, tape, caps, the lock and the seals. The work is cutting and welding steel plate and tube, cutting, drilling and gluing fibreglass tube, and tying knots. The parts for a community kit cost about USD 1,170 from the bill of materials.

> **Safety:** This is a pulling tool used near fire, around people and possibly near electrical wiring. In the workshop the hazards are hot work (cutting and welding steel), fibreglass dust, and, at first load, a rope system under 6 kN. Weld only with fire precautions and eye protection; cut and drill fibreglass outdoors or with extraction, in a dust mask and gloves. Never stand in line with a loaded rope or leader. No part of this plan involves pulling down a real dwelling; first trials use a purpose-built test frame, outside this plan.

## 2. What changed to make it buildable

The concept showed what BreakHook does; several parts could not be made or joined as first drawn. Each change below keeps what the tool does and is recorded in decision record BHK-DDR-002.

*Table 1. Changes from the concept.*

| Component | The concept had | The buildable design has | Why |
| --- | --- | --- | --- |
| Hook head | A forged or fabricated hook with a spike | One profile cut from 10 mm steel plate (Figure 2) | No forging; any welder can cut it |
| Hook to pole | Hook on the end of the pole | A slotted steel socket with the plate welded into both slots (Figure 3) | A face-to-face welded joint a welder can check by eye |
| Pole in socket | Not defined | A slip fit with a rubber tape ring that releases at a firm 50 N pull (Figure 5) | The pole must come off before anyone hauls |
| Pole joints | Not defined | A fibreglass sleeve glued to the lower section and a nylon pin through the upper one (Figure 8) | Foam-filled tube cannot take an inside spigot; no metal in the insulated length |
| Rope attachment | Rope tied to the hook head | A shackle in a hole in line with the hook's arm, a 1.5 m wire rope leader, a second shackle to the rope (Figures 12 and 13) | No knot to weaken or cut; the pull runs straight through the hook |
| Hook plate size | 40 mm shank and arm in ordinary steel | 36 mm shank and 48 mm arm in S355 steel | The arm needed more strength on deep beams; the slimmer shank keeps the weight under 8 kg |
| Hauling handles | Handles or toggles | Fibreglass toggles on prusik cord loops (Figure 10) | They slide along the rope when slack and grip when pulled |
| Rack | A rack and a seal | Two welded flat-bar uprights with lipped arms and a rope peg (Figure 11) | Every piece rests on an arm without touching its neighbour |
| Holding the pole up | Two people holding the pole out by hand | A fork prop under the pole at mid-length, carried separately (Figures 14 to 16; decision record BHK-DDR-003) | The hand-held pole sagged about 0.66 m at the hook; on the prop it sags about 0.27 m and nobody has to lift it |

## 3. Making the components

Make and check each component before the assembly step that needs it. Sizes are in millimetres. "Front" is the end with the hook; the hook's arm points down. Workshop tolerance is 1 mm unless a step says otherwise; drawings carry no tolerances before TRL 4.

### 3.1 Hook plate

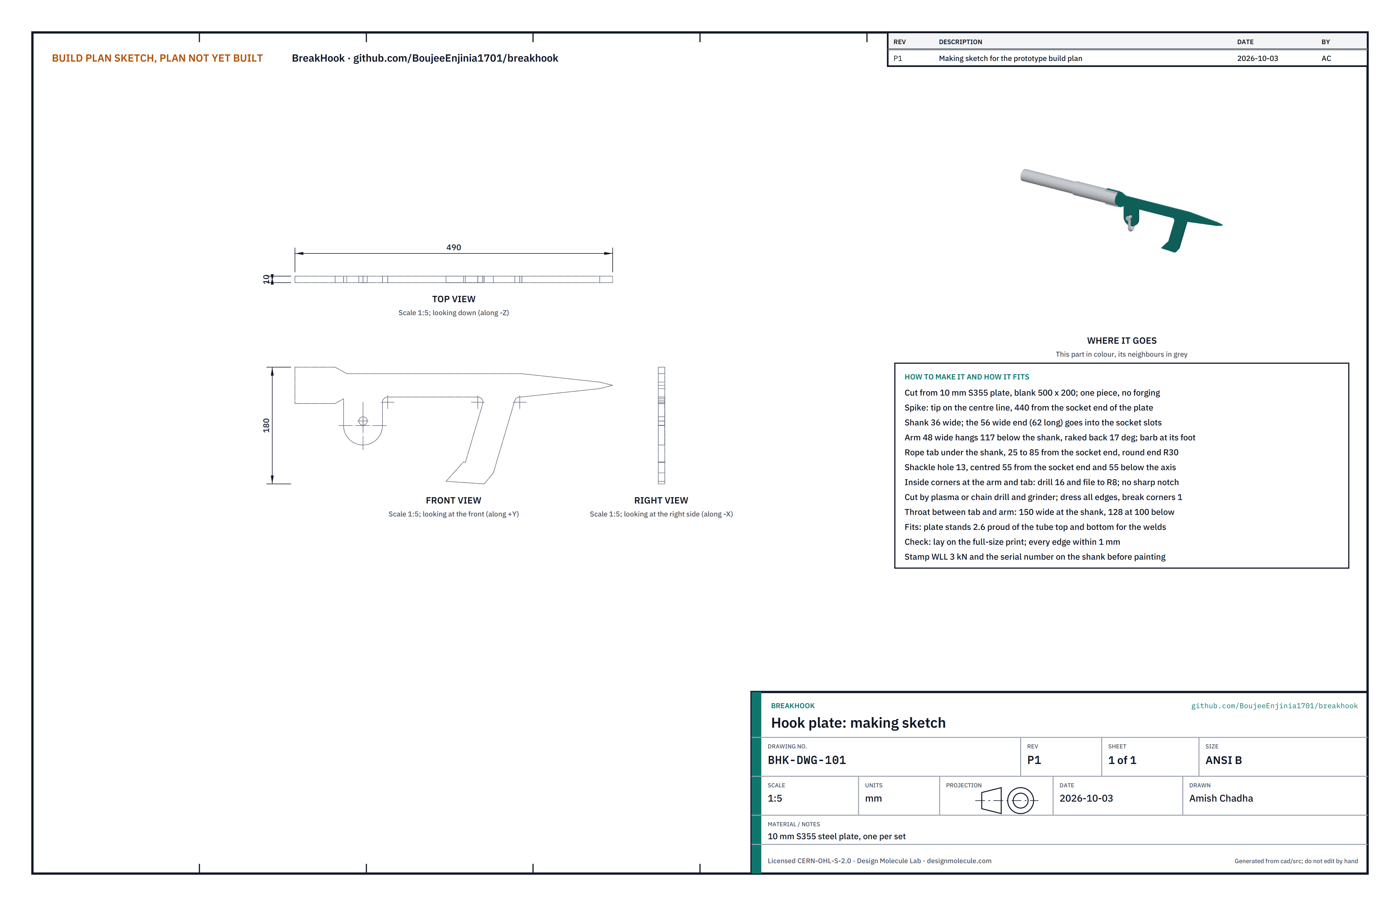
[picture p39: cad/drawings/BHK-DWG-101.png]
Figure 2. Making sketch of the hook plate


*Figure 2. Hook plate making sketch (BHK-DWG-101).*

**What it is and what it is made from.** The working part of the tool: a forward spike, a straight shank, an arm that hangs down behind a beam, a small barb at the arm's foot, and a rope tab with the shackle hole. One piece of 10 mm S355 steel plate, from a blank 500 x 200.

**How to make it.**

1. Print the profile from the making sketch at full size, glue it to the plate and centre-punch the corners and the hole centre.
2. Drill the 13 mm shackle hole, centred 55 from the socket end of the plate and 55 below the centre line of the shank.
3. Drill a 16 mm hole at each inside corner where the arm and the tab meet the shank, so the corners end up round (about 8 mm radius), never a sharp notch.
4. Cut the outline by plasma, or by chain drilling and an angle grinder with a cutting disc. The end that goes into the socket is 56 wide and 62 long; the shank is 36 wide; the arm is 48 wide and hangs 117 below the shank, sloping back toward the user by about 17°; the spike tip is on the centre line, 440 from the socket end.
5. Grind every edge clean, break the corners by about 1 mm, and dress the spike to a point with no burr.
6. Stamp "WLL 3 kN" and the serial number on the shank, near the socket end.

**How it fits the parts next to it.** The wide end slides 50 deep into the socket's two slots and stands 2.6 proud of the tube top and bottom for the welds (Figure 3). In use the shank rests on the top of a wall plate or rafter and the arm hangs behind it (Figure 4); the rope pulls through the shackle hole, which lines up with the middle of a 75 mm beam.

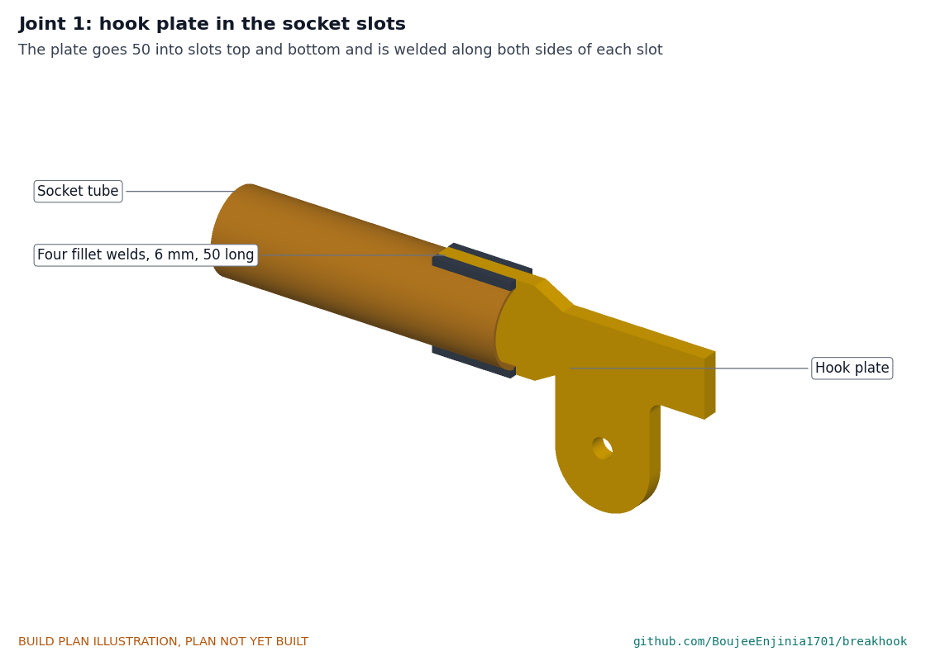
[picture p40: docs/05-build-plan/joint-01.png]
Figure 3. Joint 1: hook plate in the socket slots


*Figure 3. The plate sits in slots top and bottom and is welded along both sides of each slot.*

Figure 4. Joint 7: the hook on a wall plate

*Figure 4. In use: shank on the plate, arm behind it.*

**Check before moving on.** Lay the plate on the full-size print: every edge within 1 mm. A 75 x 50 timber offcut fits under the shank against the arm, and a 100 mm deep one fits too.

### 3.2 Socket tube

Figure 5a. Making sketch of the socket tube

*Figure 5a. Socket tube making sketch (BHK-DWG-102).*

**What it is and what it is made from.** The short steel tube the pole slides into. Welded steel tube 50.8 x 2.0, cut to 180.

**How to make it.**

1. Cut 180 from the tube and square both ends.
2. Wrap a strip of paper round one end to mark two slots exactly opposite each other, 10.5 wide and 50 deep.
3. Cut the slots with a hacksaw or a thin cutting disc and file them to width, square at the bottom.
4. Deburr the bore at the open end and break its edge.

**How it fits the parts next to it.** The bore is 46.8; the 44.5 pole slides in with about 1.15 clearance all round and goes in 130 until it stops on the end of the plate. A ring of rubber tape on the pole tip makes it a firm push fit (Figure 5).

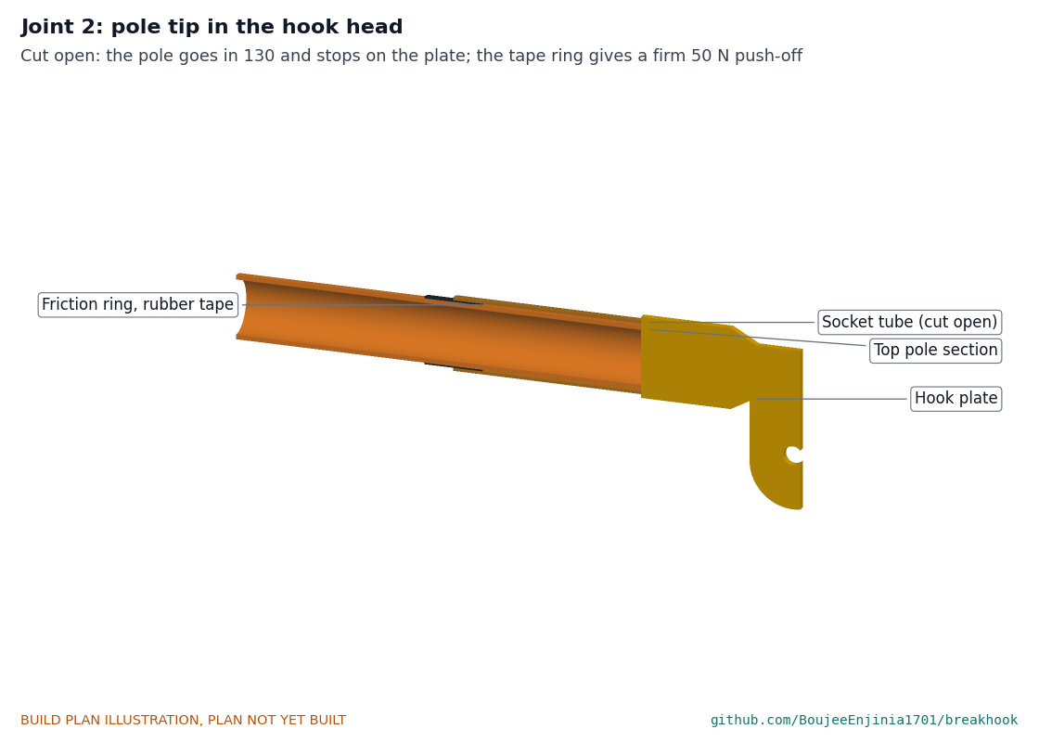
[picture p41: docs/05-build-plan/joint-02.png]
Figure 5. Joint 2: pole tip in the hook head


*Figure 5. Cut open: the pole stops on the plate; the tape ring holds it.*

**Check before moving on.** A 300 offcut of pole tube slides in and out by hand; the plate goes into both slots with no more than 0.5 total play.

**Welding the hook head (Step 2).** Tack the plate in the slots, check it is square to the tube and centred, then run a 6 mm fillet weld along both sides of each slot, outside the tube. Clean, prime with zinc-rich primer and paint high-visibility yellow.

### 3.3 Pole sections (make 3)

Figure 6. Making sketch of a pole section

*Figure 6. Pole section making sketch (BHK-DWG-103).*

**What it is and what it is made from.** Three 1.8 m lengths of foam-filled, electrical-grade fibreglass tube 44.5 x 3.2 that carries the maker's dielectric test certificate. The butt section is the bottom one, the top section carries the hook head.

**How to make it.**

1. Cut three lengths of 1800 with a fine-tooth saw, the tube wrapped in tape where you cut. Work outdoors in a dust mask and gloves.
2. Middle and top sections: drill one 10.5 hole straight across the tube, through both walls, 74 from the bottom end.
3. Seal every cut end and the bore of every pin hole with a thin coat of epoxy, so water cannot get into the foam.

**How it fits the parts next to it.** The butt and middle sections each get a sleeve glued on their top ends (section 3.4); the section above slides into that sleeve and is pinned. The butt section also gets a rubber cap and a red hand band 1550 to 1600 from its bottom end. The top section gets the friction ring 110 to 150 below its tip.

**Check before moving on.** Each section is 1800 within 2; the pin holes are square to the tube by eye.

### 3.4 Joint sleeves (make 2)

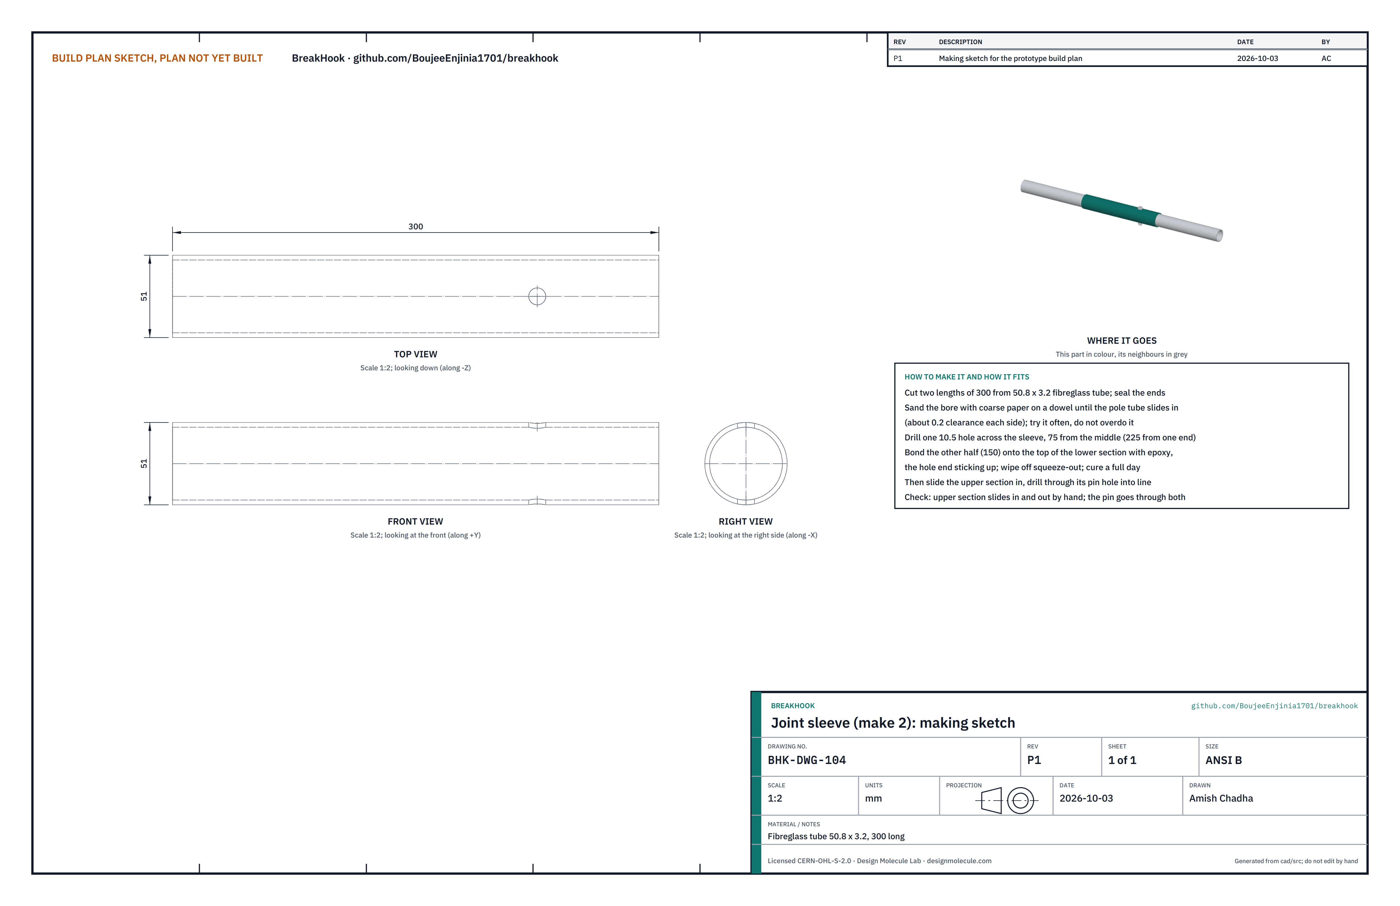
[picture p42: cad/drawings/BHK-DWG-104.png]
Figure 7. Making sketch of a joint sleeve


*Figure 7. Joint sleeve making sketch (BHK-DWG-104).*

**What it is and what it is made from.** A 300 length of fibreglass tube 50.8 x 3.2 that joins two pole sections.

**How to make it.**

1. Cut two lengths of 300 and seal the ends with epoxy.
2. Sand the bore with coarse paper on a dowel, trying a pole offcut often, until the pole slides in with about 0.2 clearance all round.
3. Drill one 10.5 hole straight across, 75 from the middle of the sleeve.
4. Glue the half without the hole (150) onto the top of the butt section, and the other sleeve onto the top of the middle section, with structural epoxy. Wipe off the squeeze-out and let it cure a full day.

**How it fits the parts next to it.** The two sections meet in the middle of the sleeve with a 2 gap. The upper section slides into the free half and a nylon pin goes through the sleeve and the section (Figure 8).

Figure 8. Joint 3: pole joint

*Figure 8. Cut open: glued below the joint line, pinned above it.*

**Check before moving on.** The upper section slides in and out by hand and the pin goes through both holes without forcing.

### 3.5 Hauling toggles (make 10 per set)

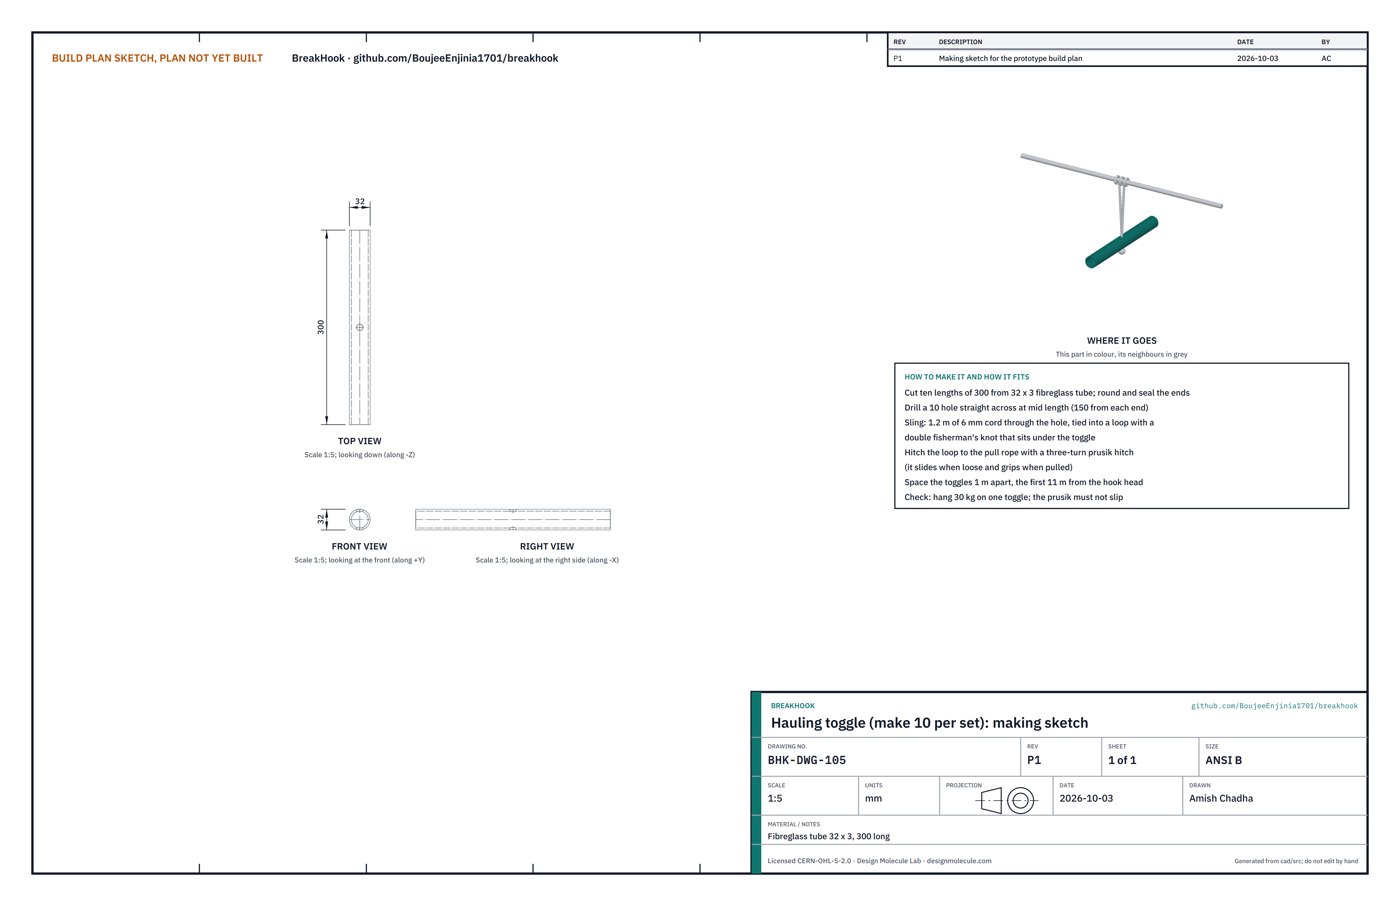
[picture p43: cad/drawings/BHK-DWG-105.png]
Figure 9. Making sketch of a hauling toggle


*Figure 9. Hauling toggle making sketch (BHK-DWG-105).*

**What it is and what it is made from.** A 300 length of fibreglass tube 32 x 3 that a hauler holds, hung from the pull rope on a loop of 6 mm cord.

**How to make it.**

1. Cut ten lengths of 300; round and seal the ends.
2. Drill a 10 hole straight across at mid length.
3. Pass 1.2 m of 6 mm cord through the hole and tie it into a loop with a double fisherman's knot that sits under the toggle.

**How it fits the parts next to it.** The loop goes onto the pull rope with a three-turn prusik hitch, which slides when slack and grips under load (Figure 10). Toggles go 1 m apart from 11 m along the line.

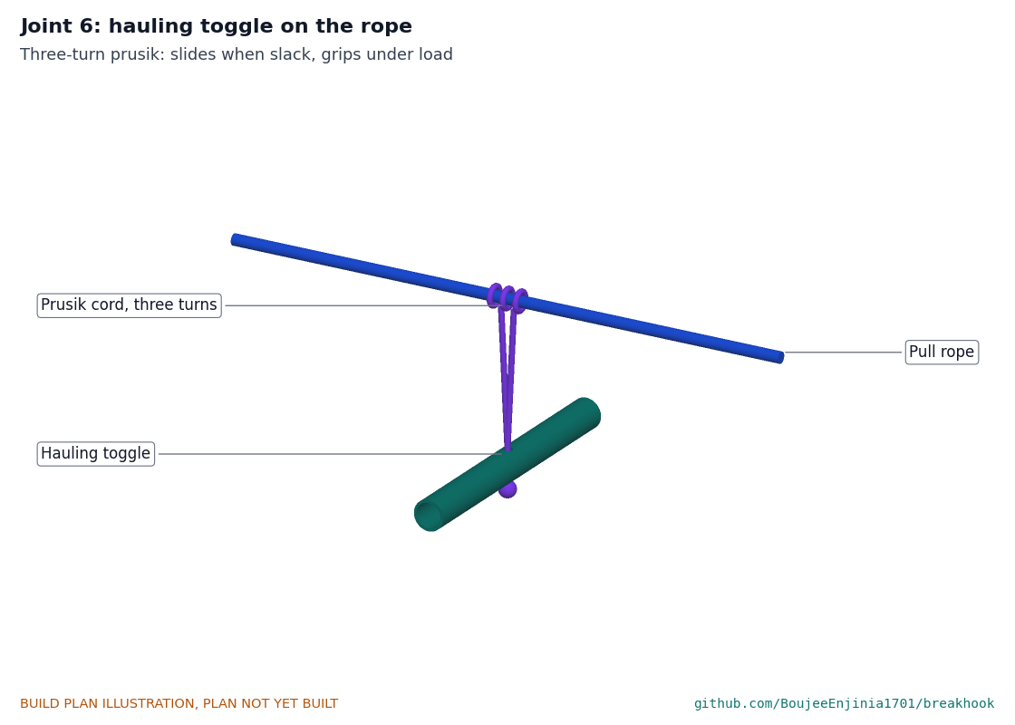
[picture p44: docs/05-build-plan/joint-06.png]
Figure 10. Joint 6: hauling toggle on the rope


*Figure 10. Three-turn prusik on the 12 mm rope.*

**Check before moving on.** Hang 30 kg from one toggle on a length of the rope: the prusik does not slip.

### 3.6 Rack uprights (make 2)

Figure 11a. Making sketch of a rack upright

*Figure 11a. Rack upright making sketch (BHK-DWG-106).*

**What it is and what it is made from.** A wall bracket of 40 x 6 steel flat bar: an 800 upright, two 250 arms with 30 lips, and a 380 rope peg with a 40 lip.

**How to make it.**

1. Cut the upright, two arms, a peg and three lips from 40 x 6 flat bar.
2. Drill two 11 holes in the upright, 50 and 750 up, for M10 anchors.
3. Weld the lips on the ends of the arms and the peg, standing up.
4. Weld the arms square to the front face of the upright with their tops 256 and 506 up, and the peg at 700 up. Weld all round each root.
5. Grind smooth, prime and paint.

**How it fits the parts next to it.** The two uprights go 1200 apart on a wall. Each arm holds four poles 56 apart, with the sleeves at alternate ends so they do not touch. The rope coil hangs on the peg clear of the arms below (Figure 11).

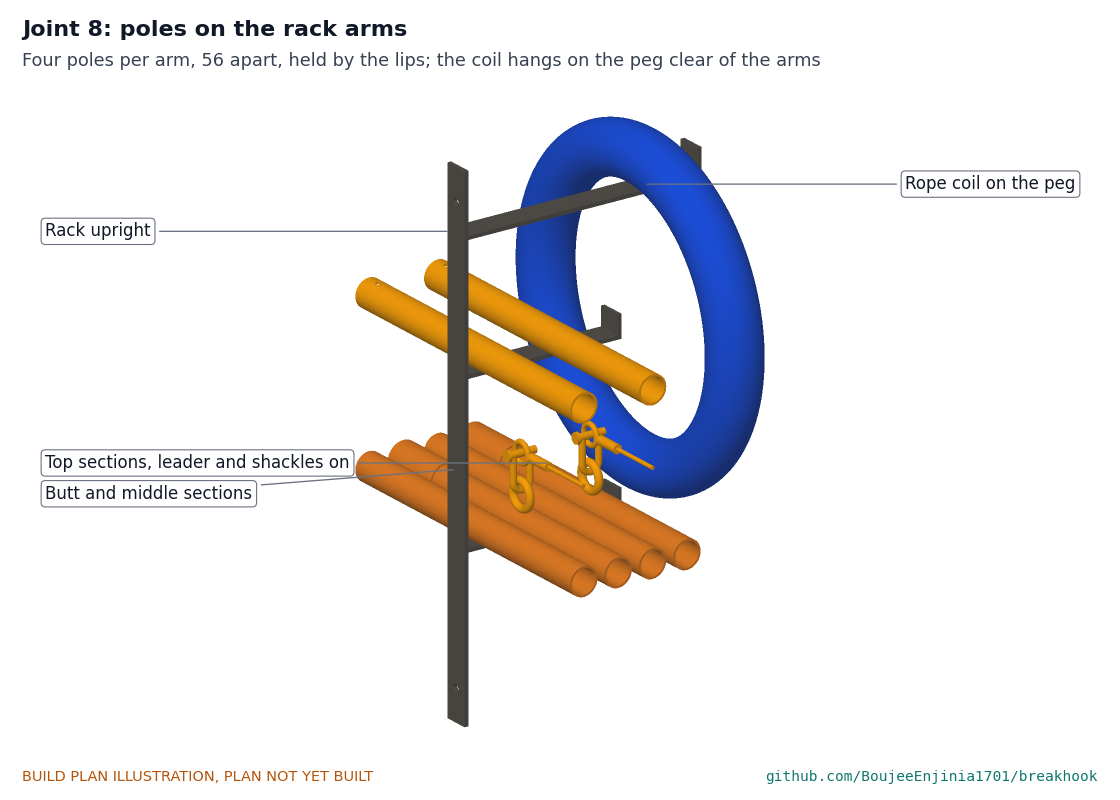
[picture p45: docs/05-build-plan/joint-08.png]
Figure 11. Joint 8: poles on the rack arms


*Figure 11. Lower arms hold the butt and middle sections, upper arms the top sections with their hook heads.*

**Check before moving on.** Arms level and square to the wall; a 10 kg load leaves no movement.

### 3.7 Bought components

- **Shackles (four per kit):** 3/8 in (10 mm) screw-pin bow shackles, galvanised, rated 1 t and marked. Check the jaw takes the 10 mm plate and the pin passes the 13 mm hole. Mouse each pin with soft wire after fitting.
- **Wire rope leaders (two):** 6 mm 6x19 galvanised wire rope, 1.5 m between thimble eyes with pressed ferrules, proof tested and tagged by the rigging shop (Figures 12 and 13).
- **Pull ropes (two):** 12 mm polyester double braid, breaking strength 25 kN or more, 25 m with a spliced eye; whip the tail.
- **Nylon pins (four):** 10 mm nylon 66 clevis pins with nylon hitch clips; tie each to its section with a cord lanyard.
- **Friction ring tape, red tape and clear sleeve, butt caps, structural epoxy, cord, paint:** as the bill of materials.
- **Nylon M8 bolts, prop setting pins and prop foot caps:** for the fork prop (section 3.8).
- **Lock cable and padlock, numbered seals, fall zone tape and stakes, check cards, rigger gloves:** used in Step 15 and in training.

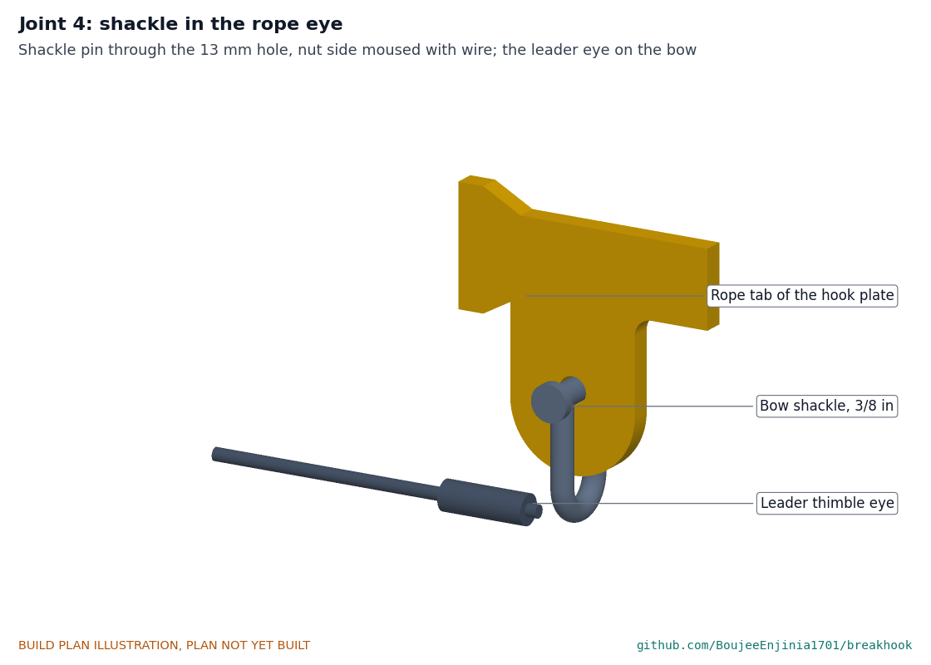
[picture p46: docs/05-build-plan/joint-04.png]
Figure 12. Joint 4: shackle in the rope eye


*Figure 12. Shackle pin through the 13 mm hole; leader eye on the bow.*

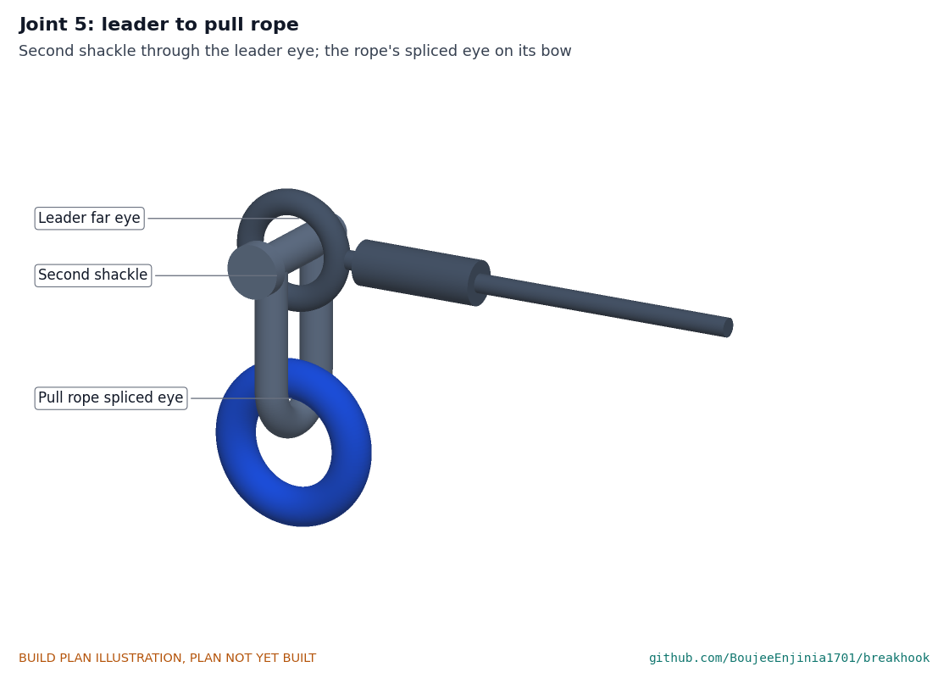
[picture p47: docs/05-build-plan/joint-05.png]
Figure 13. Joint 5: leader to pull rope


*Figure 13. Second shackle through the far leader eye; the rope's spliced eye on its bow.*

### 3.8 Fork prop (make 1 per set)

Figure 14. Making sketch of the fork prop

*Figure 14. Fork prop making sketch (BHK-DWG-107).*

**What it is and what it is made from.** A light, adjustable prop with a fork at its top. While the hook is set, the pole lies in the fork at its mid-length, so nobody has to hold the pole out at arm's length. It is carried separately from the pole. It has a lower tube of fibreglass 32 x 3 (the same stock as the toggles), an upper tube of fibreglass 25.4 x 3.2 that slides inside it, a fork plate cut from 12 mm HDPE plastic, two nylon M8 bolts, a nylon setting pin and a rubber foot cap. There is no metal in it.

**How to make it.**

1. Cut the lower tube 1000 long and the upper tube 1100 long. Seal the cut ends with epoxy.
2. Lower tube: drill one 10.5 hole straight across, 50 below its top.
3. Upper tube: mark a straight line along it and drill sixteen 10.5 holes on that line, 50 apart, the first 150 from its bottom end, all square to the tube. Seal the hole bores with epoxy.
4. Upper tube: cut a slot straight across its top, 12.5 wide and 60 deep, as for the socket slots (section 3.2), at right angles to the line of holes.
5. Fork plate: print the profile from the making sketch at full size and cut it from 12 mm HDPE with a jigsaw or coping saw. It is 100 wide; the notch at the top is 50 wide with a round bottom of 25 radius, 30 above the top of the tube; the tongue at the bottom is 25.4 wide and 60 long. Round every edge with a file or scraper.
6. Push the tongue into the slot until the plate sits on the tube, drill two 8.5 holes through tube and tongue, 15 and 45 below the top of the tube, and fit the nylon bolts and nuts hand tight.
7. Push the rubber cap on the bottom of the lower tube. Wrap red tape from 850 to 900 up from the foot and shrink a clear sleeve over it, as on the pole.
8. Slide the upper tube into the lower tube and fit the setting pin through the lower tube's hole and one of the upper tube's holes. Tie the pin to the lower tube with its lanyard.

**How it fits the parts next to it.** The upper tube slides in the lower tube with about 0.3 clearance all round; the pin sets the height of the fork in 50 steps, from 1.19 m to 1.94 m above the ground (Figure 15). The pole lies loose in the notch with about 2.75 clearance at each side; the fork lifts the pole and never clamps it (Figure 16). In use the prop stands under the middle pole section, about 2.95 m from the butt, leaning about 13° with its top toward the wall. Its holder holds it below the red band.

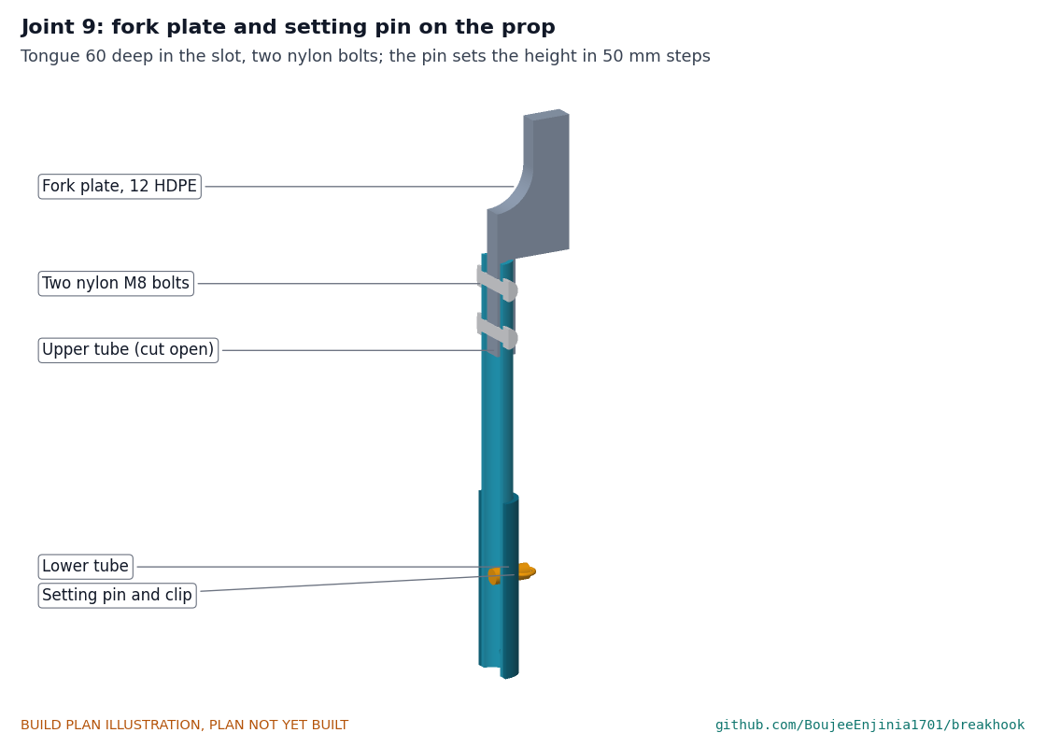
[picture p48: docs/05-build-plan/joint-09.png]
Figure 15. Joint 9: fork plate and setting pin on the prop


*Figure 15. Cut open: the fork's tongue in the slot with two nylon bolts; the setting pin through both tubes.*

Figure 16. Joint 10: the pole resting in the fork

*Figure 16. In use: the middle pole section lies in the notch.*

**Check before moving on.** The upper tube slides in and out by hand at every hole and the pin goes through each of them. The fork plate does not rock in the slot. Closed to its shortest, the prop is about 1.24 m long. Mark the hole for the community's usual wall height with tape.

## 4. Putting it together

In each picture the parts already fitted are grey and the part being fitted is in colour, with an arrow showing the way it goes in. Long parts are drawn cut short around the joint.

### Step 1: hook plate into the socket slots

Step 1

Slide the plate's wide end into both slots until it bottoms, 50 deep, with the arm pointing down.

### Step 2: weld, clean and paint the hook head

Step 2

Tack, check square, then weld both sides of each slot (section 3.2). **Hold point:** safety stop S1.

### Step 3: bond a sleeve onto the butt section

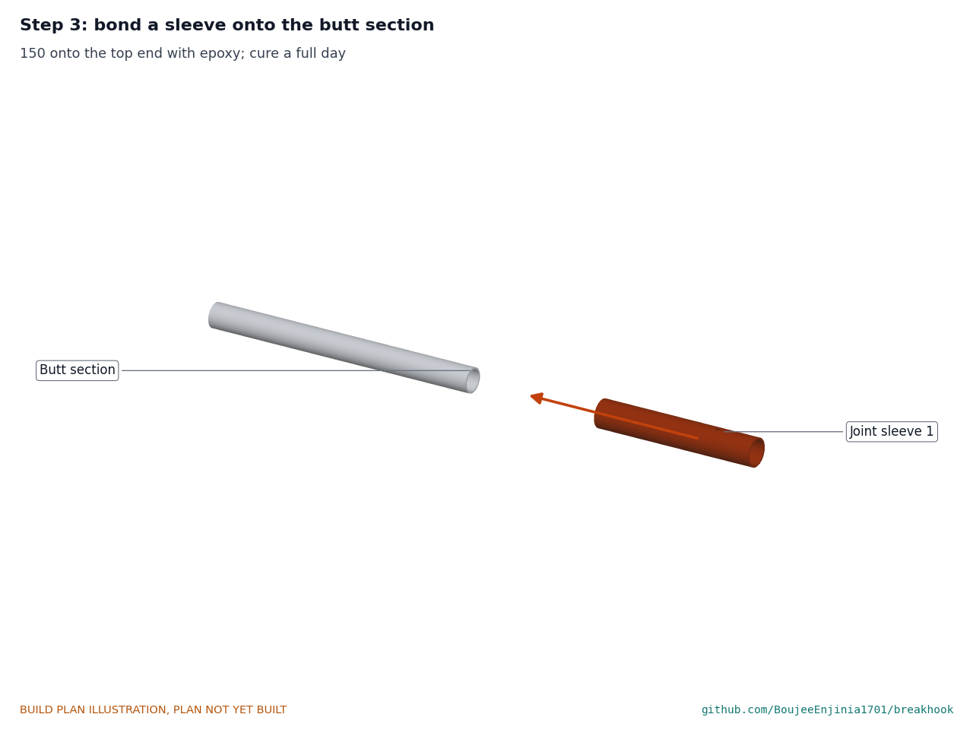
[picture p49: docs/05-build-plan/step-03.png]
Step 3


150 onto the top end with epoxy, the drilled half sticking up. Cure a full day.

### Step 4: bond a sleeve onto the middle section

Step 4

As Step 3, on the middle section's top end.

### Step 5: butt cap and hand band

Step 5

Push the cap onto the butt end. Wrap red tape from 1550 to 1600 up from the butt end and shrink a clear sleeve over it.

### Step 6: friction ring on the top section

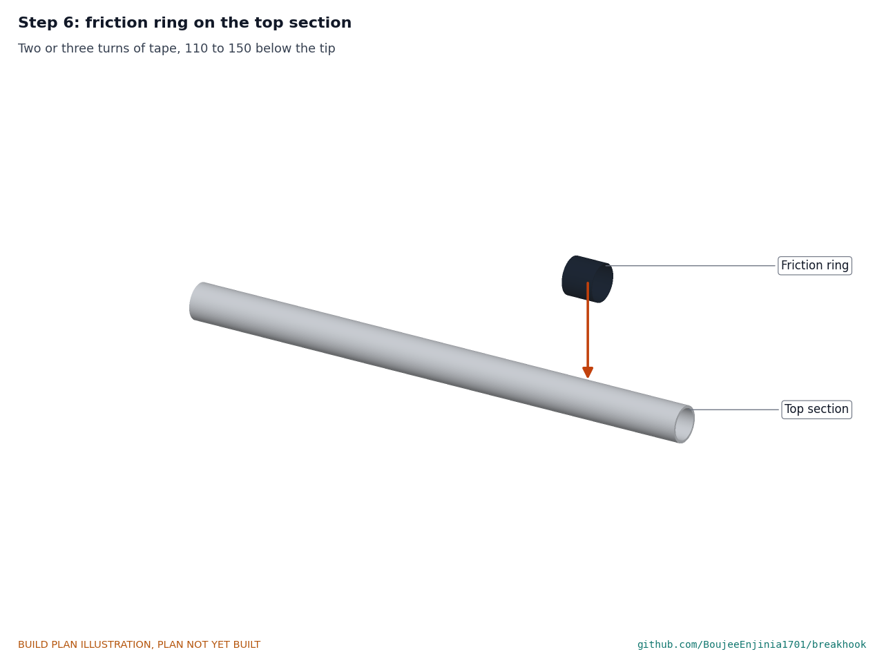
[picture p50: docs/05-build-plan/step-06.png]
Step 6


Two or three turns of rubber tape, 110 to 150 below the tip, stretched as you wrap.

### Step 7: join the butt and middle sections

Step 7

Push the middle section fully into the sleeve, line up the holes, fit the nylon pin from the top and clip it.

### Step 8: join the middle and top sections

Step 8

As Step 7.

### Step 9: hook head onto the pole

Step 9

Push the hook head over the friction ring until the pole stops on the plate. Pull it off and on again: it should need a firm pull of about 50 N (a 5 kg spring balance). Add or remove a turn of tape until it does.

### Step 10: shackle and leader onto the hook

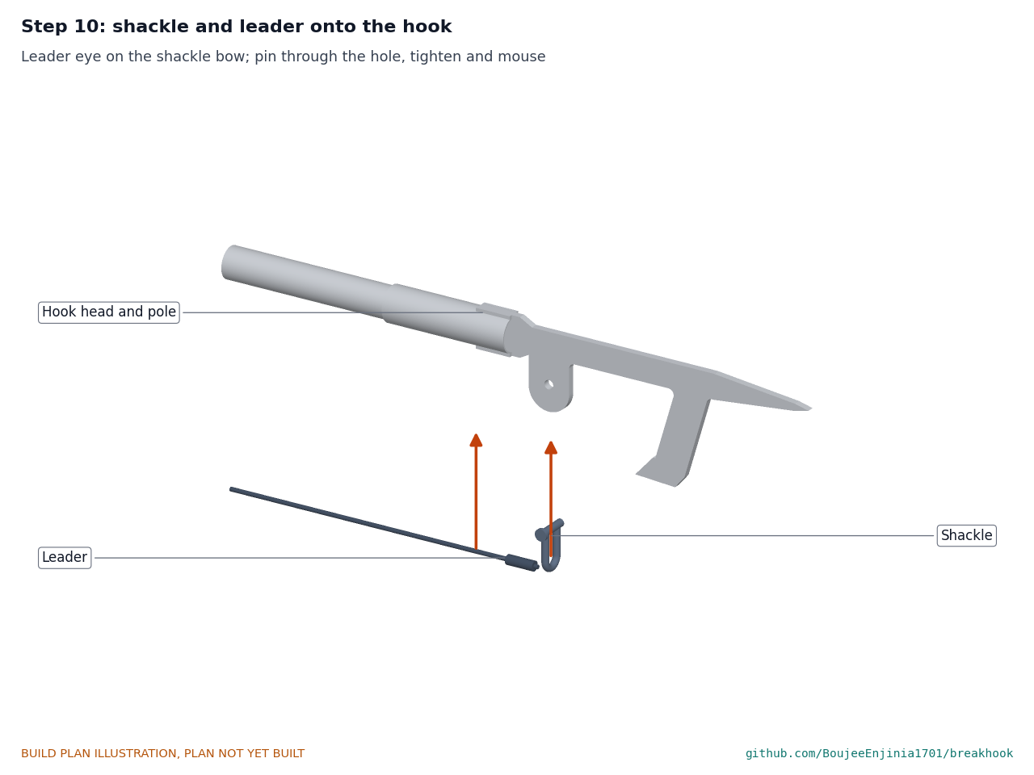
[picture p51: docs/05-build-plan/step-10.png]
Step 10


Put the leader's eye on the shackle bow, the pin through the 13 mm hole, tighten by hand and mouse it with wire.

### Step 11: pull rope onto the leader

Step 11

Second shackle through the far eye of the leader, the rope's spliced eye on its bow; mouse the pin. **Hold point:** safety stop S2.

### Step 12: toggles onto the rope

Step 12

Ten toggles, 1 m apart, the first 11 m from the hook head.

### Step 13: assemble the fork prop

Step 13

Fork plate bolted into the top of the upper tube; upper tube into the lower tube; setting pin through the marked hole, clip on (section 3.8).

### Step 14: rack uprights onto the wall

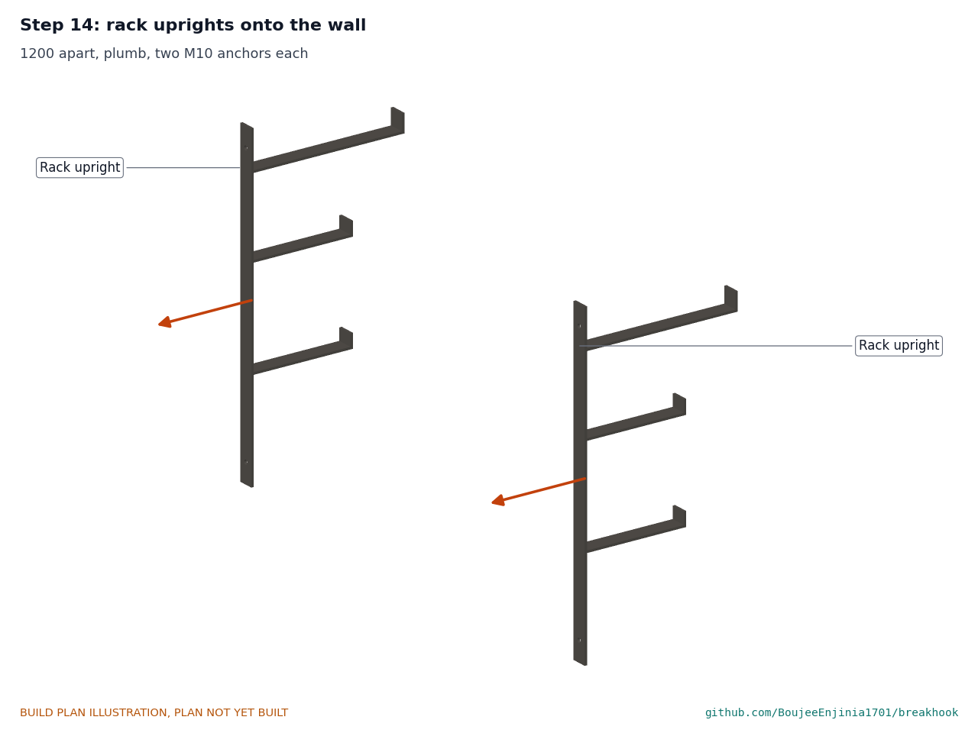
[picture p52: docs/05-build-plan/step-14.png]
Step 14


1200 apart, plumb, with two M10 anchors each into masonry or coach screws into a timber post.

### Step 15: stow the kit, lock and seal

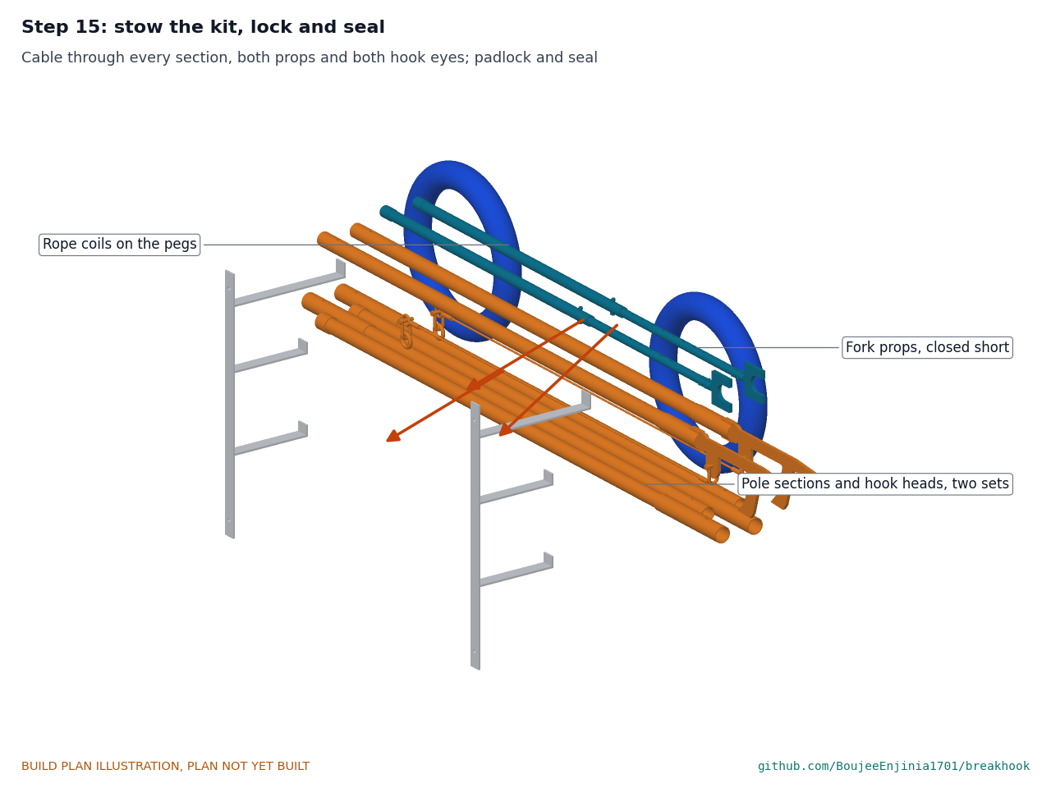
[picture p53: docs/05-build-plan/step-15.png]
Step 15


Butt and middle sections on the lower arms, sleeves at alternate ends; top sections with their hook heads, shackles and leaders on the upper arms; the two fork props closed short on the upper arms between the top sections, forks beyond the arm; ropes coiled on the pegs with the toggles. Run the lock cable through every section, both props and both hook eyes, padlock it and fit a numbered seal. **Hold point:** safety stop S4.

## 5. First checks

These are the checks a TRL 4 test report would record; this plan only lists them. Requirement numbers are those of BHK-REQ-001.

*Table 3. First checks.*

| Check | Requirement | How | Pass when |
| --- | --- | --- | --- |
| Proof load | R2 | Hook head, shackles and leader loaded to 6 kN for 1 minute through a 75 x 100 timber in the hook, on CalRig or at a rigging shop | No crack, no visible bend, no weld mark; hook throat opening changes by less than 1 mm |
| Mass | R5 | Weigh the pole with the hook head | 8 kg or less (7.82 kg estimated) |
| Longest piece | R8 | Measure each section with its sleeve | 2.0 m or less |
| Release | R12 | Spring balance on the pole while the hook head is held | Releases at about 50 N |
| Insulated length and certificate | R4, R14 | Measure from the socket mouth to the top of the band; read the tube certificate | 3.0 m or more; certificate to ASTM F711 present |
| Beam fit | R11 | Hang the hook on 75 x 50 and 100 x 120 timber offcuts | Shank rests on top, arm behind, no forcing |
| Reach | R1 | Pole team sets the hook on a 3 m high timber rail, the pole on the fork prop at mid-length and the rear hand at the butt | Hook set in three tries or fewer; droop measured (about 0.27 m expected); distance of each person from the rail measured: pole hands 4 m, prop holder about 2.9 m for about 25 s; confirms the stand-off accepted in BHK-DDR-004 |
| Prop | R1, R8 | Set the prop at each marked hole under the pole; close it | Pin goes through at every hole; the prop stands steady at its lean; closed length 1.3 m or less |
| Toggle grip | R13 | 30 kg hung on a toggle on the rope | No slip |
| Deployment drill | R6 | Four people, kit 100 m from the rail, stopwatch | Hook set and pole withdrawn in 3 min or less; the prop holder withdraws with the pole, so nobody stands nearer than the 4 m pole-hand distance at the haul |

## 6. Safety stops

Stop at each point. Carry on only when everything listed is true.

- **S1. Before any weld is loaded.** The welds have been looked at by the welder and a second person: full length, no cracks, no undercut at the slot ends. The plate is square to the tube.
- **S2. Before the first proof load.** The rig and the load path are rated above 6 kN; the shackle pins are moused; nobody stands in line with the rope, leader or hook, or within 3 m of the load path; a heavy blanket or mat is laid over the leader to catch it if it parts.
- **S3. After the proof load.** Any bend, crack or shifted ferrule takes that part out of service for good; nothing is straightened and reused.
- **S4. Before the kit is issued to a community.** Proof load passed and tagged for both sets; tube certificate on file; check cards, gloves and fall zone tape in the kit; the community's fire plan, agreed with the fire service, names the keyholders and the caller; training has been given.
- **S5. Before any trial pull (outside this plan).** Only on a purpose-built test frame, never an occupied or lived-in structure; the frame checked empty; no overhead lines within 3 m; fall zone taped; pole and fork prop withdrawn and the pole team out of the zone; haulers at least 10 m back, in gloves, on the caller's word.

## 7. Tools, skills and workspace

**Tools.** Angle grinder with cutting and flap discs, or access to a plasma cutter; bench drill with drills to 16 mm; centre punch and letter stamps; MIG or stick welder; hacksaw; fine-tooth saw for fibreglass; jigsaw or coping saw for the HDPE fork plate; files; coarse abrasive paper and a dowel; tape measure, steel rule, square and calipers; 5 kg spring balance; bathroom or hanging scale; paint brushes; heat gun for the clear sleeve.

**Skills.** A competent welder for the hook head and rack; basic workshop skills for the rest; knot tying (double fisherman's knot, prusik hitch), which a rigging shop or climbing club can teach. The proof load is done by a rigging shop or on CalRig with someone trained to use it.

**Workspace.** A metalworking bench with a fire-safe area for welding; an outdoor or ventilated space for cutting and drilling fibreglass; 6 m of clear floor to lay out and join the pole.

**Personal protective equipment.** Welding helmet, gloves and jacket for hot work; safety glasses for cutting, grinding and drilling; dust mask (FFP2 or N95) and gloves for fibreglass; hearing protection for grinding; rigger gloves for handling rope under load.

## 8. Where the numbers come from

- Model and constructability checks: `cad/src/model.py` (`python cad/src/model.py --check`); STEP and STL exports in `cad/step/` and `cad/stl/`.
- Pictures: `cad/src/build_plan_media.py`, using `.kit/build_views.py`; written to `docs/05-build-plan/` and `cad/drawings/BHK-DWG-101` to `BHK-DWG-107`.
- General arrangement: `cad/drawings/BHK-DWG-001.pdf`, Rev P2.
- Calculations: `docs/04-calcs/01-sizing.md` (BHK-CAL-001 v0.2) and `docs/04-calcs/sizing.py`.
- Bill of materials: `bom/bom.csv`.
- Decisions: `docs/decisions/0001-trl2-review-decisions.md` (BHK-DDR-001) `docs/decisions/0002-design-for-construction.md` (BHK-DDR-002) and `docs/decisions/0003-fork-prop.md` (BHK-DDR-003).
- Requirements: `docs/03-requirements.md` (BHK-REQ-001 v0.3).

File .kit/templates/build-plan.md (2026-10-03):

---
doc_id: PRJ-BLD-001
title: Project prototype build plan
project: Project name
doc_type: Build plan
version: "0.1"
status: Draft
date: YYYY-MM-DD
author: Amish Chadha
license: CERN-OHL-S-2.0
revisions:
  - version: "0.1"
    date: YYYY-MM-DD
    author: Amish Chadha
    change: First build plan; design made constructable
---

# Project prototype build plan

**Plan, not yet built.** How to build the first proof-of-concept prototype, component by component. Building and testing to it is TRL 4 work. Decisions still to be made are kept in the design decisions register (`docs/06-design-decisions.md`), not here.

## 1. What you are building

Every component, pulled apart and numbered in build order

One short paragraph: what the prototype is, how many components, which are made and which are bought, and the main ways they are made.

## 2. What changed to make it buildable

| Component | The concept had | The buildable design has | Why |
| --- | --- | --- | --- |

## 3. Making the components

### 3.1 Component name

Making sketch

**What it is and what it is made from.**

**How to make it.**

1. Mark out ...
2. Cut ...

**How it fits the parts next to it.**

Close-up of the joint

**Check before moving on.**

## 4. Putting it together

### Step 1: ...

Step 1

## 5. First checks

| Check | Requirement | How | Pass when |
| --- | --- | --- | --- |

## 6. Safety stops

## 7. Tools, skills and workspace

## 8. Where the numbers come from

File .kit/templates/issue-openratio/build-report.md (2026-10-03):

---
name: Build report
about: Tell us what happened when you built, printed or tested part of this design
title: "Build report: "
labels: build-report
---

This is a research and educational prototype, not a medical device. It is a TRL 3 concept and is not released for fabrication. If you build any part of it, you do so at your own risk. Reports help everyone.

**What you built** (part, sub-assembly or test)

**Materials, tools and settings**

**What worked**

**What did not work, with photos or measurements if you have them**

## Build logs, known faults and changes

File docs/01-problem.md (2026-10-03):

---
doc_id: BHK-PRB-001
title: BreakHook problem statement
project: BreakHook
doc_type: Problem statement
version: "0.2"
status: Draft
date: '2026-10-03'
author: Amish Chadha
license: CERN-OHL-S-2.0
revisions:
- version: "0.1"
  date: '2026-09-30'
  author: Amish Chadha
  change: Initial scaffold
- version: "0.2"
  date: '2026-10-03'
  author: Amish Chadha
  change: TRL 2 and TRL 3; co-design candidate named; open questions settled under Amish's 2026-10-03 pre-approval (BHK-DDR-001); safety section added
---

# BreakHook problem statement

In the first minutes of a settlement fire, only residents are there. They know that clearing a gap can stop the spread, but they have no tool that lets them do it from a safe distance.

## The problem

Fire can spread between informal dwellings in under a minute ([Stellenbosch University, 2023](https://www0.sun.ac.za/researchforimpact/2023/10/10/su-fire-engineers-explore-risks-for-humans-and-dwellings/)). Fire engines often cannot get in: response times average 68 minutes in informal settlements in the Dhaka and Cape Town study, and pathways can be 60 to 90 cm wide ([Royal Academy of Engineering](https://engineeringx.raeng.org.uk/media/03cd1j4l/engx-a-comparative-study-of-fire-risk-emergence-in-informal-settlements-in-dhaka-and-cape-town-short.pdf)). By then a fire can take hundreds or thousands of homes, as at Imizamo Yethu ([Imizamo Yethu fire spread analysis](https://www.sciencedirect.com/science/article/abs/pii/S2212420918307623)).

Current responses focus on prevention and access: fire safety education, extinguishers and re-blocking into rows with 3 m gaps, which reduces settlement capacity by at least 20 % ([The New Humanitarian, 2013](https://www.thenewhumanitarian.org/analysis/2013/01/23/south-africa-searches-solutions-shack-fires)). Community responders, trained by groups such as the Kenya Red Cross, use buckets and basins and pull structures down by hand ([Ngau and Boit, 2020](https://journals.sagepub.com/doi/10.1177/0956247820924939)). The historical fire hook was built for exactly this job ([London Fire Brigade Museum](https://www.london-fire.gov.uk/museum/london-fire-brigade-history-and-stories/fires-and-incidents-that-changed-history/the-great-fire-of-london/)), but no open, tested version exists for these communities.

## Users and context

| User | Need | Context |
| --- | --- | --- |
| Community fire responders | Pull a structure down from a safe distance to open a firebreak | First minutes of a fire, crowds, smoke, narrow paths |
| Settlement committees and ward leaders | A tool they can store, assign and govern, with a clear rule on when it may be used | Community fire plans and training days |
| Municipal fire services and reservist programmes | Equipment to issue to trained community reservists | City fire and disaster management |
| NGOs and Red Cross societies | A low-cost kit item with training material | Community fire response training |

## Operating environment

- Dense settlements of closely spaced, mostly single-storey dwellings (assumed; to be confirmed with the partner).
- Paths about 0.6 to 0.9 m (2 to 3 ft) wide in places ([Royal Academy of Engineering](https://engineeringx.raeng.org.uk/media/03cd1j4l/engx-a-comparative-study-of-fire-risk-emergence-in-informal-settlements-in-dhaka-and-cape-town-short.pdf)).
- Smoke, radiant heat, crowds and panic during use.
- Overhead and informal electrical wiring may be present.
- Stored outdoors or in a shared shed for long periods between uses.

## Constraints

- Prototype parts budget: USD 2,000 or less for a community kit.
- Pole must be non-conductive along the handled length.
- Light enough to carry and for a team of two to lift into place: 8 kg (18 lb) or less for the pole and hook head.
- Short enough in sections to move along narrow paths.
- Buildable by a local welder from stock steel plus commercial fibreglass tube and rope.
- Open design: hardware under CERN-OHL-S-2.0, training material under a matching open licence.

## Out of scope

- Fire suppression equipment, alarms and detectors.
- Demolition outside an active fire emergency.
- Multi-storey or masonry buildings.
- Rules on who may authorise pulling down a home; that is for each community and its local authority.

## Prior work

| Prior work | What it does | Gap for these users | Source |
| --- | --- | --- | --- |
| Historical fire hooks | Long hooks used to pull down buildings in the path of a fire, as in London in 1666 | No modern, documented, non-conductive version sized for informal dwellings | [link](https://www.london-fire.gov.uk/museum/london-fire-brigade-history-and-stories/fires-and-incidents-that-changed-history/the-great-fire-of-london/) |
| Community fire response in Nairobi | Residents trained by the Kenya Red Cross use buckets and tear down structures to make firebreaks | Done by hand, close to the fire, with no purpose-made tool | [link](https://journals.sagepub.com/doi/10.1177/0956247820924939) |
| Re-blocking (Cape Town) | Rebuilding settlements in rows with 3 m gaps for access and fire separation | Slow, costly, reduces capacity; no help once a fire has started | [link](https://www.thenewhumanitarian.org/analysis/2013/01/23/south-africa-searches-solutions-shack-fires) |

## Co-design

A municipal fire service reservist programme or a Red Cross or Red Crescent society already training community fire responders in informal settlements, working with a settlement committee that can set rules for when the tool is used.

First candidate to approach (not agreed): the City of Cape Town Fire and Rescue Service and its volunteer reservists, with a settlement committee in the Western Cape. Second candidate: the Kenya Red Cross Society's community fire response work in Nairobi (BHK-DDR-001).

## Questions from TRL 1 and where they were settled

All five were decided on 2026-10-03 under Amish's pre-approval and are recorded in the design decisions register (BHK-DEC-001) and decision record BHK-DDR-001.

| Question | Decision |
| --- | --- |
| What stops misuse, for example in disputes or evictions? | The kit is held by the settlement committee in a sealed, locked rack with two named keyholders; every use is logged against the seal number; a pull happens only during a fire, inside a fire plan agreed with the fire service, on a caller's word |
| How far ahead of the fire must the break be? | Training rule: open the break at least two dwellings ahead of the burning one, and only if the pull can finish before the fire reaches it; otherwise evacuate and wait for the fire service |
| A pulley or capstan to cut the crew? | Not in the base kit. A pulley needs a strong anchor that is rarely there; the kit uses ten hauling toggles instead |
| Shared walls? | The tool is used only on free-standing dwellings or the end unit of a row; rows with shared walls are outside its scope |
| Who stores and checks the kit? | The settlement committee, on a monthly check card: seal intact, pins and toggles present, no cracks in the tube, rope dry and unfrayed; a broken seal means a full check and a fresh proof load before reuse |

## Safety

> **Safety:** BreakHook is used to pull down a structure with a hook, a pole and a rope, near a fire. The hazards are a structure falling on people, a dwelling that is not empty, overhead and informal electrical wiring touching the metal hook or a wet rope, a rope or fitting breaking under load, heat and smoke, and crowds. The design answers with a pole that is withdrawn before anyone hauls, haulers at least 10 m away, a rated rope system proof-loaded before issue, an insulated pole length used only well away from wires, and a check card that must be completed before every pull. It is published as an open engineering reference, not certified equipment, and is used only within a community fire plan agreed with the local fire service.

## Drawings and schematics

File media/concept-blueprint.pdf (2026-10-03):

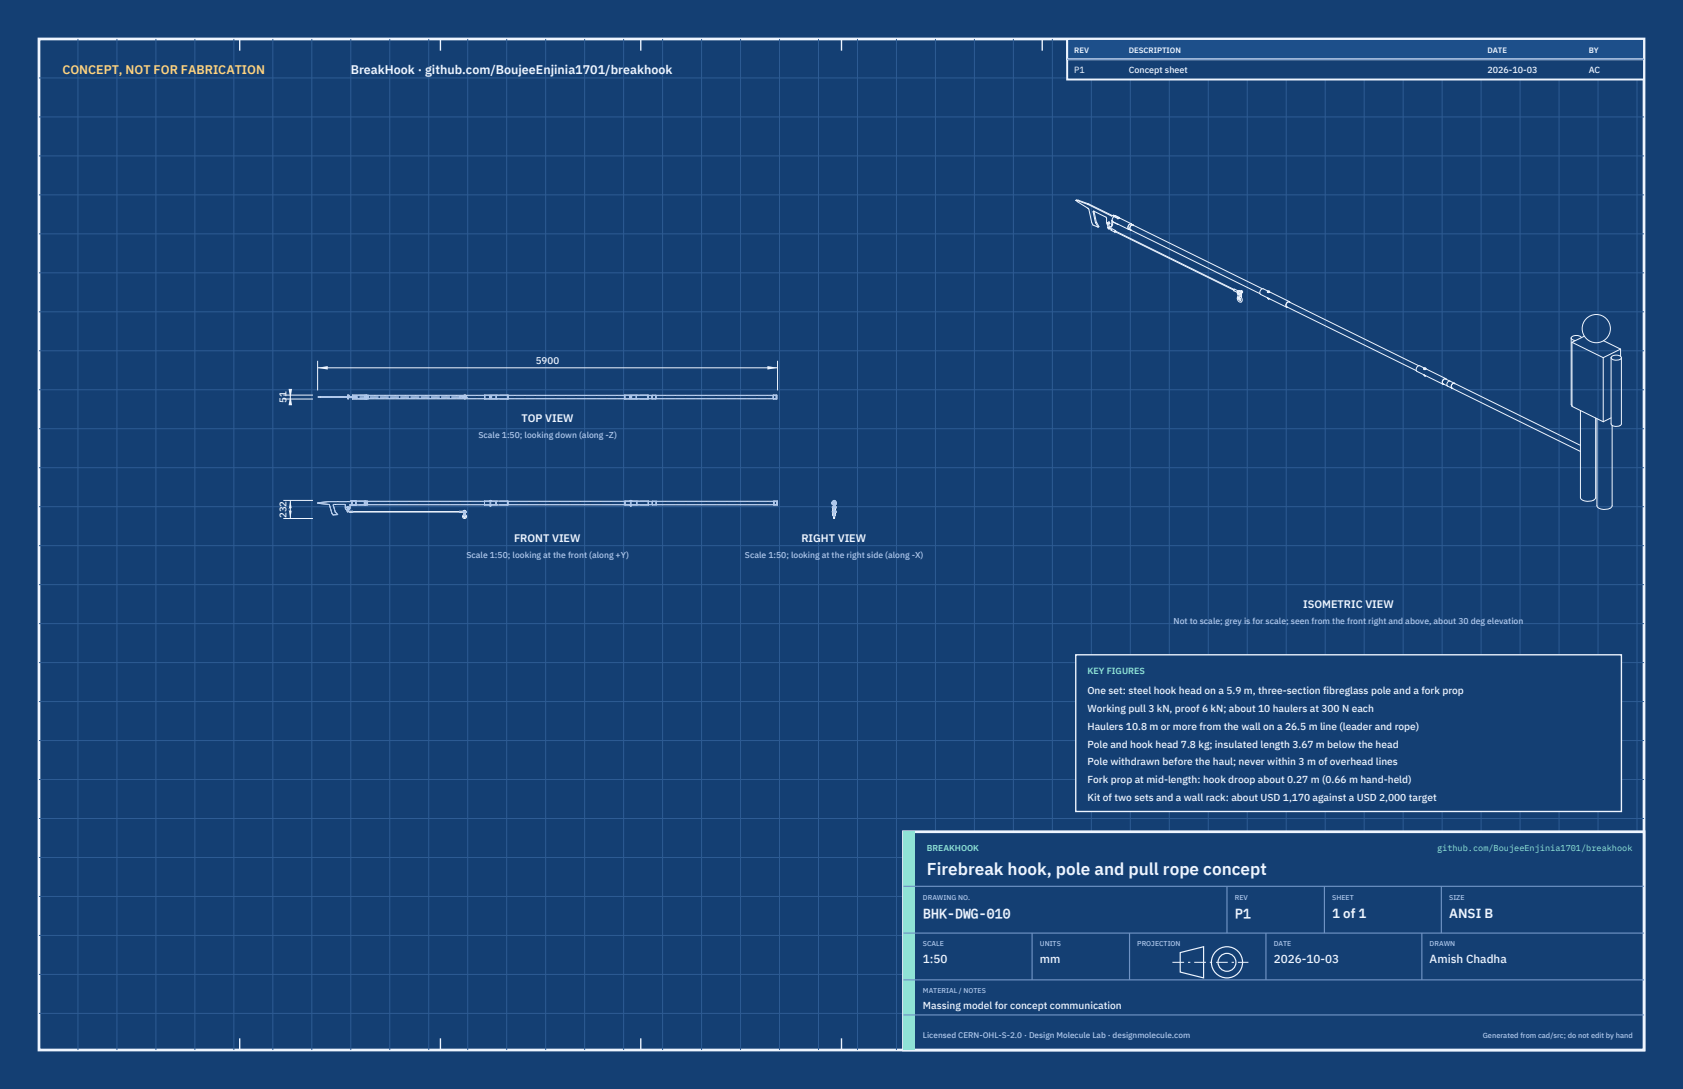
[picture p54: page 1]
CONCEPT, NOT FOR FABRICATION; BreakHook · github.com/BoujeeEnjinia1701/breakhook; FRONT VIEW; TOP VIEW; RIGHT VIEW; ISOMETRIC VIEW; REV; DESCRIPTION; DATE; Concept sheet; BREAKHOOK; github.com/BoujeeEnjinia1701/breakhook; DRAWING NO. BHK-DWG-010; REV P1; SHEET 1 of 1; SIZE ANSI B; SCALE 1:50; UNITS mm; PROJECTION; DRAWN Amish Chadha; Licensed CERN-OHL-S-2.0 · Design Molecule Lab · designmolecule.com; Generated from cad/src; do not edit by hand

Scale 1:50; looking down (along -Z)

Scale 1:50; looking at the front (along +Y)

Scale 1:50; looking at the right side (along -X)

Not to scale; grey is for scale; seen from the front right and above, about 30 deg elevation

KEY FIGURES
One set: steel hook head on a 5.9 m, three-section fibreglass pole and a fork prop
Working pull 3 kN, proof 6 kN; about 10 haulers at 300 N each
Haulers 10.8 m or more from the wall on a 26.5 m line (leader and rope)
Pole and hook head 7.8 kg; insulated length 3.67 m below the head
Pole withdrawn before the haul; never within 3 m of overhead lines
Fork prop at mid-length: hook droop about 0.27 m (0.66 m hand-held)
Kit of two sets and a wall rack: about USD 1,170 against a USD 2,000 target

Firebreak hook, pole and pull rope concept

MATERIAL / NOTES
Massing model for concept communication

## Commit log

2026-10-03 BreakHook at TRL 3: constructable design (kit 1.7.0)
    Problem, concept and requirements; sizing calculations; CAD model, STEP and STL; general arrangement drawing; bill of materials; build plan with making sketches, joint close-ups and step pictures; design decisions register (all decided under Amish's 2026-10-03 pre-approval); TRL 2 and TRL 3 review; photoreal renders and storefront card. Private until Amish opens it.
    [bom.csv, breakhook-assembly.step, hauling-toggle.step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]
2026-10-03 Carry Amish's 2026-10-03 requirement decisions into the design
    Amish chose option A on each requirement decision ("1A 2A 3A 4A 5A 6A 7A 8A 9A 10A 11A"). CampBreak: primed foot valve, pre-coupled suction hose and a drilled 30 s gather (R9 now 3.2 min at 100 m, me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
    [bom.csv, breakhook-assembly.step, fork-prop-plate.step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]
2026-10-04 Carry Amish's round-2 and round-3 decisions into the design
    Amish approved all 46 round-2 recommendations ("i agree with all the 46 recommendations you provided. please proceed.") and all round-3 recommendations ("For round 3, I agree with all your proposed r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

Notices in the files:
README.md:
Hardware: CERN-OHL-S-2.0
